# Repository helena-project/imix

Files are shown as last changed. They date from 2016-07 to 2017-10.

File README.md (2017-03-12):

imix
====

This open source, feature packed board is an all-in-one development kit for ultra 
low power Internet-of-Things research and prototyping. With a Cortex M4 microcontroller,
BLE/ANT and 802.15.4 radio modules, sensing, battery charging, and tons of I/O,
imix has everything you need to prototype and profile your next big IoT
breakthrough. Pair imix with the [Tock](http://github.com/helena-project/tock)
operating system to quickly develop secure embedded applications.

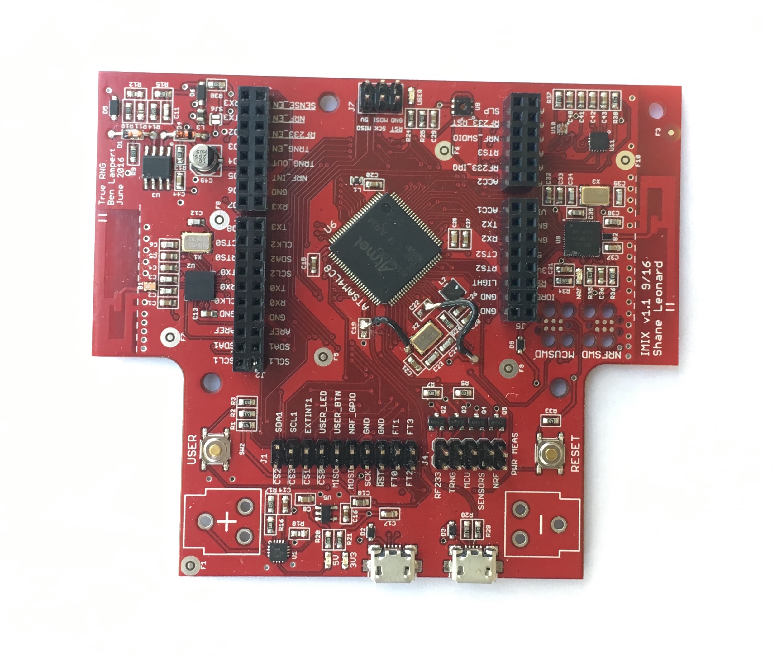
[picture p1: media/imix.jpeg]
imix


Features:
- Codeveloped with [Tock](http://github.com/helena-project/tock), a next-generation secure embedded operating system
- ATMEL SAM4L low power microcontroller with a Cortex M4 core
- NRF51422 radio with a Cortex M0 core for communication over Bluetooth Low Energy or ANT
- AT86RF233 radio for communication over 802.15.4
- Low power 3-axis linear accelerometer + 3-axis magnetometer
- Temperature + humidity sensor
- Digital light sensor
- Serial-to-USB and native USB ports
- Auditable True Random Number Generator
- Individually turn each subsystem completely on or off
- Easily measure the power consumption of each subsystem
- Compatible with most Arduino shields
- Integrated lithium polymer battery charger, and optional battery clips for the standard 18650 size

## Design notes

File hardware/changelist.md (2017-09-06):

v1.3:

* Removed ground plane near RF233 antenna
* Analog switch added as isolator for RF233 SPI and sense/NRF I2C
* Resistor added between FTDI_DTR and !RESET
* Battery charger configured for 500mA operation
* VHIGHSAMPLE from TRNG routed to ADCIFE6
* Reassigned A0-5 from ADCIFE1-6 to ADCIFE0-5
* GPIO8 reassigned to PA20
* LIGHT_INT reassigned to PC25
* Added KERNEL LED
* Overhaul of imix.lbr (documentation layers)
* Used P/N M20-9980545 for J4

v2.1:

* Form factor: now a 2.5"X4" rectangle
* Removed battery circuit
* FTDI chip powered correctly for low power
* Removed unnecessary resistors
* Renumbered some resistors and capacitors
* Changed pull-ups to 10K from 4.7K
* Removed unnecessary battery charger IC
* Removed all power gates except TRNG
* Removed header 1 and reassigned pins to the other headers
* Shunts instead of cutting traces
* Rearranged pinout on headers to simplify layout
* JST battery connector instead of battery clips
* Minor pinout changes on the MCU
* Cheaper diodes for power input
* Nicer more clicky buttons
* Power LEDs on the USB and nowhere else
* Trace width increased to 8 mil
* SPI header removed
* Debug USB moved to opposite side of board
* Mounting holes in a 2"X3.75" rectangle
* Extra SPI header removed
* Populate the sense resistors for TRNG
* Nicer silkscreen with TockOS and Imix urls

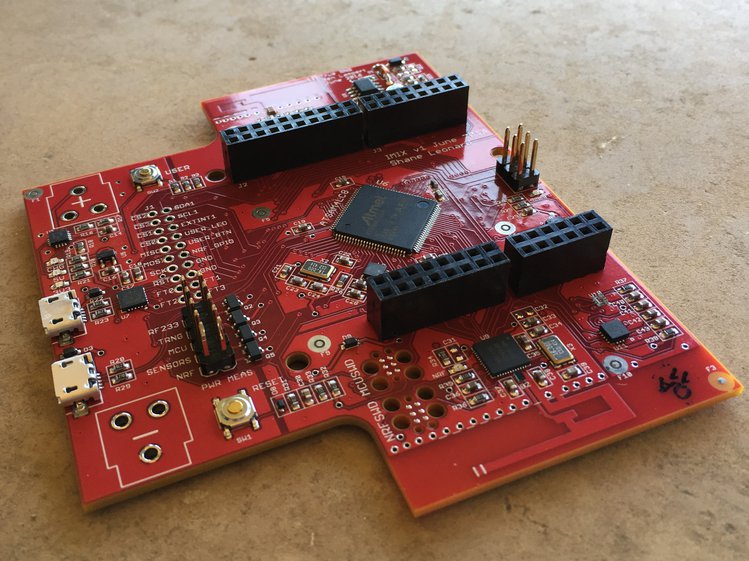
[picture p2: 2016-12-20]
media/imix-on-table.jpg

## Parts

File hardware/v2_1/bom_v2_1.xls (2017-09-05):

BOM: Imix
Assembly Part Number/Revision: 2.1
Customer / Company Name: Stanford University
Item # | Quantity per board | Manufacturer Part # | Do Not Install | Reference designators | Vendor | Vendor Part Number | Part description/ specs | Manfacturer
1 | 1 | 2450BM15A0015E |  | B1 | Digi-Key | 712-1576-1-ND | AT86RF232 AT86RF233 ATMEGA256 | JOHANSON TECHNOLOGY INC (VA)
2 | 1 | BALF-NRF01D3 |  | B2 | Digi-Key | 497-14944-1-ND | BALUN ULTRAMINI 5FLIPCHIP | STMICROELECTRONICS (VA)
3 | 19 | CC0603KRX7R7BB104 |  | C1,C4,C14,C15,C17,C19-C22,C27-C29,C31-C33,C40-C43 | Digi-Key | 311-1088-1-ND | CAP CER 0.1UF 16V X7R 0603 | YAGEO (VA)
4 | 3 | C0603C220J1GACTU |  | C2,C3,C11 | Digi-Key | 399-7874-1-ND | CAP CER 22PF 100V NP0 0603 | KEMET (VA)
5 | 4 | CC0603ZRY5V7BB105 |  | C5,C13,C16,C30 | Digi-Key | 311-1372-1-ND | CAP CER 1UF 16V Y5V 0603 | YAGEO (VA)
6 | 6 | C1608C0G1H090D080AA |  | C6,C12,C23,C24,C34,C39 | Digi-Key | 445-5047-1-ND | CAP CER 9PF 50V C0G 0603 | TDK CORPORATION (VA)
7 | 4 | GRM188R71E474KA12D |  | C7,C44,C46,C47 | Digi-Key | 490-3291-1-ND | CAP CER 0.47UF 25V X7R 0603 | MURATA ELECTRONICS (VA)
8 | 2 | CL10B475KQ8NQNC |  | C8,C25,C48 | Digi-Key | 1276-2087-1-ND | CAP CER 4.7UF 6.3V X7R 0603 | SAMSUNG ELECTRO-MECHANICS AMERICA, INC (VA)
9 | 1 | EEE-1EA100WR |  | C10 | Digi-Key | PCE3895CT-ND | CAP ALUM 10UF 20% 25V SMD | PANASONIC ELECTRONIC COMPONENTS (VA)
10 | 1 | CL10A106MQ8NNNC |  | C18 | Digi-Key | 1276-1119-1-ND | CAP CER 10UF 6.3V X5R 0603 | SAMSUNG ELECTRO-MECHANICS AMERICA, INC (VA)
11 | 1 | C1608X5R0J685K080AB |  | C26 | Digi-Key | 445-7490-1-ND | CAP CER 6.8UF 6.3V X5R 0603 | TDK CORPORATION (VA)
12 | 2 | CL10C102JB8NFNC |  | C35,C38 | Digi-Key | 1276-2170-1-ND | CAP CER 1000PF 50V NP0 0603 | SAMSUNG ELECTRO-MECHANICS AMERICA, INC (VA)
13 | 1 | GCM188R71H473KA55D |  | C36 | Digi-Key | 490-4934-1-ND | CAP CER 0.047UF 50V X7R 0603 | MURATA ELECTRONICS (VA)
14 | 1 | CL10B222KB8SFNC |  | C37 | Digi-Key | 1276-1992-1-ND | CAP CER 2200PF 50V X7R 0603 | SAMSUNG ELECTRO-MECHANICS AMERICA, INC (VA)
15 | 2 | 1N759A TR |  | D1,D4 | Mouser | 610-1N759A | Zener Diodes 12V .5W | CENTRAL SEMICONDUCTOR
16 | 8 | MBR0530 |  | D2-D9 | Digi-Key | MBR0530CT-ND | DIODE SCHOTTKY 30V 500MA SOD123 | FAIRCHILD SEMICONDUCTOR (VA)
17 | 1 | S2B-PH-SM4-TB |  | J1 | Digi-Key | 455-1749-1-ND | CONN HEADER PH SIDE 2POS 2MM SMD | JST SALES AMERICA INC.
18 | 1 | PPPC102LFBN-RC |  | J2 | Digi-Key | S6106-ND | CONN HEADER FEM 20POS.1" DL GOLD | SULLINS CONNECTOR SOLUTIONS
19 | 2 | PPPC082LFBN-RC |  | J3,J5 | Digi-Key | S7111-ND | CONN HEADER FMAL 16PS.1" DL GOLD | SULLINS CONNECTOR SOLUTIONS
20 | 1 | M20-9980545 |  | J4 | Digi-Key | 952-2380-ND | 2X5POS DIL VERTICAL PIN HEADER | HARWIN INC
21 | 1 | PPPC062LFBN-RC |  | J6 | Digi-Key | S7109-ND | CONN HEADER FMAL 12PS.1" DL GOLD | SULLINS CONNECTOR SOLUTIONS
22 | 1 | BLM18HE152SN1D |  | L1 | Digi-Key | 490-5216-1-ND | FERRITE BEAD 1.5 KOHM 0603 1LN | MURATA ELECTRONICS (VA)
23 | 1 | LQH3NPN220MJ0L |  | L2 | Digi-Key | 490-5350-1-ND | FIXED IND 22UH 510MA 600 MOHM | MURATA ELECTRONICS (VA)
24 | 1 | LBR2012T100K |  | L3 | Digi-Key | 587-2045-1-ND | FIXED IND 10UH 150MA 360 MOHM | TAIYO YUDEN (VA)
25 | 3 | LTST-C191KFKT |  | LED1,LED4 ,LED5 | Digi-Key | 160-1445-1-ND | LED ORANGE CLEAR 0603 SMD | LITE-ON INC (VA)
26 | 2 | LTST-C193TBKT-5A |  | LED2,LED3 | Digi-Key | 160-1827-1-ND | LED BLUE CLEAR 0603 SMD | LITE-ON INC (VA)
27 | 10 | RC0603JR-0710KL |  | R1-R3,R6-R8,R16,R18,R25,R26 | Digi-Key | 311-10KGRCT-ND | RES SMD 10K OHM 5% 1/10W 0603 | YAGEO (VA)
28 | 5 | RC0603JR-07220RL |  | R4,R5,R17,R19,R24 | Digi-Key | 311-220GRCT-ND | RES SMD 220 OHM 5% 1/10W 0603 | YAGEO (VA)
29 | 3 | ERA-3AEB103V |  | R9,R10,R13 | Digi-Key | P10KDBCT-ND | RES SMD 10K OHM 0.1% 1/10W 0603 | PANASONIC ELECTRONIC COMPONENTS (VA)
30 | 1 | RC0603JR-07150KL |  | R11 | Digi-Key | 311-150KGRCT-ND | RES SMD 150K OHM 5% 1/10W 0603 | YAGEO (VA)
31 | 1 | RC0603JR-0730KL |  | R12 | Digi-Key | 311-30KGRCT-ND | RES SMD 30K OHM 5% 1/10W 0603 | YAGEO (VA)
32 | 1 | RC0603JR-072M2L |  | R14 | Digi-Key | 311-2.2MGRCT-ND | RES SMD 2.2M OHM 5% 1/10W 0603 | YAGEO (VA)
33 | 1 | RC0603JR-07160KL |  | R15 | Digi-Key | 311-160KGRCT-ND | RES SMD 160K OHM 5% 1/10W 0603 | YAGEO (VA)
34 | 4 | RC0603JR-0727RL |  | R20-R23 | Digi-Key | 311-27GRCT-ND | RES SMD 27 OHM 5% 1/10W 0603 | YAGEO (VA)
35 | 5 | SPC02SYAN | DNI | SHUNTS | Digi-Key | S9001-ND | 2 POS 0.1" CONN JUMPER SHORTING GOLD FLASH | SULLINS CONNECTOR SOLUTIONS
36 | 2 | PTS645SM43SMTR92 LFS |  | SW1,SW2 | Digi-Key | CKN9112CT-ND | Blue Tactile Switch SPST-NO Top Actuated Surface Mount 12V 0.5A | C&K COMPONENTS (VA)
37 | 2 | 74LVC4066BQ |  | U1,U13 | Digi-Key | 568-3019-1-ND | 4 channel bilateral switch | NEXPERIA USA INC.
38 | 1 | AT86RF233-ZUR |  | U2 | Digi-Key | AT86RF233-ZURCT-ND | IC RF TXRX+MCU 802.15.4 32-VFQFN | ATMEL (VA)
39 | 1 | TLV3202AIDR |  | U3 | Digi-Key | 296-34773-1-ND | IC COMPARATOR RRI DUAL 8SOIC | TEXAS INSTRUMENTS (VA)
40 | 1 | LM358DT |  | U4 | Digi-Key | 497-1591-1-ND | IC OPAMP GP 1.1MHZ 8SO | STMICROELECTRONICS (VA)
41 | 1 | TPS78233DDCR |  | U5 | Digi-Key | 296-24059-1-ND | IC REG LDO 3.3V 0.15A 5SOT | TEXAS INSTRUMENTS (VA)
42 | 1 | ATSAM4LC8CA-AU |  | U6 | Digi-Key | ATSAM4LC8CA-AU-ND | IC MCU 32BIT 512KB FLASH 100TQFP | ATMEL
43 | 1 | FT231XQ-R |  | U7 | Digi-Key | 768-1128-1-ND | IC USB SERIAL FULL UART 20QFN | FTDI (VA)
44 | 1 | SI7021-A20-GM |  | U8 | Digi-Key | 336-3140-5-ND | IC TEMP SENSOR RH 3% 6DFN | SILICON LABORATORIES INC
45 | 1 | nRF51422-QFAC-R7 |  | U9 | Mouser | 949-NRF51422-QFAC-R7 | RF System on a Chip - SoC QFN48pkt 256kB Flash 32kB RAM XLR3 | NORDIC SEMICONDUCTOR ASA (VA)
46 | 1 | ISL29035IROZ-T7 |  | U10 | Digi-Key | ISL29035IROZ-T7CT-ND | IC PROXIMITY SENSOR AMB LT 6ODFN | INTERSIL (VA)
47 | 1 | FXOS8700CQR1 |  | U11 | Digi-Key | FXOS8700CQR1CT-ND | SENSOR XTRINSIC 6-AXIS QFN | FREESCALE SEMICONDUCTOR - NXP (VA)
48 | 1 | TPS61041DBVR |  | U12 | Digi-Key | 296-12686-1-ND | IC LED DRIVER RGLTR DIM SOT23-5 | TEXAS INSTRUMENTS (VA)
49 | 1 | SIP32401ADNP-T1GE4 |  | U14 | Digi-Key | SIP32401ADNP-T1GE4CT-ND | 1 channel load switch | VISHAY ELECTRONICS
50 | 2 | 10118192-0001LF |  | USB1,USB2 | Digi-Key | 609-4613-1-ND | CONN USB MICRO B RECPT SMT R/A | AMPHENOL FCI (VA)
51 | 3 | 405C11A16M00000 |  | X1,X2,X3 | Digi-Key | CTX834CT-ND | CRYSTAL 16.0000MHZ 10PF SMD | CTS-FREQUENCY CONTROLS

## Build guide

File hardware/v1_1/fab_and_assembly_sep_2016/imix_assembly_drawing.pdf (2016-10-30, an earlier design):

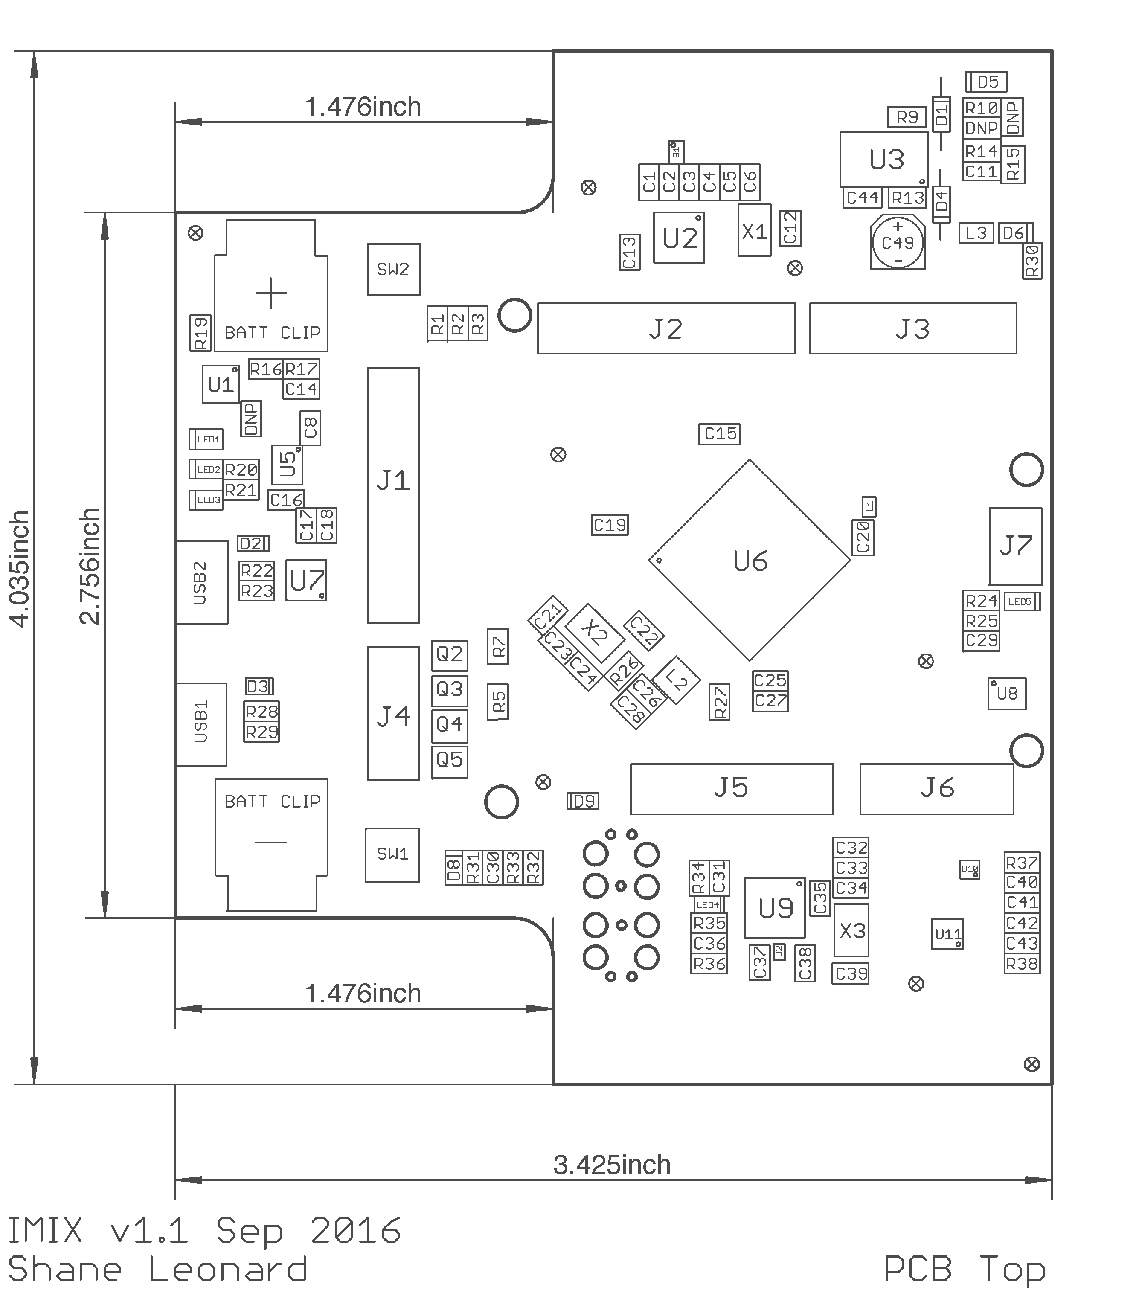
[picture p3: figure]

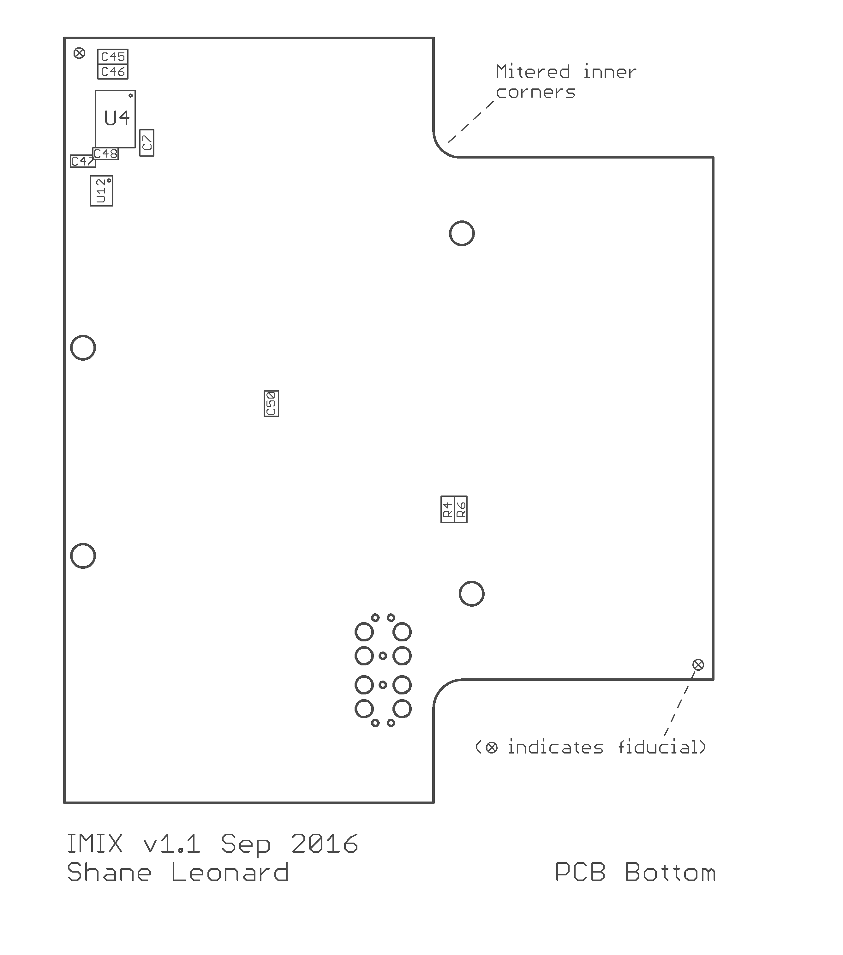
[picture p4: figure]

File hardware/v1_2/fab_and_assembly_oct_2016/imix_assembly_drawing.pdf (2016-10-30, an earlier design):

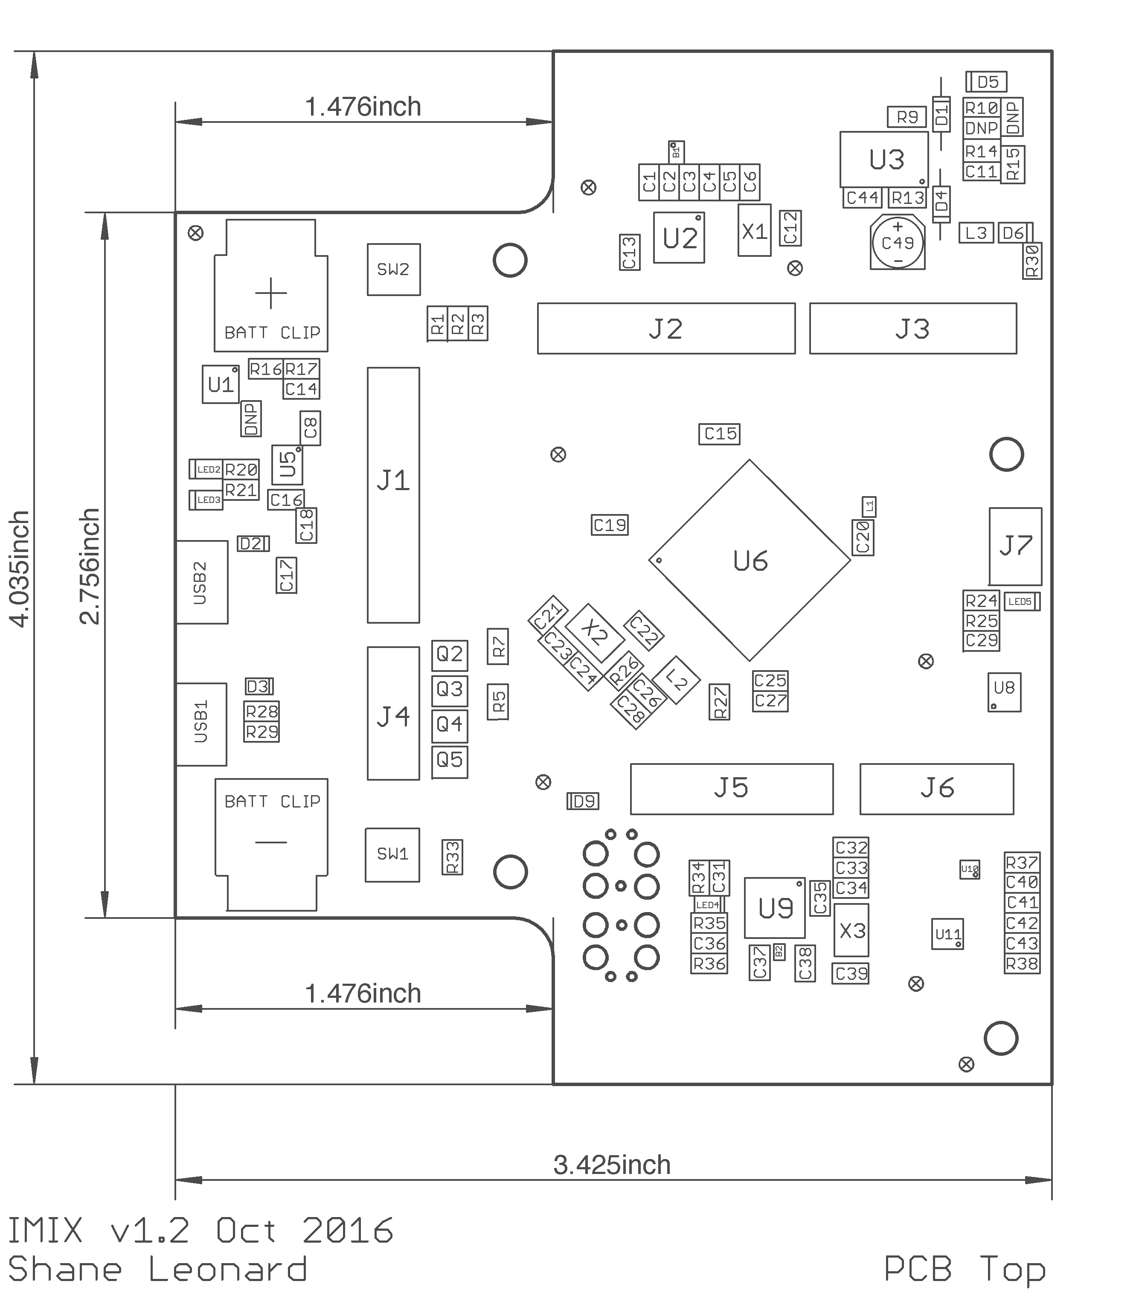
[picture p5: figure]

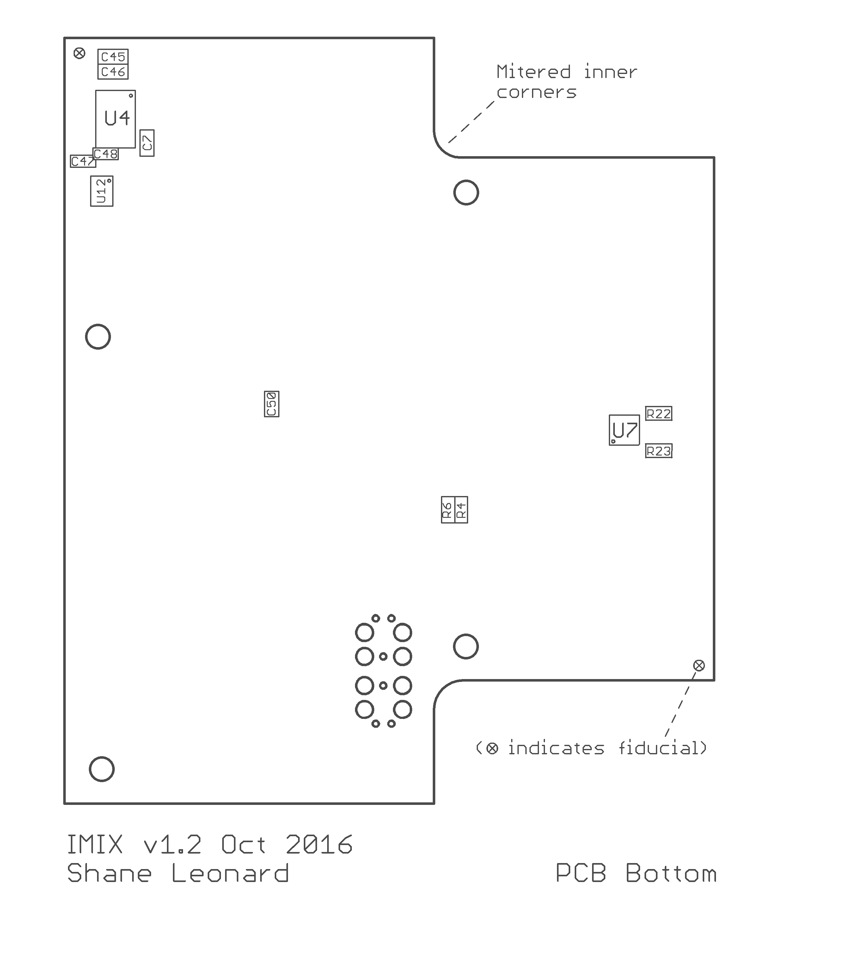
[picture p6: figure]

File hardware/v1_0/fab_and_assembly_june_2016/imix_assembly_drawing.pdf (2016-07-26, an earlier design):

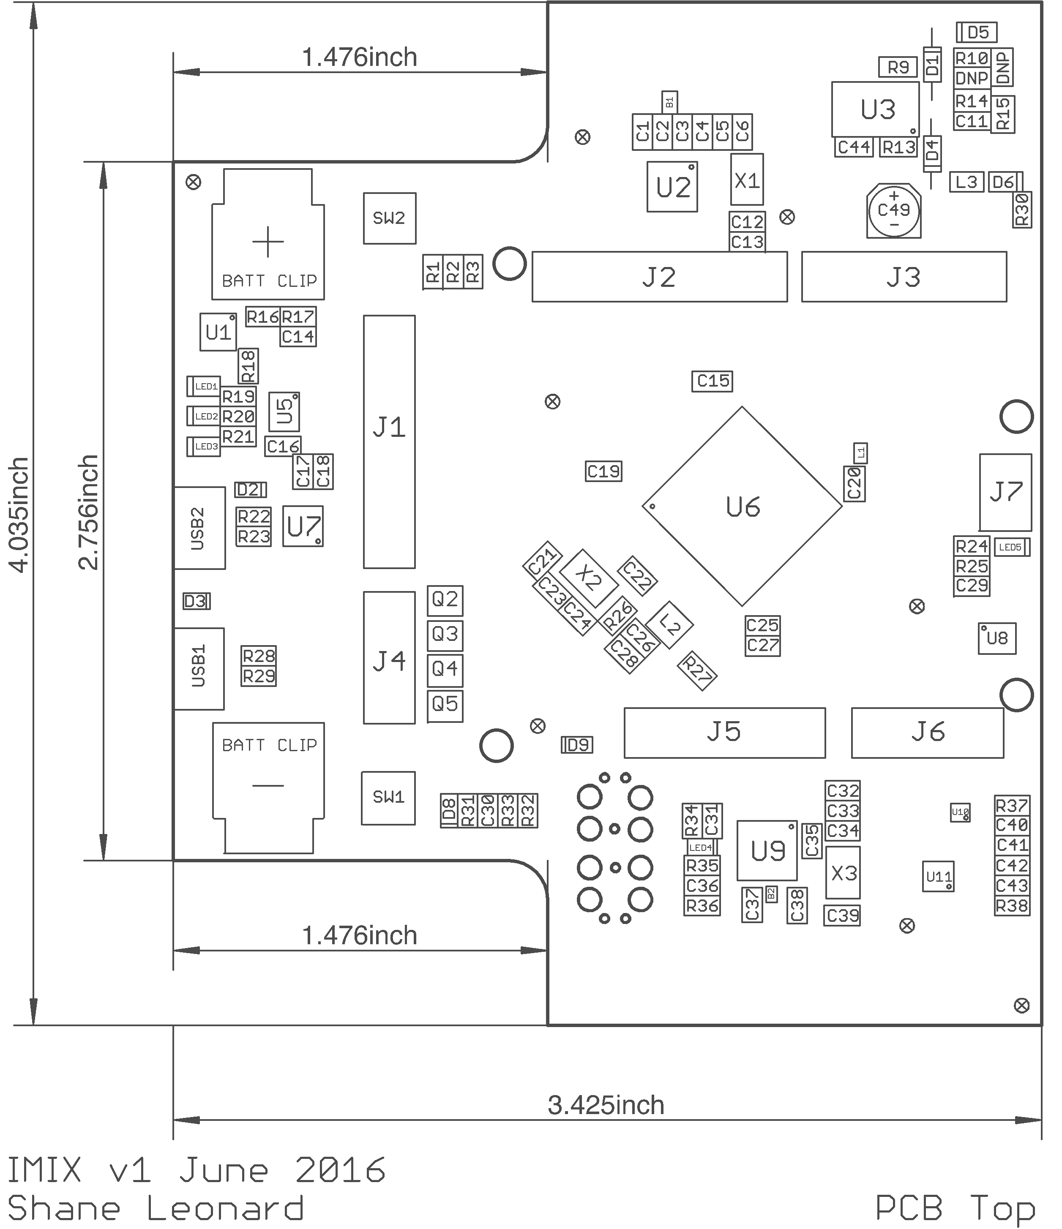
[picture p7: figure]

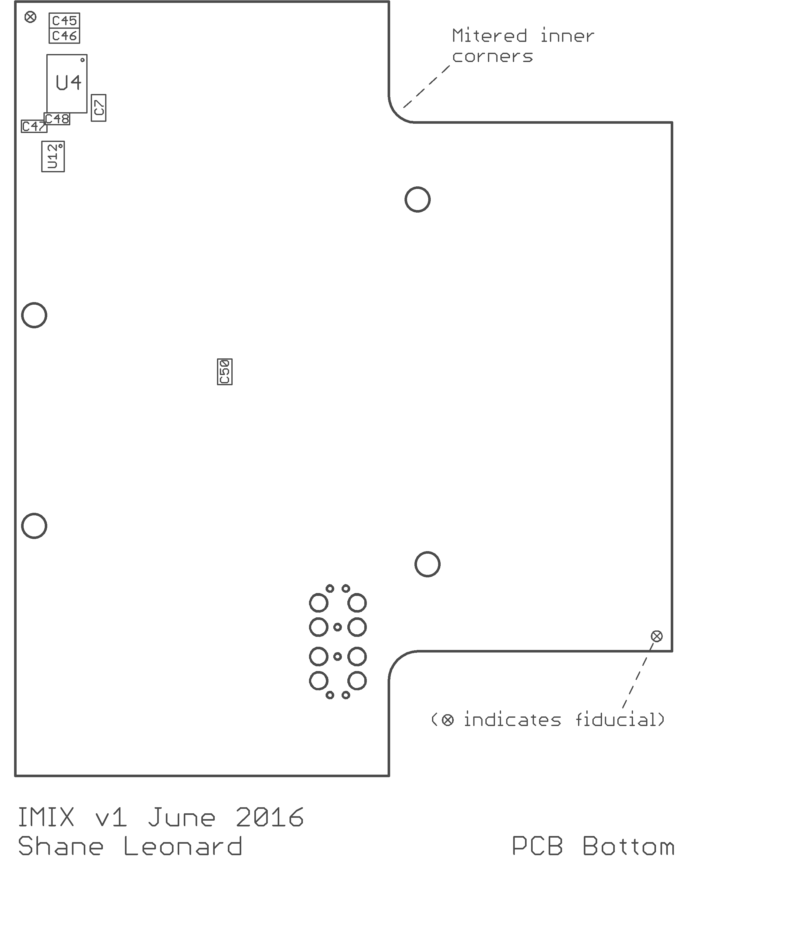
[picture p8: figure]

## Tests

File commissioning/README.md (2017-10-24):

Commissioning
=============

This folder contains resources for setting up new imix boards.

Commissioning Overview
----------------------

The commissioning process covers a few things:

1. Set the FTDI device name and serial number.
2. Flashes the boatloader on to the SAM4L.
3. Sets the `board`, `id` and `appaddr` attributes in the flash of the SAM4L.
4. Flashes the `imix` TockOS kernel on the SAM4L.
5. Flashes the "blink" app on the SAM4L.
6. Flashes the serialization code on the nRF51 and programs the ID.

Initial software installation
-----------------------------

To initialize a Hail board:

 * Connect USB to the board
 * Connect a JTAG programmer to the SAM4L
 * Run `./commission_new_imix.sh c098e514xxxx` where the `xxxx` should be
   replaced with a unique device ID
 * Connect a JTAG programmer to the nRF51822
 * Hit `any key` to continue the script

Be sure to label the board with a sticker so that the user knows what the
device's BLE address is.

`ftx_prog`
----------

The `ftx_prog` executable comes from here:
https://github.com/richardeoin/ftx-prog.
It was built for linux amd64, so if the executable doesn't work for you,
you will have to recompile it for your platform.

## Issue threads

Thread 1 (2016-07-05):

FT231 Reset Functionality

alevy, 2016-07-05:
On the Firestorm, the FT231's DTR pin is tied to logic that allows flipping the power to the board. On the Imix currently _DTS_ is tied to the SAM4L reset. Is that right? Isn't DTS an input pin for the FTDI chip?

shaneleonard, 2016-07-05:
You are correct, thank you for catching this! I've updated the connections so that DTR is now connected to reset.

Closed 2016-07-05.

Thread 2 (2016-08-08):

Power LEDs don't come on

alevy, 2016-08-08:
## Cause

This issue is due to a lack of bypass capacitance on the output of the bq24230 (the battery charger and power path IC).
Without a high capacitance on the output, the IC is unstable and does not produce a regulated output voltage.
## Workarounds

The general principle is to add a suitable bypass capacitor to the output of the bq24230 (U1).
There are several ways to achieve this:
1. Plug in the device. With the board face up and oriented like a capital 'T', touch
   the leads of a large (4.7uF to 47uF) capacitor from GND to the upper pad of either R19 or R20.
   The LEDS should immediately turn on, and the 3.3V power rail should be working.
   Note that because the capacitor is not permanently attached, the power supply may
   occasionally become unstable again, and the process must be repeated.
2. (recommended) Remove R18 and R19. With the board face up and oriented like a capital 'T',
   solder a large (4.7uF to 47uF) capacitor from the rightmost pad of R18 to the upper pad of R19.
   An 0603 capacitor is ideal if possible, since it happens to be the perfect dimensions to bridge the gap.
3. (untested) If no suitable capacitor is on hand, it should be possible to directly apply an input
   voltage that bypasses the power path IC. Solder a wire to the upper pad of R19 (R19 can be removed if desired).
   The input voltage at this point should be between 3.4 V and 5.5 V. The chances of this method succeeding are
   higher if the bq24230 (U1) is removed, and a 0.1uF to 1uF bypass capacitor is applied on the input rail.

shaneleonard, 2016-08-11:
@alevy Were you able to test any of these workarounds yourself?

alevy, 2016-08-11:
@shaneleonard I have not. I don't have a workbench nearby me, but I'll head into a hacker space sometime soon. I was able to get the LED powered through the JLink connection though -- e.g. when I connect the programmer to and configure it to power the MCU, the LED lights up

shaneleonard, 2016-08-11:
@alevy FWIW, decent soldering irons are $10 at RadioShack, if that's more convenient than going to a hacker space. Otherwise, I could send you one of the boards that I've fixed up. If you were able to power the processor through the JLink, then the only thing preventing you from being able to program the MCU is D8, which shouldn't be too hard to remove with a soldering iron and a reasonably steady hand. When I get the chance, tonight I'll upload my openocd script and a simple blinky app.

shaneleonard, 2016-08-12:
@alevy Uploaded detailed 'getting started' instructions. It turns out that D8 is actually inconsequential. Please take a look at issue #3 and the README for the correct procedure. I've verified this procedure with a totally fresh board, so it should work for you. No need for anything except a JLink and a razor blade.

alevy, 2016-08-12:
Awesome. I'll try it out ASAP

alevy, 2016-08-13:
@shaneleonard I'm able to program the board with your blink app and it works!!

For the record, to get started I need:

  1. Plug USB one of the ports (it doesn't have to be plugged into a power source on the other end_

  2. Provide power from JLink

From that point I can either remove the USB cable and it works fine, or provide power from the USB and stop powering from the JLink. As though the USB + Jlink connectivity is only need to jump-start the process.

alevy, 2016-08-13:
The FTDI chip isn't showing up, but I assume that's related to the short

shaneleonard, 2016-08-13:
@alevy Yay! Did you need to cut the trace? I'm still not exactly sure what the issue is with the FTDI chip. I have one board which I had removed the FTDI from, and the short disappeared, so I have a feeling that there may actually be a different issue with it than I originally thought. How do you configure the JLink to provide power?

alevy, 2016-08-13:
I did have to cut the trace.
I'm not sure how to do it from openocd, but from JLinkExe just use the command `power on`.

Closed 2016-11-18.

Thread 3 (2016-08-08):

MCU Reset line is permanently low

alevy, 2016-08-08:
## Cause

Reset line on the FTDI side is shorted to ground in an internal layer. :(
## Workaround

Cut the trace as shown below so that the FTDI side is disconnected from the MCU side. This will allow the MCU to be programmed using a JLink.

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

shaneleonard, 2016-08-12:
@alevy It turns out this issue was not due to the diode, but actually due to RESET being shorted to ground near the FTDI chip. The internal ground plane near the FTDI does not have the proper isolation, so it appears to have shorted to the RESET vias. Fortunately, however, this means that the board can actually be completely programmed and powered without adding or removing any components. All that is needed is to cut the trace as shown above.

Closed 2016-11-18.

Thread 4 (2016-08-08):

Tag Connect programmer cannot drive the reset line

alevy, 2016-08-08:
## Cause

It is suspected that the solder on the pads of the connector negatively impact the connection enough to
prevent the programmer from sinking enough current to drive the reset line low.

## Workaround

Currently unknown.

alevy, 2016-08-08:
Is it possible to validate this somehow? E.g. by measuring how much current can be drawn through the pad?

FWIW, this seems to _not_ be an issue with the NRF's programming -- at least, I can successfully connect to that chip using my debugger.

alevy, 2016-08-08:
Side question, is this issue dependent somehow on #3? In particular, I haven't yet removed D8 -- will that potentially effect the behavior I see when trying to use the programmer pads?

shaneleonard, 2016-08-11:
@alevy Were you able to connect to the NRF on this revision of Imix?

shaneleonard, 2016-08-11:
@alevy I tried using the same programmer to flash one of my original boards, and encountered the same error. Therefore I suspect that it's actually an issue with my programmer or the toolchain, since the board I'm testing worked earlier this year. I will try using openocd instead of the Atmel toolchain and see what happens. If you are able to resolve issue #2, can you try programming your board and see if it works? You still need to remove D8 because it affects the voltage on the reset line

shaneleonard, 2016-08-11:
@alevy Turns out, the error was Atmel Studio incorrectly configuring the JLink. Using openocd I was able to program the board.

alevy, 2016-08-11:
@shaneleonard I _was_ able to connect to the NRF on this revision of Imix but was not able to connect to the SAM4L - kept getting errors from JLinkExe about not being able to reset the chip. If you were able to though, my guess is that error has to do with the other issues on the board, which I haven't resolved on mine with your workarounds.

Could you post your openocd config files somewhere (this repo) if/when you have a chance? Would be good to switch to it from JLink (since it's open source and easier to install).

Closed 2016-08-11.

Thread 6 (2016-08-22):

Add Bill of Materials to repo

brghena, 2016-08-22:

shaneleonard, 2016-08-24:
Uploaded the BOM I had sent to the manufacturer. There were several minor changes to the BOM during the manufacturing process, so I will update these changes soon.

Closed 2016-08-24.

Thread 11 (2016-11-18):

Re-enable RF233 enable pin

alevy, 2016-11-18:
In the current revision, the RF233 enable pin is tied to ground because of an original misdiagnosis of #7. Since that's now fixed we should re-establish the SAM4L's control over the RF233's enable pin.

  - [x] Test that controlling the enable pin from the SAM4L no longer browns out the SAM4L

  - [ ] ~~If it works, remove the trace/resistor grounding the enable pin.~~

alevy, 2016-12-22:
In my experiments with an older board --- one without RF233_EN tied to ground, but with the power-related patch wires --- this still does not work. I believe @shaneleonard thinks this is related to the problem in #12 and the same fix might apply.

shaneleonard, 2017-03-12:
Closing as this issue is now tracked by #14

Closed 2017-03-12.

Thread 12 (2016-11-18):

RNG enable browning out sam4l

alevy, 2016-11-18:
From my test, enabling the RNG (by clearing PC19 on the SAM4L) browns out the SMA4L on a patched board of the most recent revision. @shaneleonard any suggestions on how to diagnose further? It might be worth you trying replicate as well, since it's definitely plausible I'm doing something wrong (I just enabled PC19 as an output then cleared it. If I set it instead, no problems--but also no RNG of course).

alevy, 2016-11-21:
I actually think this may have happened because the my power supply (a passive USB hub) wasn't supplying enough power. It should be able to do up to 100uA, which very well might be less than the two MCUs + the RF233 + the RNG + the sensors on boot. I'm going to try and test this today.

alevy, 2016-11-21:
OK, I'm able to run the RNG and continue with the OS as normal as long as I'm powering the board from two USB sources (currently the FTDI as well as power through the JLink). Ideally I would try this with an independently powered USB hub, but I don't have one on me. I should also try this with a large power supply...

However, this doesn't seem like great behavior if we can't power the board from a typical USB port.

@shaneleonard does this seem like my analysis is reasonable? If so, would it make sense to stick a current limiting resistor or something inline with the RNG power supply?

/cc @kwantam

ppannuto, 2016-11-21:
I thought you had to be able to supply 500 mA to be USB compliant (even a
"passive hub" ?).

Not that lowering the power draw is a bad idea, but it may also be good to
have the FTDI chip negotiate for more power:
http://www.ftdichip.com/Support/Documents/TechnicalNotes/TN_113_Simplified%20Description%20of%20USB%20Device%20Enumeration.pdf
 (from
http://electronics.stackexchange.com/questions/5498/how-to-get-more-than-100ma-from-a-usb-port
 )

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

shaneleonard, 2016-11-21:
So the device actually regulating the power is the BQ24230, which is currently configured to be in USB 100 mA mode. By setting the EN1 pin high instead of low, it can be used for 500mA (the BQ24230 doesn't actually negotiate for more power--like Pat said, that's the FTDI's job--all it does is limit the power input). According to Ben, the RNG draws a 30 mA average current, but it looks like it actually spikes above that level at some points. I would guess that the average current draw is <100mA but the peak current draw is >100mA.

So it looks like I should change EN1 on the BQ24230 to be high so that it limits the input current to 500mA instead of 100mA, and the SAM4L needs to get the FTDI chip to negotiate for more power. This also means that the RNG won't work with the native USB port (eg the non-FTDI one)  until the Tock native USB driver is capable of device enumeration/negotiation for more power.

For now, there are a couple of workarounds. First, if the RNG only requires _slightly_ more than 100mA, the BQ24230 might let it slide (it has some built in wiggle room for charging capacitive loads). It's possible that just setting the FTDI chip to negotiate for 500mA could be enough to fix the problem.

Otherwise, if you're able to directly power the 3V3 line with something capable of >100mA (at 3.3V, NOT 5V), then you are bypassing the regulator entirely, and so the input current limits won't apply. Note that it's necessary to power VCC_3V3, not just VCC_MCU_3V3 (what the JLink powers), because otherwise the RNG has no power.

shaneleonard, 2016-11-21:
Also @ppannuto is right that every USB-compliant host must be capable of 500mA.

shaneleonard, 2016-11-21:
Another possible workaround is to power the board from the battery input, because the BQ24230 doesn't limit the input battery current

ppannuto, 2016-11-21:
I think in practice you can just set the BQ to 500 mA mode and everything
will work out.

Very few USB ports actually limit downstream stuff to 100 mA nowadays.

On Mon, Nov 21, 2016 at 5:33 PM shaneleonard <notifications@github.com>
wrote:

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

alevy, 2016-11-21:
Just setting the FTDI to negotiate 500mA doesn't seem to do the trick (which seems like it's because of the BQ24230 limiting @shaneleonard pointed out).

It's true that USB-compliant hosts should be able to provide 500mA, but hubs are only required to provide 100mA. What is a hub? Undefined... the plugs on your desktop may be hubs, or they may be directly connected to the host.

Ideally (this is purely from a usability perspective), you should be able to run the board on any of the power sources, including from a non-FTDI USB. If it's possible to easily adapt the hardware to a 100mA power constraint (e.g. a current limiting resistor on the RNG or a capacitor to smooth out peak consumption) that's great. If not, as long as we have a software workaround that's probably good enough to move forward.

alevy, 2016-11-21:
Is fixing the BQ something I can test myself?

alevy, 2016-11-21:
BTW, @shaneleonard setting the FTDI to negotiate more power is done by programming the user-flash on the FTDI chip from a host machine (using a windows program called FT_PROG). I don't think it's possible from the SAM4L.

kwantam, 2016-11-21:
As @alevy says, the right solution is to modify the dc/dc converter's design so that its inrush current is limited to less than 100 mA. I'll have to take a look at our schematic and the datasheet for the part we're using before I can make a specific suggestion, but in general there's no reason that keeping the converter's peak current below 100 mA is tough.

Ideally, in the long term, I'd like to replace the controller we've got now with something cheaper. The TI product line we're using is optimized for "drop it in and don't worry," but we can easily do better in terms of cost and performance with a bit more thought.

ppannuto, 2016-11-21:
@alevy to test the BQ, need to set EN2=0, EN1=1 ( http://www.ti.com/lit/ds/symlink/bq24230.pdf ). EN1 is pin 6, which unfortunately will be a hard trace to cut:
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

@shaneleonard one nice habit for the future is the eliminate traces between pads. For this reason, and also so because they tend to encourage solder bridges, which, while technically not wrong, make debugging board fab hard b/c you have to recognize that that bridge is okay.

@shaneleonard also, can you include the `.brd` and `.sch` files in the fab directories in the future? It's nice to have a snapshot of those so you can open a digital copy of exactly that rev of a board.

alevy, 2016-11-21:
Oh, btw, when I feed enough power to the board I can successfully read random looking bits of the RNG. I'm not rigorously measuring time or anything, so the bits I'm getting are probably not exactly random, but definitely close enough to be sure the hardware does what it's supposed to do once we turn it on.

shaneleonard, 2016-11-21:
@ppannuto Thanks for the tip, I had corrected the 'traces between pads' mistake on the SAM4L but had missed it on the BQ24230. Would it be valuable to have a DNP pullup/pulldown on EN1 and EN2, or is it better to just tie EN1 high?

shaneleonard, 2016-11-21:
@ppannuto I'll make sure to do `.brd` and `.sch` snapshots moving forward

shaneleonard, 2016-11-21:
@alevy Does feeding enough power like you have with the RNG solve the RF233 brown-out as well?
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
shaneleonard, 2017-02-13:
I think you're right, this would be a good way to go. Also, having active-high logic on the enable pins helps with the solution Riad and I worked out for the isolation issue as well. Since my next revision is a small run, I'll try it with these parts and make the switch if it works. At the very least, I know now for sure that the issue was indeed a brownout, and the solution was limiting the slew-rate.

kwantam, 2017-02-13:
The concern with using a part like the SIP32401 is that it's overkill and ends up increasing the BOM cost (the transistor plus resistors should be a couple pennies, while the above cited part is more like 15 cents at thousand quantity). This is not a particularly hard problem to solve with discretes. But if board space or simplicity is more important than cost, by all means go for it.

kwantam, 2017-02-13:
Shane, do you have a schematic of the current setup? It's not clear to me why there would be any trouble getting the gate all the way to Vdd.

ppannuto, 2017-02-13:
$0.02 vs $0.15 for components on a $100 Board is in the noise. We've sunk a
ton of time into diagnosing power issues on this board already. A known
good solution is *way* more valuable IMO at this point.

On Mon, Feb 13, 2017 at 4:25 PM Riad S. Wahby <notifications@github.com>
wrote:

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

kwantam, 2017-02-13:
Like I said, other things might take priority and spending the extra money could be the right decision in this case. Still, you must be aware that this maxim does not universalize (unless you're excited for a $100 board to become a $500 board).

In any case, there's no logical connection from "we've spent a lot of time diagnosing" to "therefore use a new part." There *would* be a connection if the time had been spent *debugging* a fix, but that's not the case---or if it is, I'm not sure why, since I pointed out that this was the issue and suggested a correct fix months ago.

ppannuto, 2017-02-13:
Sure, going from $1 -> $15 is not the same. My argument is that going from
$0.01 -> $0.15 for something in quantity ~5 should not even be brought up
as a discussion for this board.

The connection is that Shane has tried a fix, and that fix did not work.
Rather than continuing to try more fixes, let's take the part that is known
to work correctly for this exact application and move on.

On Mon, Feb 13, 2017 at 5:15 PM Riad S. Wahby <notifications@github.com>
wrote:

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

shaneleonard, 2017-02-14:
I take the blame for the speed at which this fix has been implemented, as most of my time personally has been spent waffling on this very decision on whether to focus on a discrete fix or use an IC, and not very efficiently switching focus between the serial stuff/other power issues. All said and done, my intention in running these recent tests was to see for certain that our hypothesis was correct without spinning another board. I also wanted to fully characterize the discrete solution in order to evaluate it compared to another approach.

Therefore, I think the best course of action right now is to try the SIP32401 for the next small run, as it reduces the routing complexity in multiple ways and is likely to be a final solution. I can easily revert back to debugging the discrete approach if that's a total failure, so no harm done. Going down the discrete path gave me valuable insight into the issue, so I think it's fulfilled a purpose. Honestly much of the reason I've been slow to execute this has been my lack of experience in making decisions like this--I'm truly thankful for everyone's input, but it's also been a learning curve for me figuring out how to weigh all the conflicting opinions. In this case, I think BOM cost should be tackled as a separate concern, one which requires a much more holistic look at the board.

shaneleonard, 2017-02-14:
I will say that for me, routing complexity takes fairly high precedence here, because on a breakout board like this where basically everything is broken out, there isn't much flexibility.

alevy, 2017-02-14:
@kwantam and @ppannuto it sounds like we all agree that there is a case for saving on the BOM and that it _may_ apply here, or it may not. It certainly seems like for this next revision, where we're spinning only a relatively small number of boards, we should do whatever is most expedient for Shane to get right.

Especially in the question between a discrete IC and a handful of passives that would do the same thing, we can always go back and change our minds if the unit ecomonics cause to change our minds, since the board functionality ought to be basically the same.

I don't know what the right answer is, but it seems like @shaneleonard should just do the one he is most confident in for now.

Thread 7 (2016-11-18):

Capacitors not connected to Vcc

alevy, 2016-11-18:
The SAM4L pins 8 and 97 are not connected to VCC_MCU_3V3. They are instead connected to the decoupling capacitors C19 and C22 without being connected directly to the power net.

This results in a variety of strange behaviors. Essentially, certain peripheral banks in the MCU try to draw power from VDDIO, but instead they are drawing from the charge coincidentally stored in C19 and C22. When C19 and C22 are drained, things stop working.

This error happened because of a nuance with EAGLE. EAGLE should have caught this as a Design Rule error, but due to the specific way the footprint was made, it incorrectly assumed that all of the VDDIO pins were internally connected. Thus, once any of the VDDIO pins (8, 97, 87, or 88) were connected to power, it assumed all four were connected to power, and didn't generate the necessary airwires to connect each pin to power individually.

shaneleonard, 2016-11-18:
The commit 99e1496 fixes this issue, however it does not fix EAGLE's misinterpretation of the footprint. Need an additional commit to address that.

Closed 2016-11-21.

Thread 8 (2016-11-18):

RNG's VHIGHSAMPLE not connected to SAM4L

alevy, 2016-11-18:
In order for an application to decide when it's safe to sample the RNG, it needs to monitor the voltage coming out of DC/DC

shaneleonard, 2017-03-12:
Implemented in 2836455a6390641d6745d03461ea6e3cf5a8845d

Closed 2017-03-12.

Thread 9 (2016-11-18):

RF233 weak radio reception

alevy, 2016-11-18:
There is evidence that the radio signal for the RF233 is pretty weak. This might be due to interference from the RNG's ground plane.

shaneleonard, 2016-11-18:
Commit 99e1496 should be sufficient to fix this, but we are awaiting additional testing to confirm that this is the correct solution.

shaneleonard, 2017-02-13:
Tests are inconclusive as to how bad this issue is, but the weaker signal strength is still sufficient for development work.  Closing for now, may reopen if problem persists on next revision but it should be fixed.

Closed 2017-02-13.

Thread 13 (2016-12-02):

FTDI pulls reset low by default

alevy, 2016-12-02:
(I'm not sure there is anything great to do about this)

When I attach a terminal to the FTDI, DTR--which is connected directly to the SAM4L's RESET signal--is pulled low, and the board effectively halts. `stormloader` relies on this to be able to reset the board, so this behavior is identical on the Firestorm, but it's a huge bummer because it means that typical utilities for connect to a serial port (e.g. miniterm, minicom, screen, etc) don't work by default.

There are currently two workarounds I've found:

  1. `miniterm2.py` takes a `--dtr` argument which tells it to assert or de-assert the DTR signal. `miniterm2.py --dtr 0 /dev/ttyUSB0 115200` works for me. I'm not sure how to do this with other utilities.

  2. We can program the FTDI chip to invert the DTR signal, which would allow connecting through a terminal serial applications to work out of the box, _but_ the reset signal will be held low by default, so the board won't run.

How does Arduino manage this? Thoughts?

ppannuto, 2016-12-02:
Arudino manages this in hardware. It uses a DTR transition to trigger a
timer, so a reset pulse is emitted on a DTR transition, but the steady
state of DTR is ignored.

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

shaneleonard, 2017-02-13:
After testing with miniterm, Amit and I concluded that the current behavior is identical to `hail`, and I'm not planning to fix this for the next revision. Leaving it open and labeled as `wontfix` for further potential future research.

alevy, 2017-02-13:
@shaneleonard I agree with this assessment, I think it's fine. I'm closing.

shaneleonard, 2017-02-14:
@ppannuto If I AC-couple the DTR line to the RESET line (as Arduino does), would it be possible to get the behavior we want? It actually seems like a trivial fix (one capacitor), but I don't know if it would cause an undue overhaul in the tockloader or if it would break compatibility with Hail.

shaneleonard, 2017-04-28:
@ppannuto @alevy After some experiments, I found by that removing the reset pullup resistor and replacing the DTR-RESET resistor with a 1uF cap, the DTR can pull down the reset line when desired but the steady-state doesn't make a difference. I was able to successfully get a terminal with all different configurations of `miniterm` and `screen`. `tockloader listen` works correctly, so I'm assuming that the other tockloader functions will work if I use the bootloader. Unless there are any objections, I'm going to make this change.

shaneleonard, 2017-04-28:
I think we should replicate this design on Hail, by the way, since it fixes all of the undesired behavior.

ppannuto, 2017-04-28:
Interesting (and cool, nice work). My understanding is that Arduino adds the unbalanced resistors to lengthen the reset pulse. What does the reset pulse with just the cap look like (duration, especially below reset threshold?). The SAM4L datasheet (sec 42.10.1 RESET_N Timing) specifies a minimum pulse width of 10ns (which upon looking up is wonderfully short, so I suspect the coupling approach works well)

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
(I have just no idea what to make of that footnote though; would make me inclined to be comfortably longer than 10ns pulse)

alevy, 2017-04-29:
(this is pretty far out of my comfort zone, so I'm just listening with interest, not commenting)

ppannuto, 2017-05-01:
@shaneleonard could you grab a scope trace probing both sides (DTR and RESET_N) of the cap?

@brghena assuming that looks good, moving hail over to a cap probably a good improvement

shaneleonard, 2017-05-01:
Yeah, ran that experiment last night but forgot to snap a pic. When DTR transitions low, Reset immediately goes to 0V and exponentially rises with a rise time of about 80 ms (it's logic low for about 20 ms). When DTR transitions high (after Reset has resettled high), Reset spikes to 4.2V and decays back to 3.3V. I'll post the screenshot once I take it again.

shaneleonard, 2017-05-01:
The 1uF seems to be overkill, so if it's interesting, I can try a handful of values. I have 470nF and 100nF on hand (although 100nF didn't seem to work when I first tried it)

shaneleonard, 2017-05-01:
@ppannuto @brghena

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

This first picture shows DTR (yellow) transitioning high to low. The reset line (blue) is logic low for 8 ms (shown by the cursors)

shaneleonard, 2017-05-01:
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

Here is a zoomed-out version of the same capture.

shaneleonard, 2017-05-01:
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

Here, DTR is transitioning low to high. The reset line hits 4.24V at its maximum. Note that DTR doesn't have as sharp of a transition here.

shaneleonard, 2017-05-01:
Sorry for the cell-phone photography by the way. Couldn't find my flash drive to plug into the oscilloscope :/

shaneleonard, 2017-05-01:
@ppannuto @brghena Let me know if you would like me to repeat this for 470nF and/or 100nF.

ppannuto, 2017-05-01:
I think that cap choice is fine. Strictly speaking, it'd probably be good to double check in the datasheet that the reset pin is 4.2V tolerant and that this doesn't wear on the chip (o/w you'd need a clamping diode), but I suspect that's a low enough and short enough transient that it's not a big deal.

@brghena pointed out that when @daniel-scs gets USB support up an running, we can just incorporate that into the bootloader, and drop the FTDI chip altogether, so likely not worth propagating this change to hail. But since you're already spinning a new rev of imix, it looks good to me.

shaneleonard, 2017-05-01:
Datasheet doesn't mention reset being tolerant to a particular level, it just gives a flat 3.6V as the maximum operating voltage for the power domains and I/O. I can add a clamping diode.

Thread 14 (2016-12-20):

imix sensors power bugs tracking issue

alevy, 2016-12-20:
/cc @brghena

There are some un-diagnosed, rather serious interactions between RTS3 and the sensor power rail.

To replicate the problem, first install the Tock kernel from `master` or the `bugs/imix-power` branch of Tock:

```bash
$> cd ${TOCK_BASE}/boards/imix
$> make flash
```

The, install the imix sensors app:

```bash
$> cd ${TOCK_BASE}/boards/imix/apps/sensors
$> make flash
```

Finally, print the output from the app by running miniterm with `DTR` inactive (HIGH, attached to SAM4L reset) and `RTS` active (LOW, default):

```bash
$> miniterm2.py --dtr 0 --rts 1 /dev/ttyUSB0
```

You should get output resembling the following every second or so:

```
--- forcing DTR inactive
--- forcing RTS active
--- Miniterm on /dev/ttyUSB0  115200,8,N,1 ---
--- Quit: Ctrl+] | Menu: Ctrl+T | Help: Ctrl+T followed by Ctrl+H ---
Intensity: 281; Temperature: 23.64; Humidity: 19.60
```

However, if RTS is forced inactive (HIGH), there is no output:

```bash
$> miniterm2.py --dtr 0 --rts 0 /dev/ttyUSB0
```

Note that the console turns off hardware flow control entirely.

Finally, attaching a patch-wire between NRF_EN and GND (to force the NRF51 on) results in output all of a sudden.

### More symptoms

Under mainline kernel, with PB[06] assigned to RTS3, the voltage on NRF_EN and SENSOR_EN are never quite 0V or 3.3V. Instead they are closer to 0.06V and 2.2V, respectively. Removing the assignment of PB[06] to RTS3 (by either leaving it disabled or enabling it as an input, e.g.) results in either 0.04V or 3.2V (which seems reasonable?). The overall problem is not fixed, though, and in fact, it makes `--rts 1` stop working and the only way to get any output is to explicitly enable the NRF as well.

brghena, 2016-12-21:
**Finding**: the I2C lines are screwed up while the nRF is power-gated because they are not isolated

### Initial testing

Following the steps above on your branch (commit: efd845) with:
 * `PB[06].configure(Some(A));`
 * Power over USB from a high-current USB port
 * miniterm.py on Ubuntu with `--dtr 0`
 * nRF programmed with [low power app](https://github.com/helena-project/tock-nrf-serialization/tree/master/nrf51822/apps/low_power)
 * Default state of `!NRF_PWR_EN` net

Running miniterm.py with `--rts 1` and `--rts 0` both result in the sensors app printing data correctly. I have checked that RTS actually changes values. I have tried non-high-current USB ports. Running off of a power supply I see that the board draws 13 mA (without USB attached). The `!NRF_PWR_EN` net is 3.3 V and the `VCC_NRF_3V3` net is 2.8 V. The results are the same on both Imix boards at Michigan.

I cannot directly replicate your results with this setup. I find the RTS line to have no impact on the sensors app.

### Testing nRF enable

In these tests, Imix is powered through USB (from a high-current USB port) and `!NRF_POWER_EN` is tied to different voltages.

Running the low power app on the nRF51822:
 * Tied to GND: `VCC_NRF_3V3` = 3.3 V
 * Tied to 3v3: `VCC_NRF_3V3` = 2.8 V
 * Tied to 5v: `VCC_NRF_3V3` = 0 V

Running the tock-nrf51822-serialization-sdk11-s130-uart-conn app on the nRF51822:
 * Tied to GND: `VCC_NRF_3V3` = 3.3 V
 * Tied to 3v3: `VCC_NRF_3V3` = 2.6 V
 * Tied to 5v: `VCC_NRF_3V3` = 2.6 V

### Actually disabling the nRF

Noting that 2.6-2.8 volts is probably enough for the nRF to be running. I tried directly tying the `VCC_NRF_3V3` net to ground. In this case, without the USB connected, power draw increases from 16 mA (running the tock-nrf51822-really-long-name-uart-conn app) to 24 mA. Moreover, while tied low, the sensors app does not function. Letting go starts it again.

Adding a "Starting" message to the start of the app shows that the app is **not** restarting. Rather, the SAM4L is hanging and then continuing the application. Inspection shows that the I2C bus connecting the SAM4L, nRF51822, and Sensors falls to 0.3 volts when the `VCC_NRF_3V3` is zero. This causes the bus to hang.

The problem is that the I2C bus is pulled up to `VCC_SENSE_3V3` but is connected to the SAM4L on `VCC_MCU_3V3` and the nRF51822 on `VCC_NRF_3V3`. If you actually intend for the voltage domains to be separate and gate-able, the connections to the I2C bus must be isolated.

### Things that are wrong
1) The transistors for power-gating components are not working. They are not capable of cutting off power from the nRF51822
2) The TWI2 bus is connected to three different voltage domains and isolated from none of them.

### Fixes
We had to deal with both of these problems on the Signpost platform. Taking a look at the [backplane hardware rev B](https://github.com/lab11/signpost/tree/master/hardware/backplane/rev_b) (which works except for USB) should be pretty informative in general.

1) We used the SIP32401A load switch to handle power gating modules
2) We used the FXMA2102 voltage translator/buffer/repeater/isolator designed for I2C applications

The SIP32401A has a really tiny package that's a little hard to get right by hand. If you expect to hand-solder boards you might want to find another part.

Also, both of these parts were selected to fit the low current draw requirements of the Signpost platform. There might be easier to use / less expensive versions that have a higher current draw.

ppannuto, 2016-12-21:
Quick follow-up on those parts, the I2C isolator is actually the more challenging package. I had maybe a 75% success rate on hand-soldering those on first try, 90% on the power switch. That said, they're easy (ish) to validate install with a quick electrical test and usually one reflow was good enough to get them working so not the worst by any means.

shaneleonard, 2017-01-16:
Following up with @brghena's post, I believe the NRF is getting back-powered through the IO lines from the SAM4L. @kwantam's explanation for this behavior:

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

shaneleonard, 2017-01-16:
I think this is essentially what you're also getting at with the I2C lines not being isolated, correct?. This issue affects some of the other subsystems that we're trying to power gate, so I'm going to open a new issue ticket for it.

shaneleonard, 2017-01-16:
Well actually since this thread is `sensors power bugs`, I guess it should probably remain here? I'm not sure

shaneleonard, 2017-02-14:
The current proposed fix for this issue is to use analog switches acting as pass transistors. I need to isolate the RF233 SPI (4 pins) and two I2C domains (4 pins), so two of the 74LVC4066 should work (thanks @kwantam). If I use the SIP32401 to solve #12, then I can use the same enable signals to activate the switches. Using an analog switch might actually also provide a fix to #13 if we can selectively connect/disconnect the FTDI DTR line.

shaneleonard, 2017-02-14:
This solution assumes that we are OK with manually pulling all relevant GPIO lines to ground when a module is not in use (eg the RF233 RESET/IRQ/SLP pins, etc).

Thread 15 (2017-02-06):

FTDI DTR connected directly to RESET

shaneleonard, 2017-02-06:
When connected over the FTDI USB and attempting to program over JLink, JLink complains that it cannot pull RESET low. This is due to the fact that the DTR pin of the FTDI chip is connected directly to RESET instead of being connected via a pullup resistor. Adding a 1K resistor between DTR and RESET fixed this issue on the hail board and fixes it on imix as well. See #13.

<hr/>

Steps to reproduce the error:

1. Power board using the FTDI USB port
2. Connect over JLinkExe
3. Run the reset command (`r`) in JLinkExe after connecting

JLinkExe will output the following warning:

```
**************************
WARNING: RESET (pin 15) high, but should be low. Please check target hardware.
**************************
```

When the resistor is added and the above procedure is repeated, the warning goes away and instead we get a successful result:

```
Reset delay: 0 ms
Reset type NORMAL: Resets core & peripherals via SYSRESETREQ & VECTRESET bit.
Found SWD-DP with ID 0x2BA01477
```

shaneleonard, 2017-02-06:
Fixed for v1.3.

Closed 2017-02-06.

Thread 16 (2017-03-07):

ADC pin labels

brghena, 2017-03-07:
The issue @phil-levis commented on in the ADC driver seems to be fixed in Imix now.  https://github.com/helena-project/tock/blob/master/chips/sam4l/src/adc.rs#L11 (@shaneleonard let me know if that's right and I'll remove the comment)

However, the pins are still mapped with AD0 -> ADCIFE1, AD1 -> ADCIFE2, etc. Is there any reason that they shouldn't be AD0 -> ADCIFE0, AD1 -> ADCIFE1, etc. instead so that the world makes sense?

shaneleonard, 2017-03-08:
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

In v1.3 they are mapped sensibly, although they should be that way for at least v1.2 as well.

shaneleonard, 2017-03-08:
I just checked and every recent revision has the sane mapping, in fact I'm pretty sure it's been mapped like this on every board. I explicitly remember identifying the weird mapping as a major issue with Firestorm, so there's no reason that I can recall where I wouldn't have fixed it from the beginning.

brghena, 2017-03-08:
Thanks @shaneleonard, I'll remove the issue from the ADC driver.

However, the pins still aren't exactly labeled sensibly. The net `ADCIFE0` connects the PA05 on the SAM4L, which per the datasheet is actually ADCIFE AD1.

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

shaneleonard, 2017-03-09:
Hmm. This is starting to sound familiar. I think I must have gotten into a corner with the pin assignments where I had to use PA04 for the light sensor interrupt, and thus ADCIFE1-6 were a better option than ADCIFE0-5. However, it was silly of me to number the pins this way in the schematic, I should have kept them true to their values in the datasheet.

Firestorm's numbering was worse in the sense that they actually numbered ADCIFE0-ADCIFE5 to A5-A0 (in reverse), which is where Phil's comment came from.

After looking back through the datasheet, there are luckily a couple of ways to fix this:

(1) Just rename the schematic to be more accurate (ADCIFE1->A0, etc)
or
(2) Reassign some pins so that LIGHT_INT goes to PC25 (still EXTINT2), GPIO8 gets bumped to any accessible pin, I use ADCIFE0-5 for A0-5, and I use the newly free ADCIFE6 as the analog sense pin for the TRNG. This would also take care of #8.

shaneleonard, 2017-03-09:
Looking at the layout, option 2 actually shouldn't be too difficult. I can do it for v1.3 but then unfortunately people will have to be aware of this change until everyone on 1.2 moves to 1.3

alevy, 2017-03-09:
@shaneleonard I wouldn't worry about that.

shaneleonard, 2017-03-09:
@alevy By 'that' you mean people being aware of this right?

alevy, 2017-03-09:
Yes, sorry :) To reiterate: breaking changes are fine at this stage.

shaneleonard, 2017-03-09:
Great. I'll change the pins on v1.3 and update the schematics to be more accurate.

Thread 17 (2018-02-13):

Ethernet support?

KhArtNJava, 2018-02-13:
Do you plan to add 10/100M Ethernet support, like in this board https://www.aliexpress.com/item/ATSAM4E16E-ATSAM4-Evaluation-Kit-120MHz-Cortex-M4-Ethernet-USB-UART-CAN-485-TF-NAND-RTC-2/32827008906.html ?

alevy, 2018-02-13:
That board uses a SAM4-_E_, which has an on-die ethernet MAC controller, whereas imix uses the lower-power SAM4-_L_, which doesn't. So... no, but a different board with ethernet+802.15.4 and/or BLE would certainly be interesting!

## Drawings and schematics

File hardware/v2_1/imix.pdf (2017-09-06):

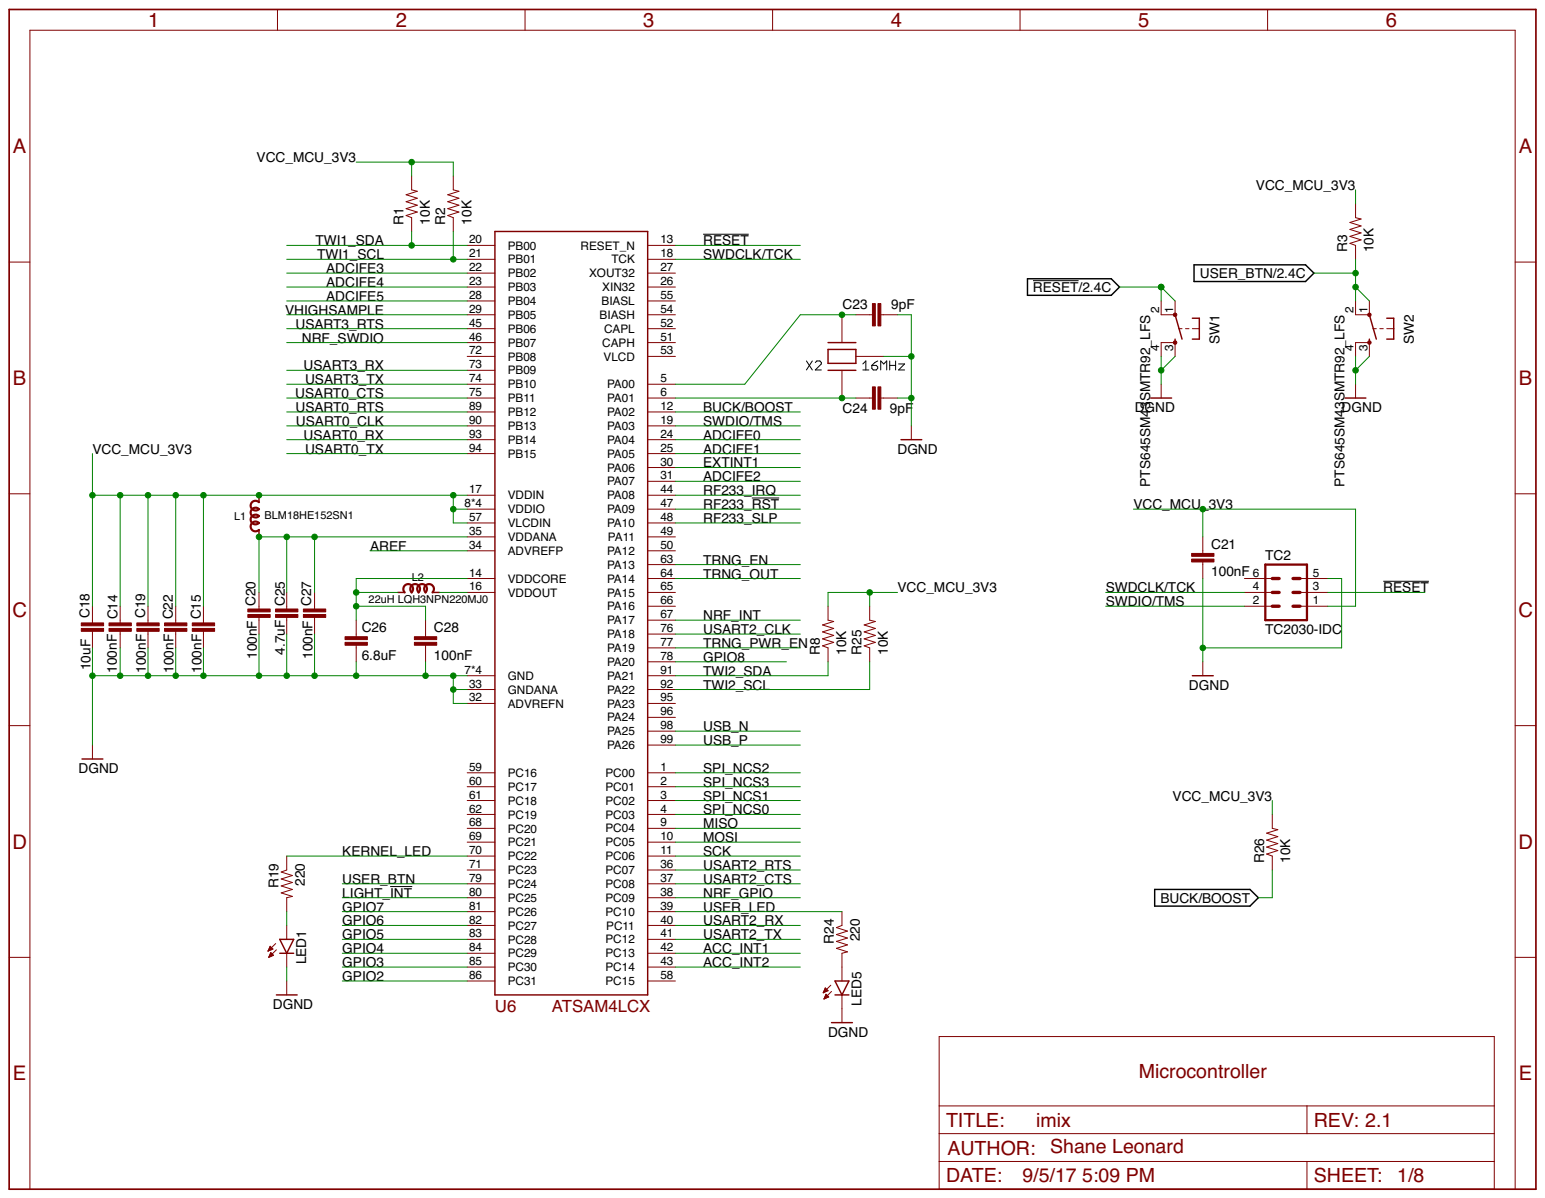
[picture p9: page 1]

AREF | ADVREFP 34 VDDCORE 14

VDDOUT 16 GND 7*4

KERNEL_LED | GNDANA 33 | TWI2_SCL

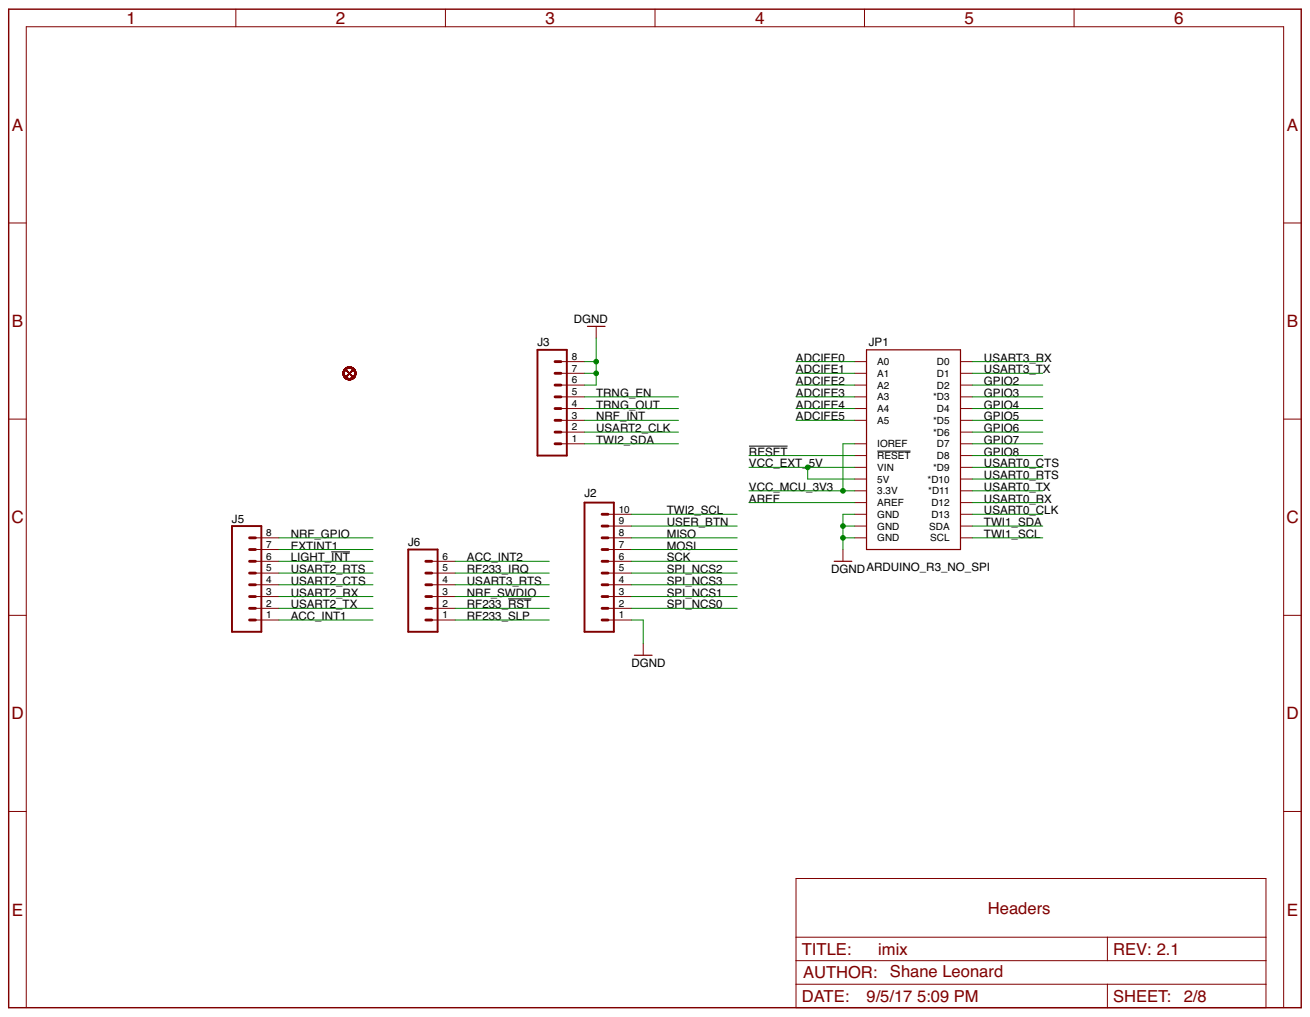
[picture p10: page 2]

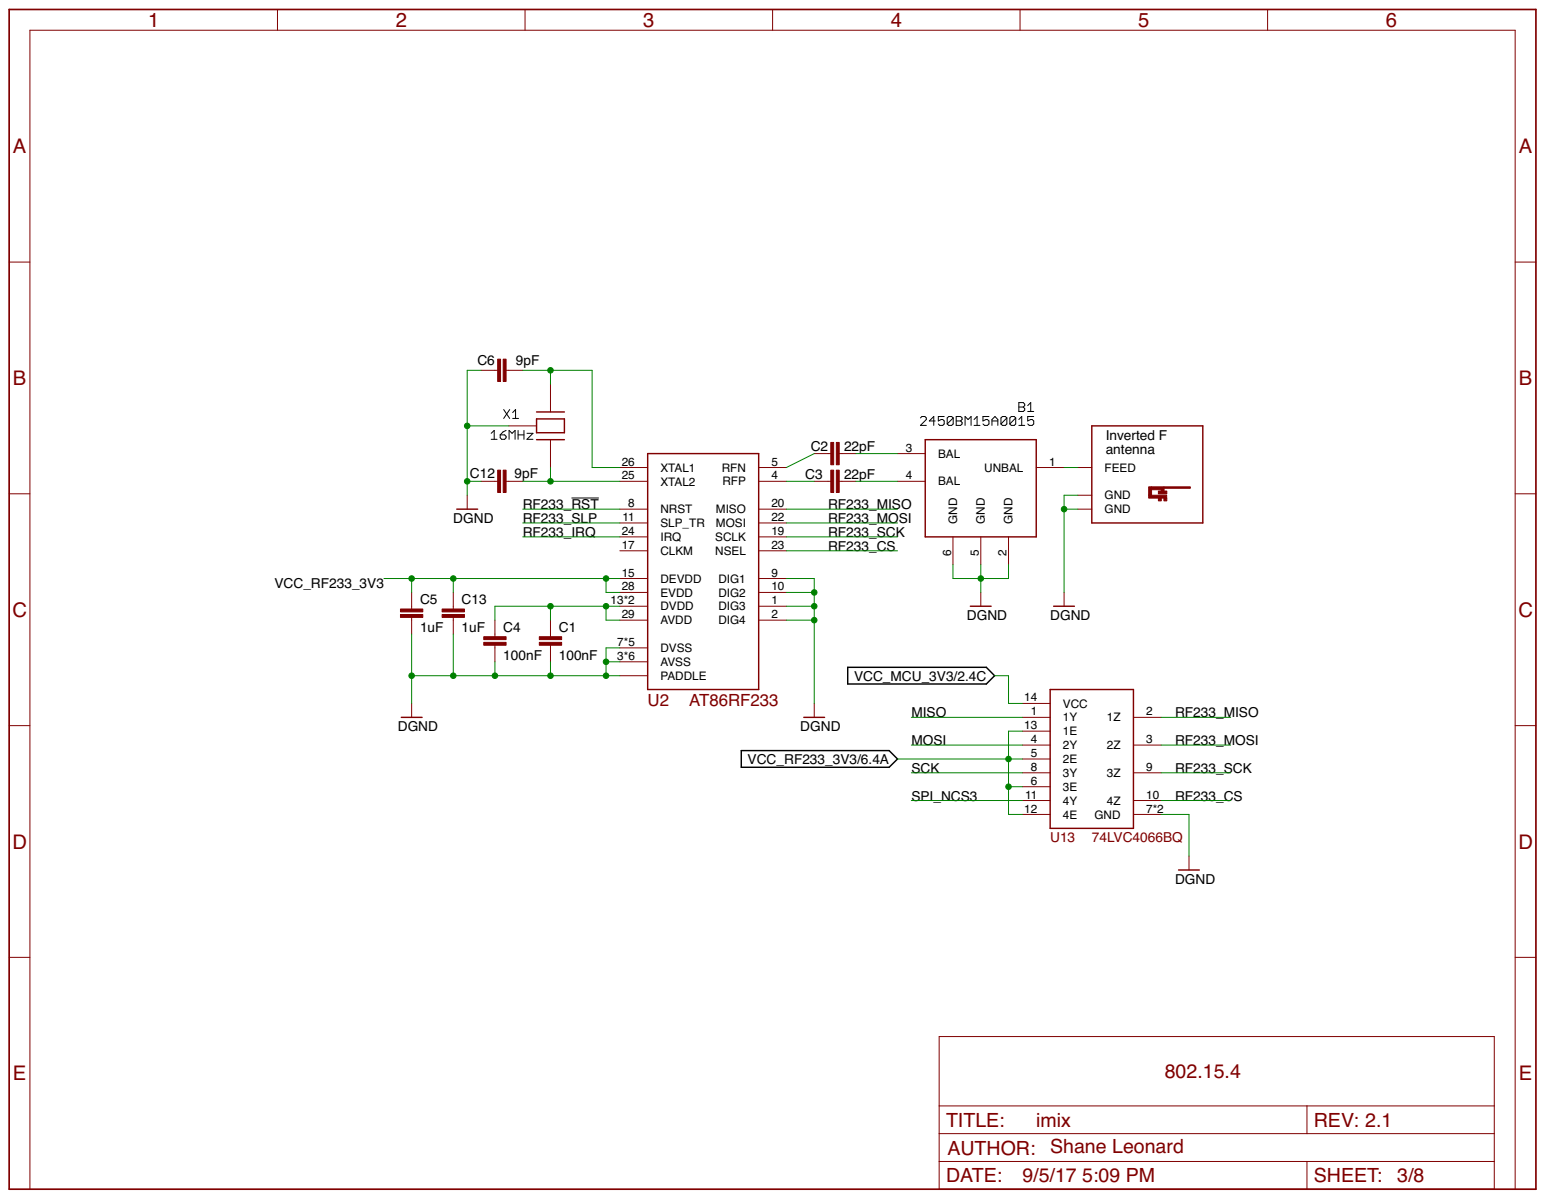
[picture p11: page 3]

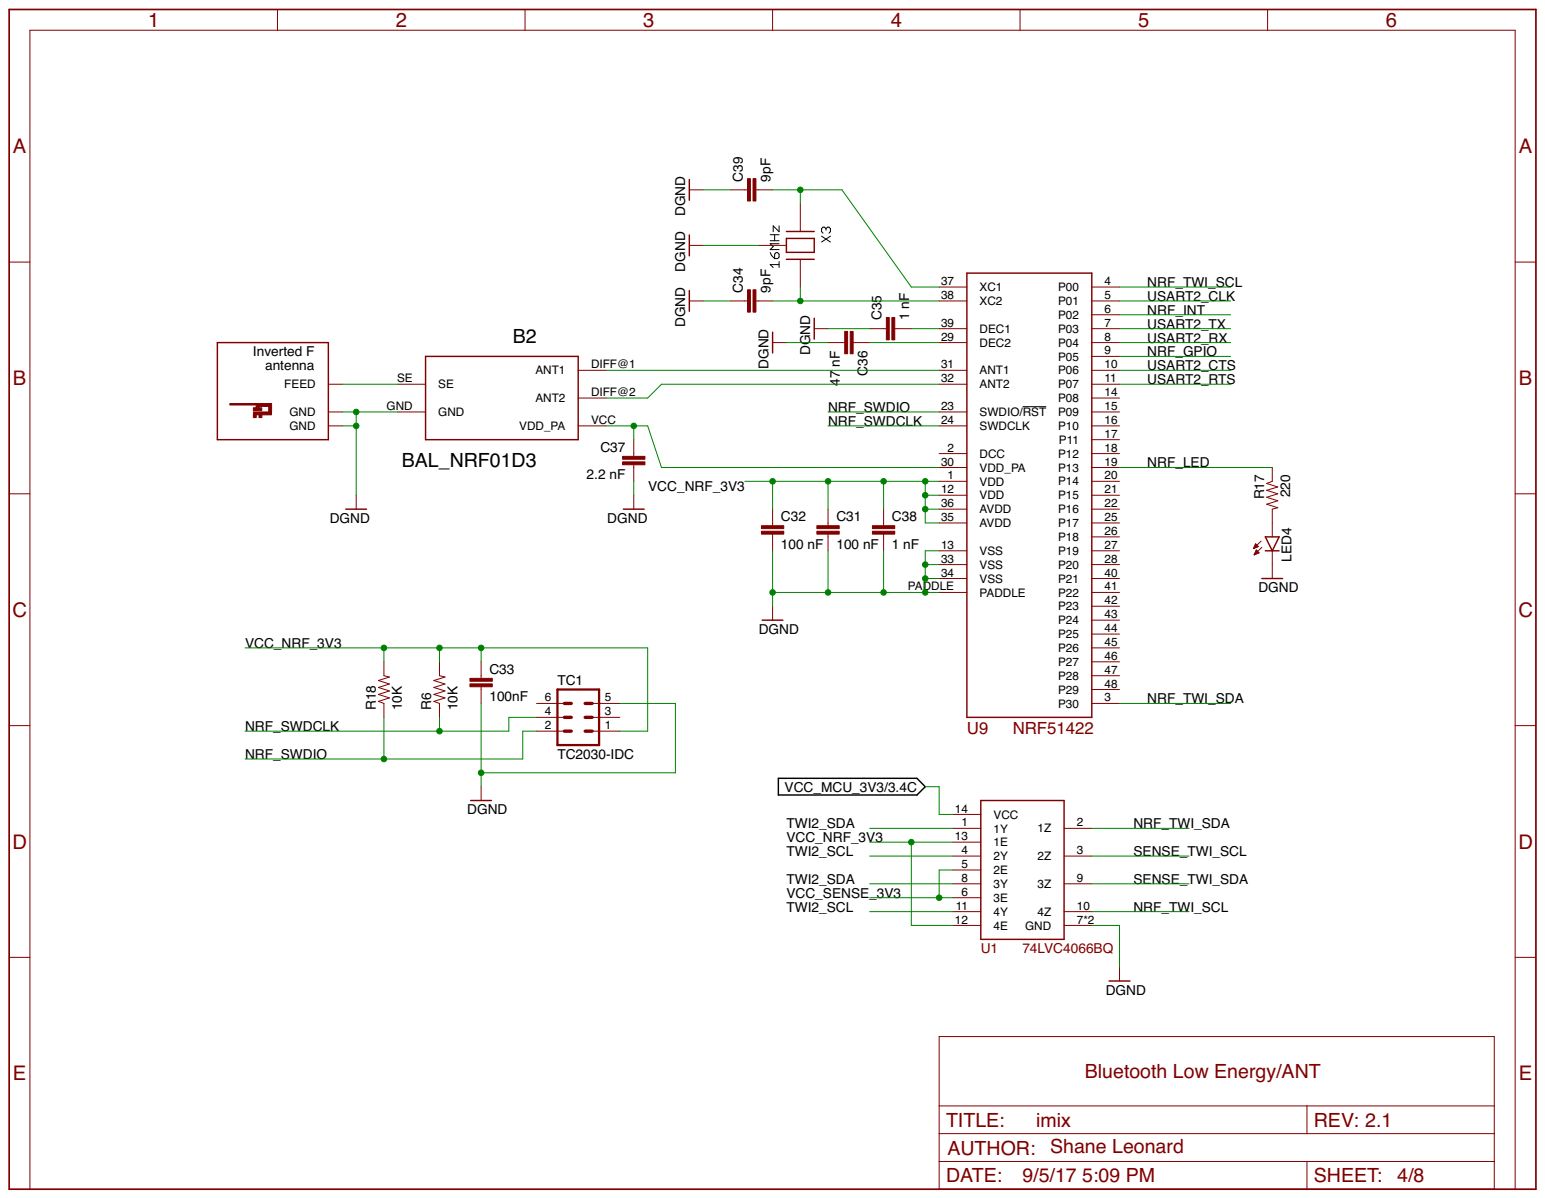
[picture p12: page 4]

Bluetooth Low Energy/ANT

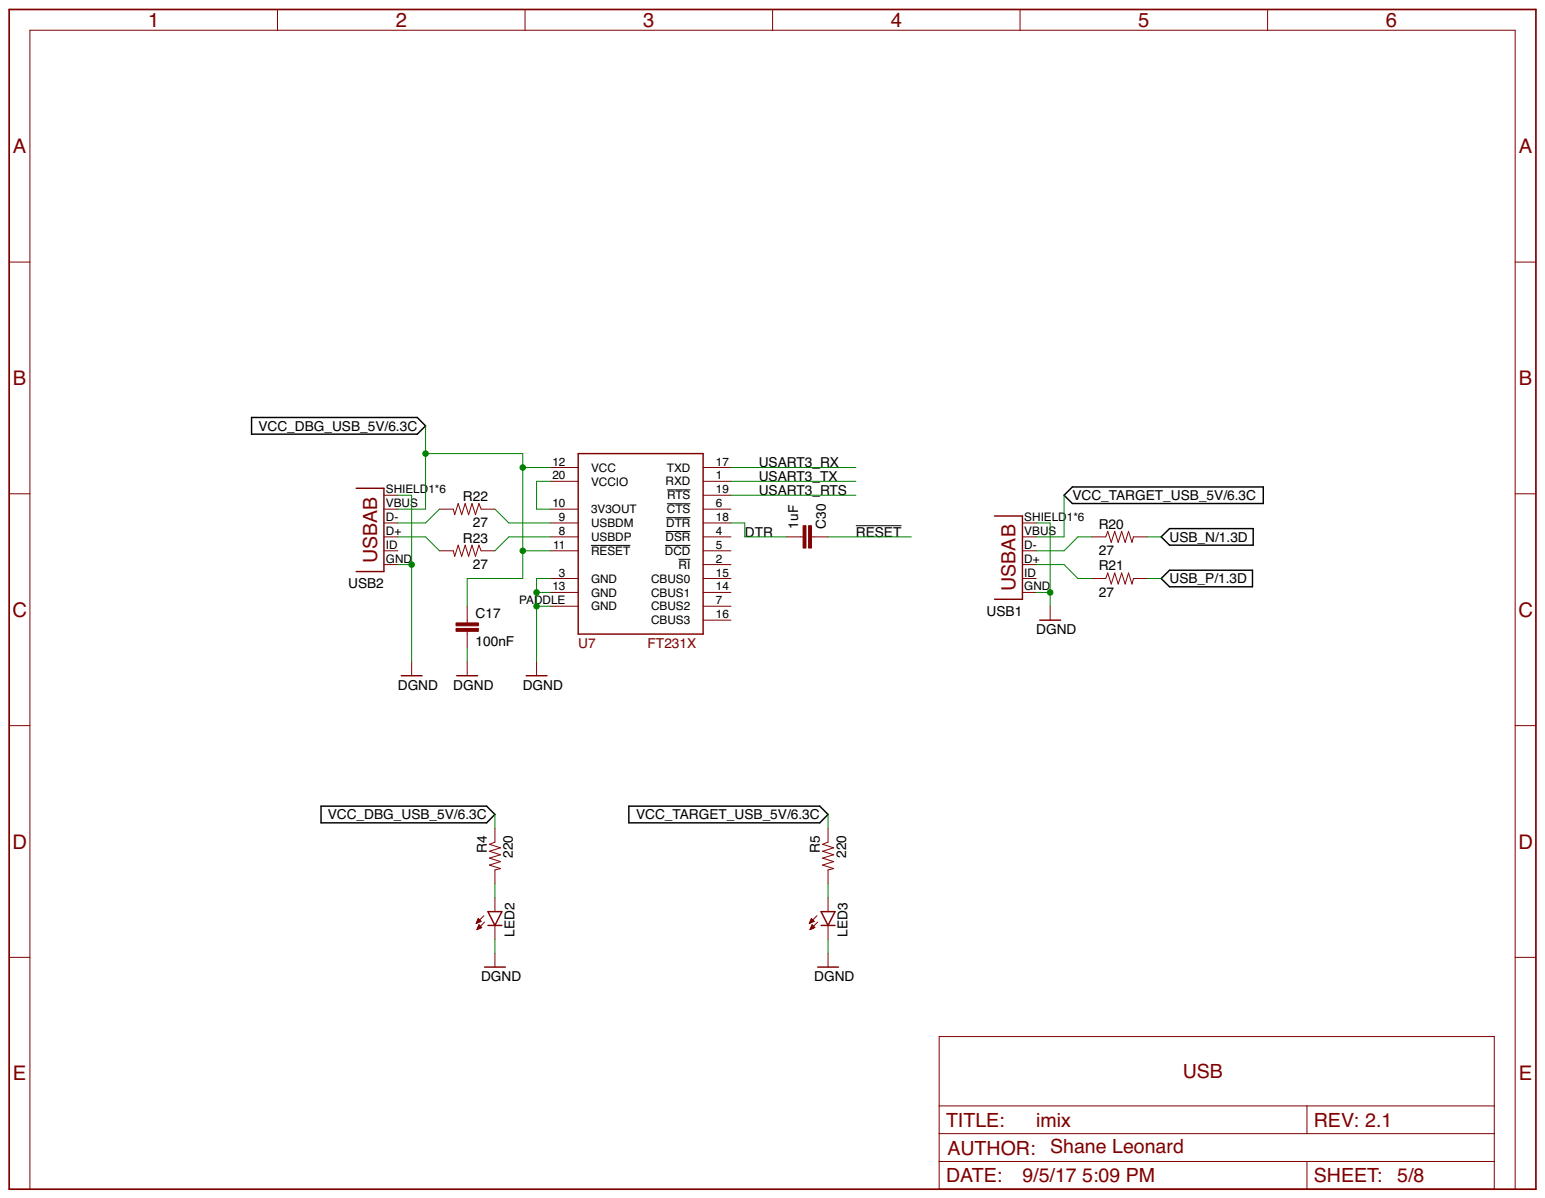
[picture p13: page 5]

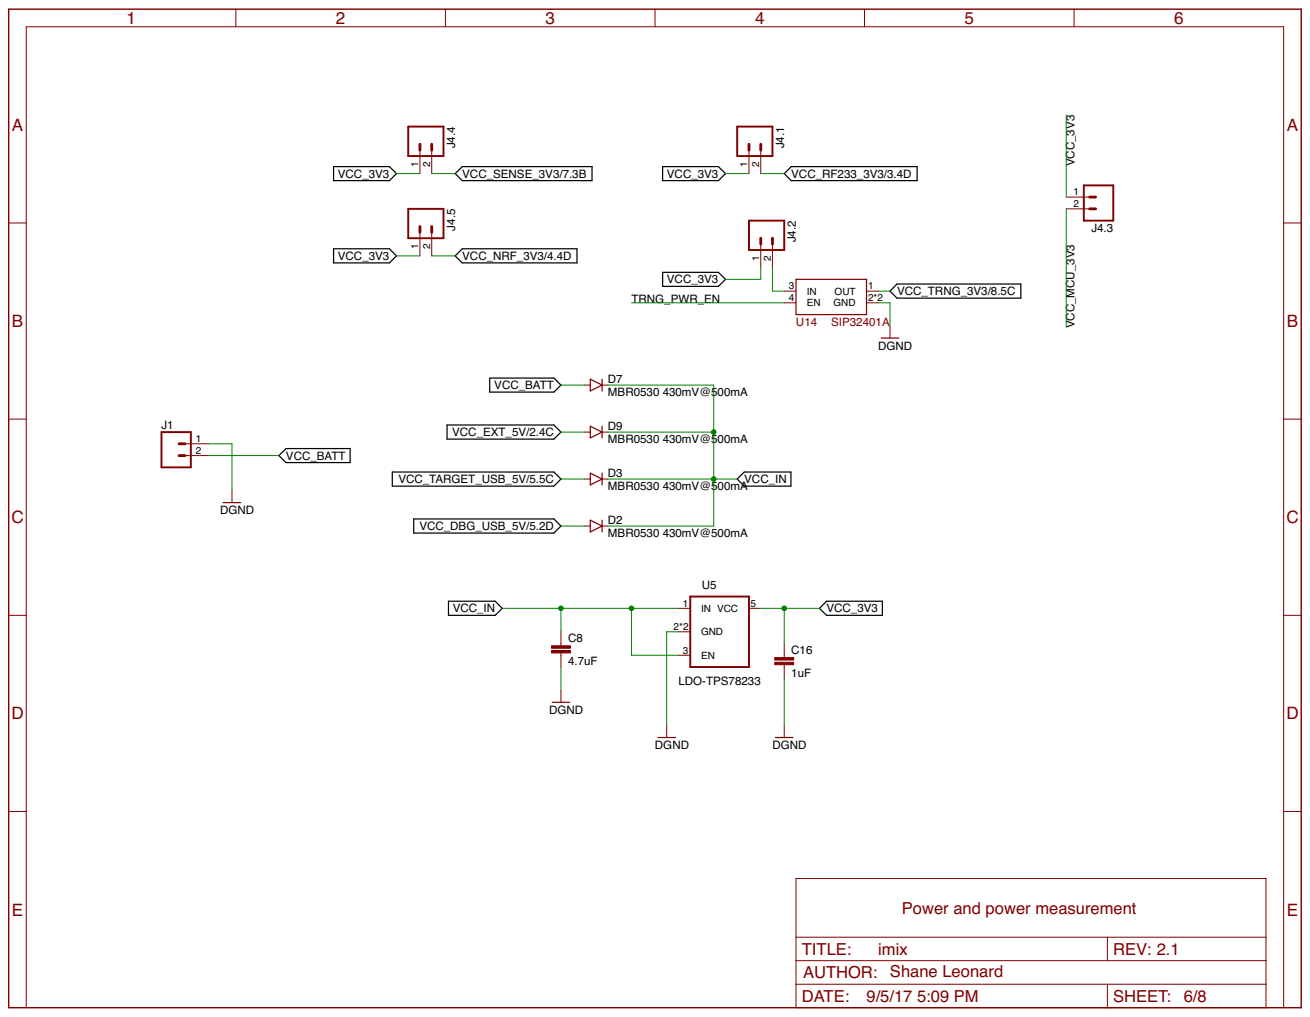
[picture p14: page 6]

Power and power measurement

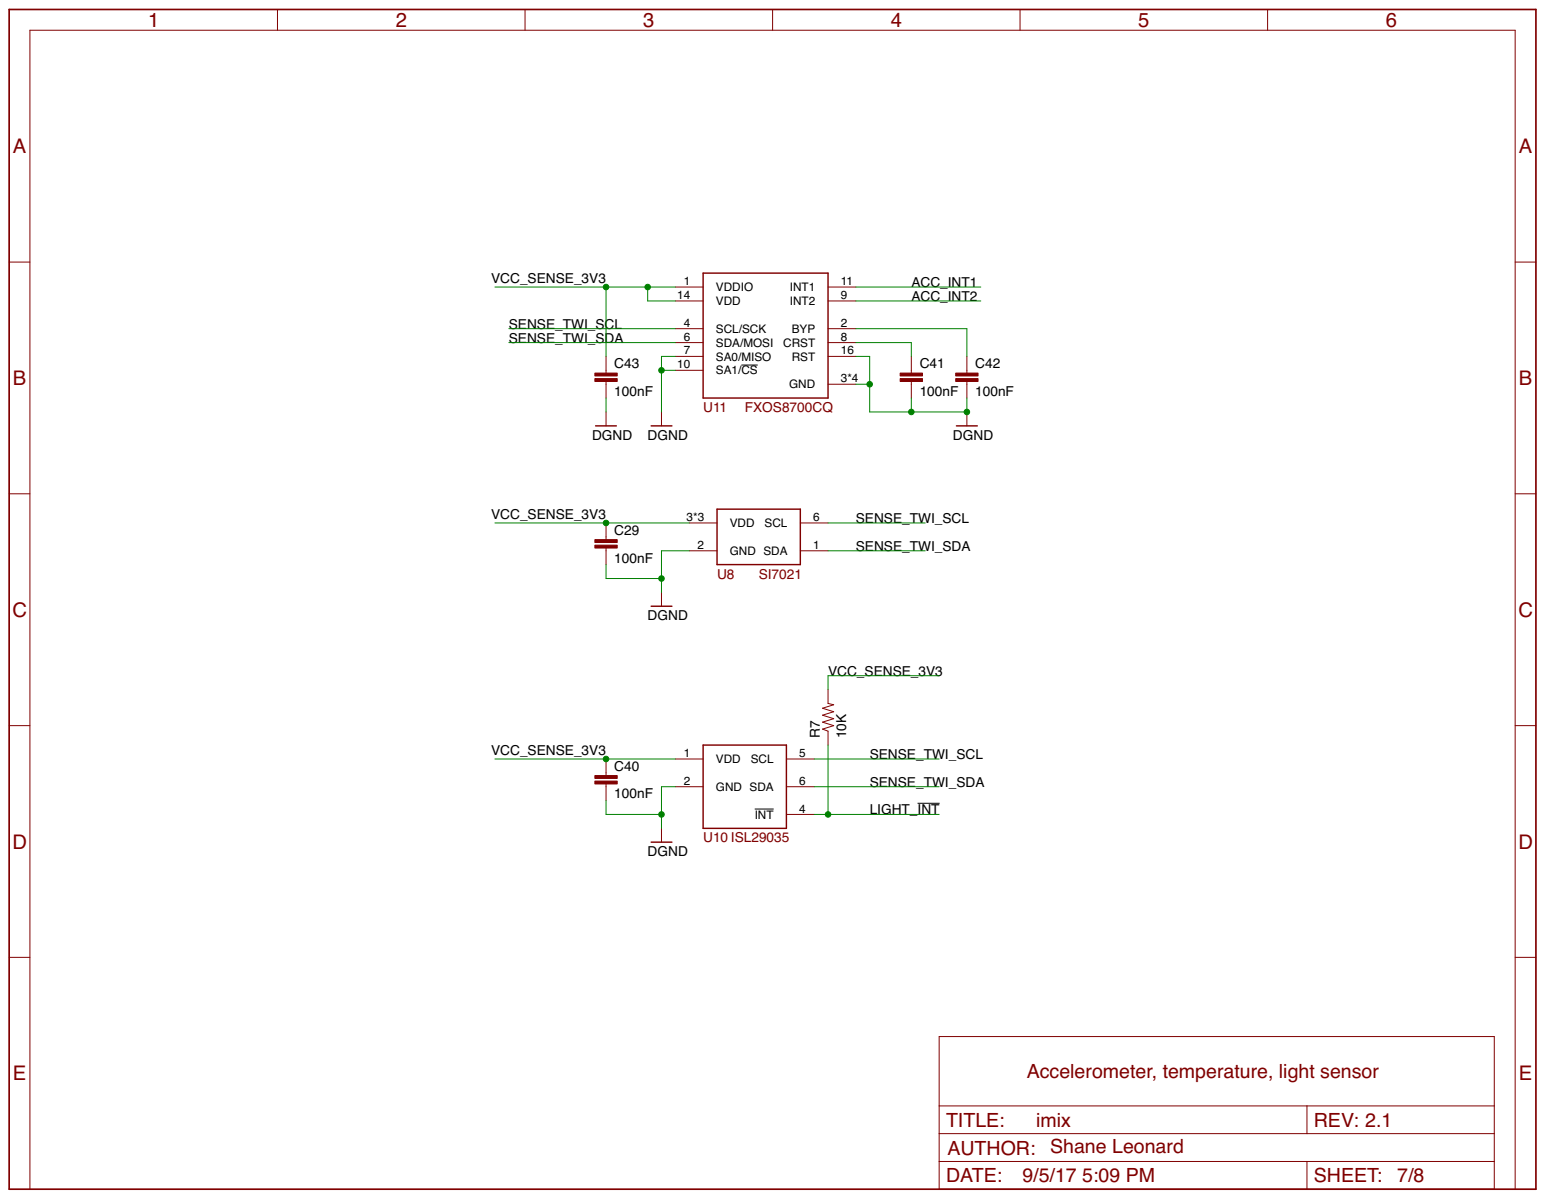
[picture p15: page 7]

Accelerometer, temperature, light sensor

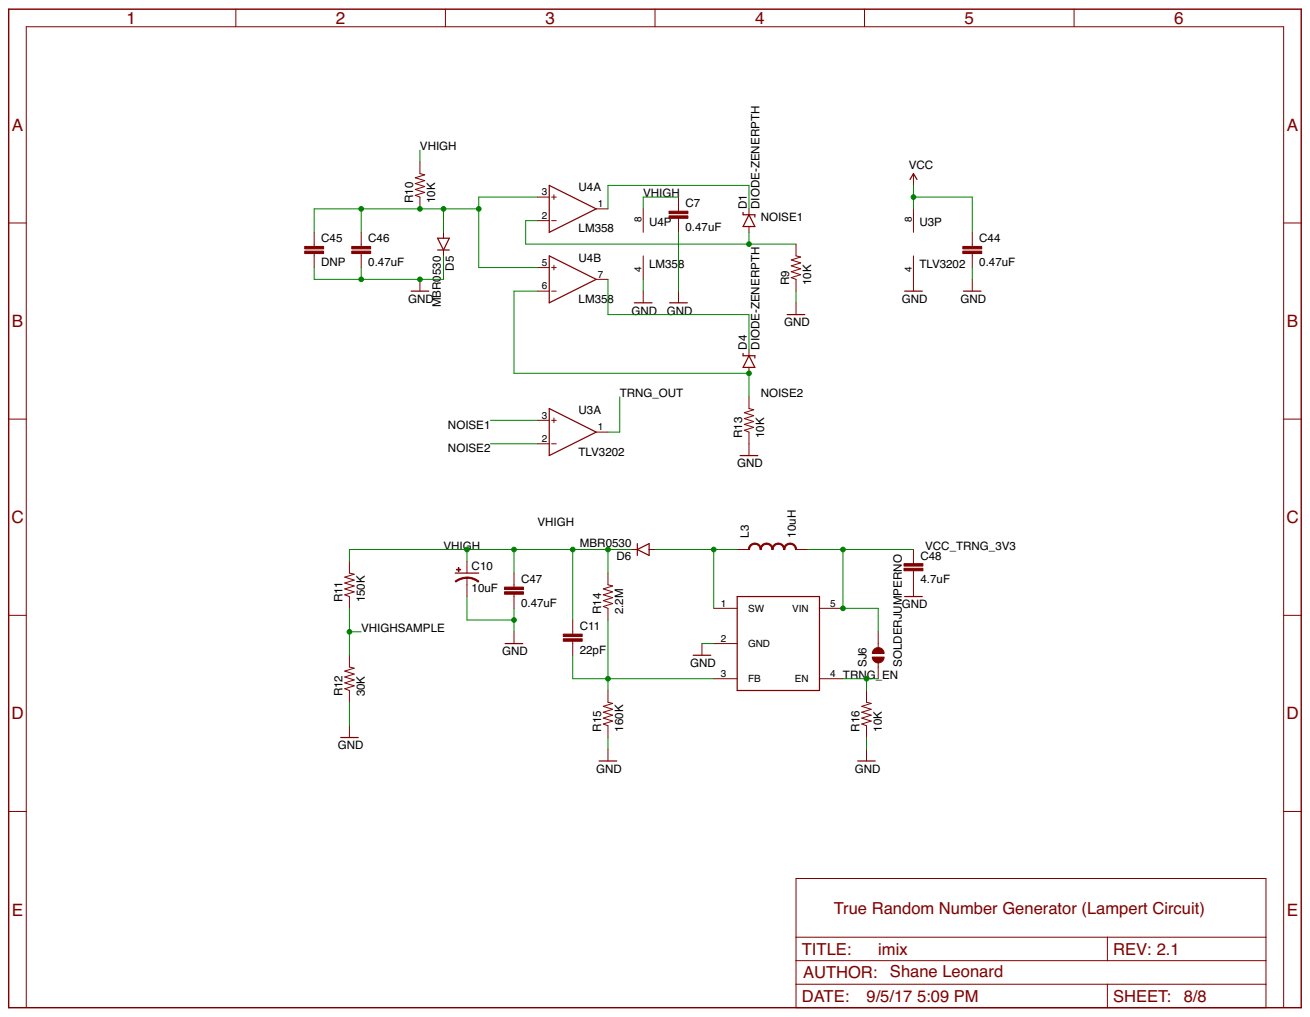
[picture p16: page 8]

DIODE-ZENERPTH

True Random Number Generator (Lampert Circuit)

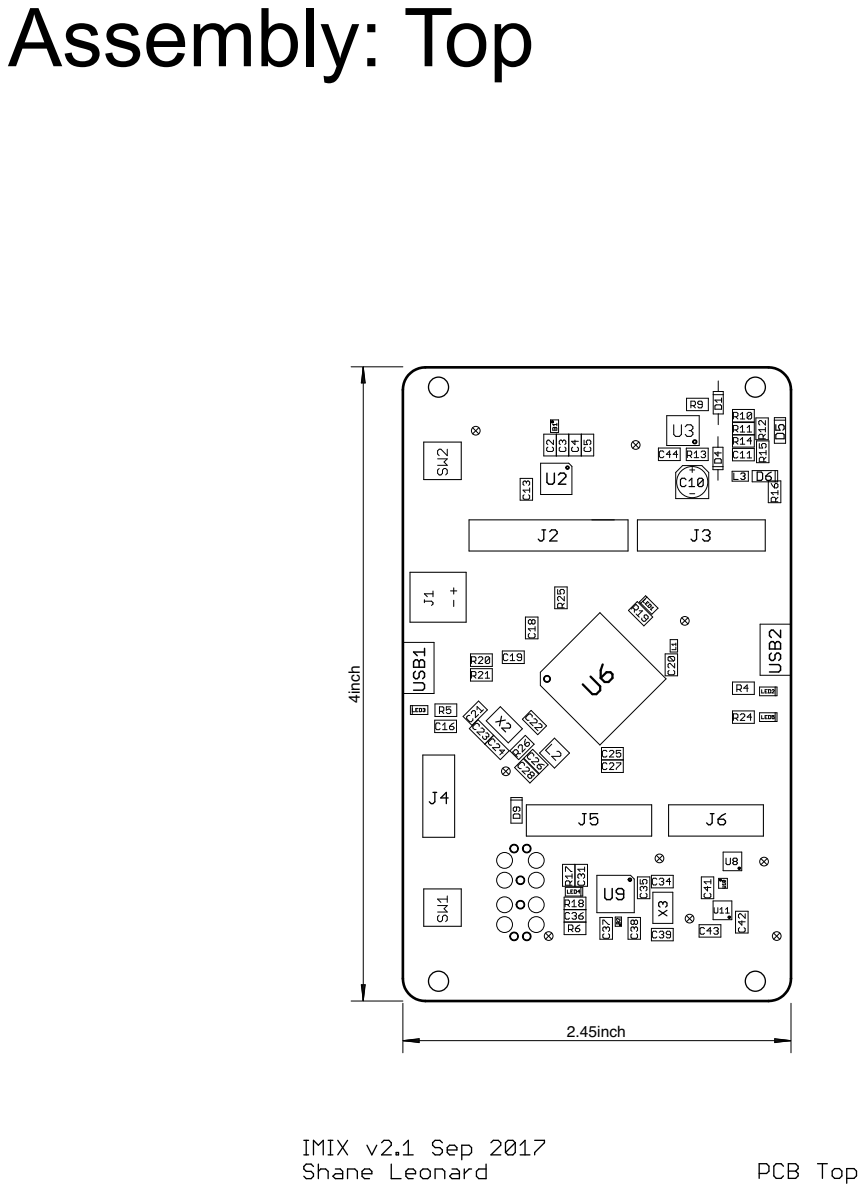
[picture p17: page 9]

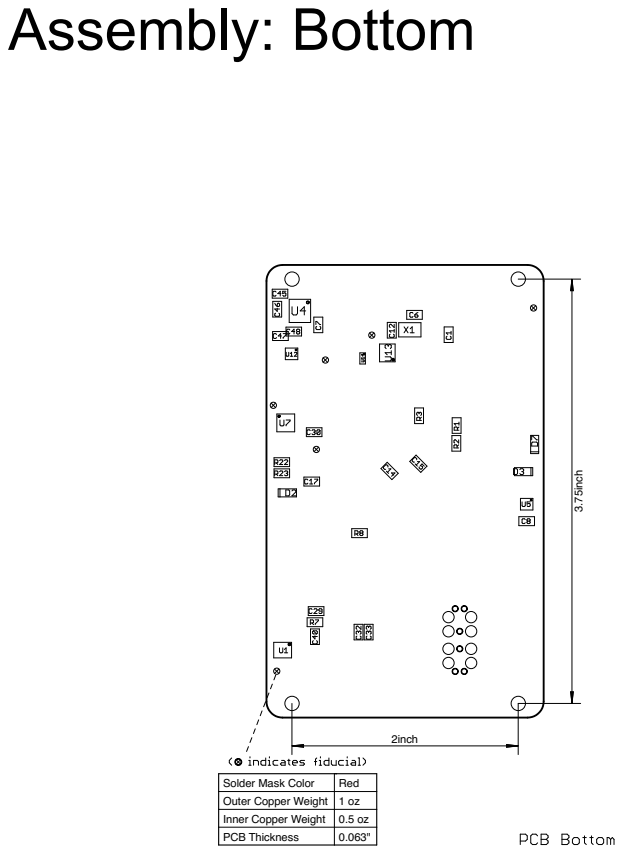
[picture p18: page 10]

Solder Mask Color | Red
Outer Copper Weight | 1 oz
Inner Copper Weight | 0.5 oz
PCB Thickness | 0.063"

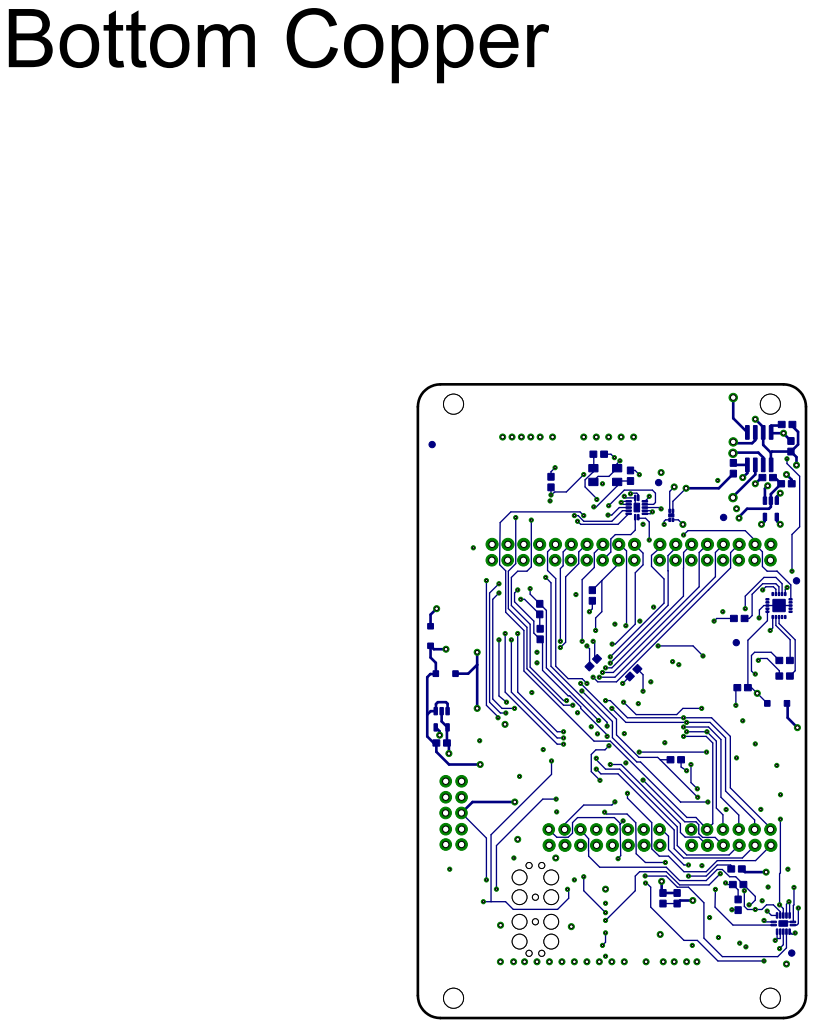
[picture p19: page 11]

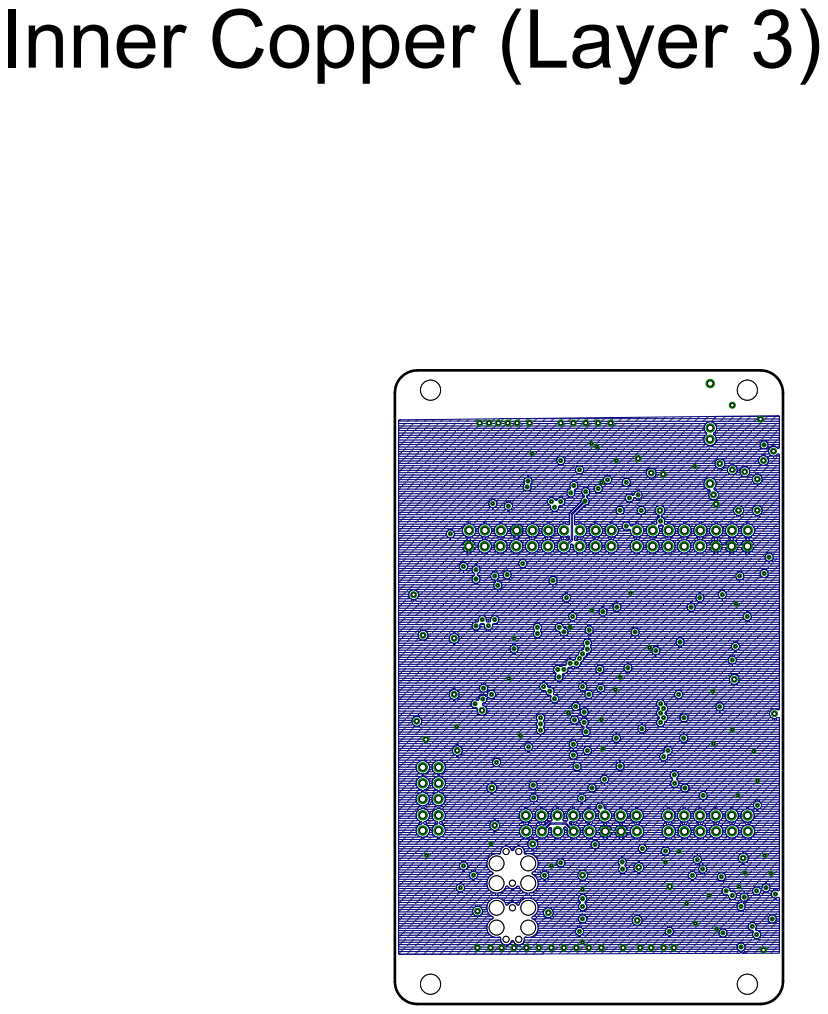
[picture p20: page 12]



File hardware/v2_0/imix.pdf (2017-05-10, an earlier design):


SENSE_PWR_EN NRF_PWR_EN RF233_PWR_EN TRNG_PWR_EN KERNEL_LED | 33 | 92 PA23 TWI2_SCL

32 | 95 PA24 96 PA25 98 PA26 USB_N 99 USB_P 1 PC01 SPI_NCS2 2 PC02 SPI_NCS3 3 PC03 SPI_NCS1 4 PC04 9 PC05 10 PC06 MOSI 11 PC07 SCK 36 PC08 37 PC09 38 PC10 39 PC11




Bluetooth Low Energy/ANT



Power and power measurement


Accelerometer, temperature, light sensor


TLV3202 DIODE-ZENERPTH DIODE-ZENERPTH

True Random Number Generator (Lampert Circuit)

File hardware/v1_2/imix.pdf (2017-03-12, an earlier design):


33 | 91 PA22 92 PA23 TWI2_SCL

32 | 95 PA24 96 PA25 98 PA26 USB_N 99 USB_P 1 PC01 SPI_NCS2 SPI_NCS3 2 PC02 3 PC03 SPI_NCS1 4 PC04 9 PC05 SCK MISO MOSI 10 PC06 11 PC07 36 PC08 37 PC09 38 PC10 39 PC11




Bluetooth Low Energy/ANT



Power and power measurement



TLV3202 DIODE-ZENERPTH DIODE-ZENERPTH

True Random Number Generator (Lampert Circuit)

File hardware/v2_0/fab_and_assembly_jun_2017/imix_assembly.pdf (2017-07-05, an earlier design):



Solder Mask Color | Red
Outer Copper Weight | 1 oz
Inner Copper Weight | 0.5 oz
PCB Thickness | 0.063"



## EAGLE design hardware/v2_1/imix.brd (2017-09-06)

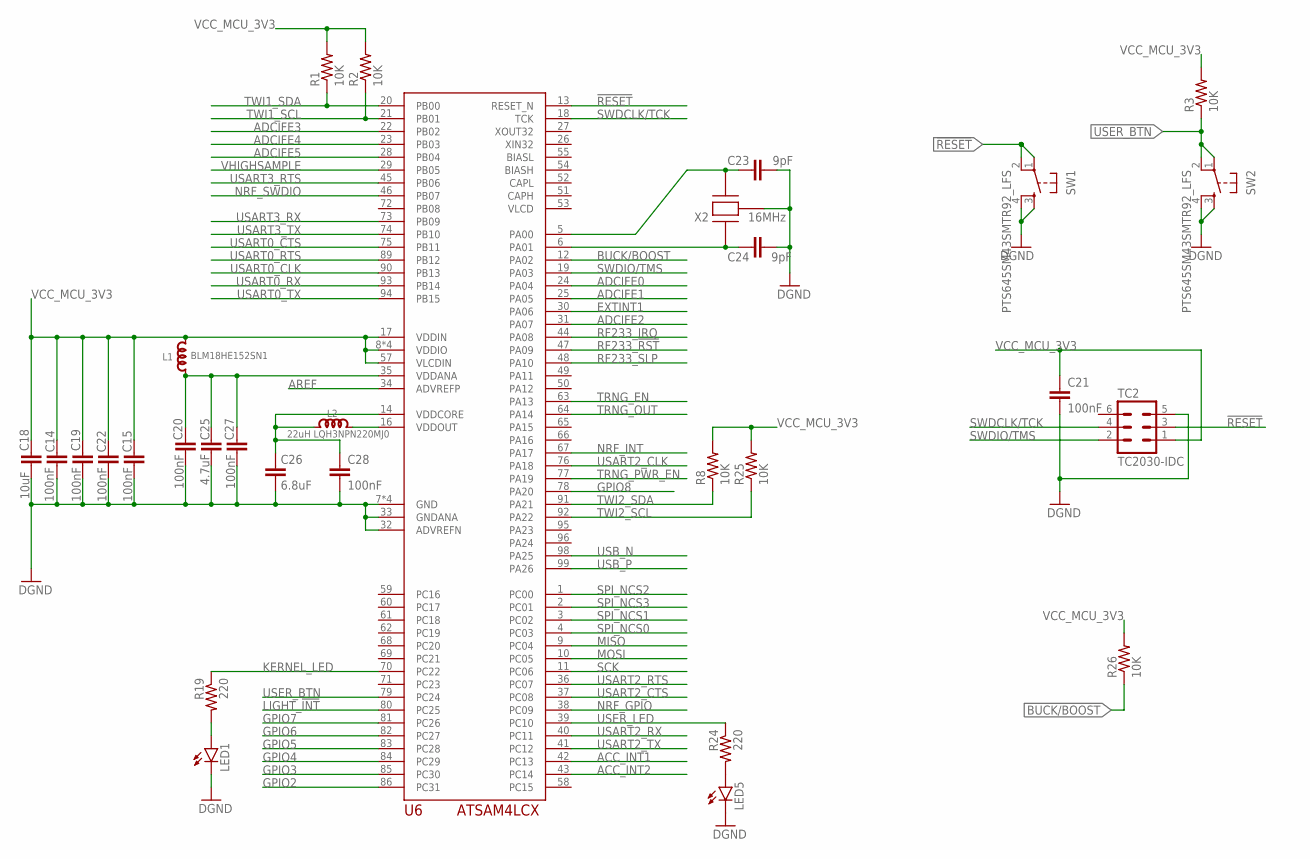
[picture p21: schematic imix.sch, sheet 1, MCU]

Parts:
C14, C15, C19, C20, C21, C22, C27, C28: 100nF; C0603
C18: 10uF; C0603
C23, C24: 9pF; C0603
C25: 4.7uF; C0603
C26: 6.8uF; C0603
L1: BLM18HE152SN1; L0603
L2: 22uH LQH3NPN220MJ0; L1212
LED1, LED5: LED-BLUE0603; LED-0603
R1, R2, R3, R8, R25, R26: 10K; 0603-RES
R19, R24: 220; 0603-RES
SW1, SW2: PTS645SM43SMTR92_LFS; TAC_SWITCH_6X6
TC2: TC2030-IDC
U6: ATSAM4LCX_100; TQFP100
X2: 16MHz; CTS_405_SERIES

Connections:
!RESET: SW1.1, SW1.2, TC2.3, U6.13 (RESET_N); also elsewhere on the board
ACC_INT1: U6.42 (PC13); also elsewhere on the board
ACC_INT2: U6.43 (PC14); also elsewhere on the board
ADCIFE0: U6.24 (PA04); also elsewhere on the board
ADCIFE1: U6.25 (PA05); also elsewhere on the board
ADCIFE2: U6.31 (PA07); also elsewhere on the board
ADCIFE3: U6.22 (PB02); also elsewhere on the board
ADCIFE4: U6.23 (PB03); also elsewhere on the board
ADCIFE5: U6.28 (PB04); also elsewhere on the board
AREF: U6.34 (ADVREFP); also elsewhere on the board
BIASH: U6.54 (BIASH)
BIASL: U6.55 (BIASL)
BUCK/BOOST: R26.1, U6.12 (PA02)
EXTINT1: U6.30 (PA06); also elsewhere on the board
GND: C14.1, C15.1, C18.1, C19.1, C20.2, C21.2, C22.1, C23.2, C24.2, C25.2, C26.2, C27.2, C28.2, LED1.C, LED5.C, SW1.3, SW1.4, SW2.3, SW2.4, TC2.5, U6.7 (GND), U6.15 (GND), U6.32 (ADVREFN), U6.33 (GNDANA), U6.56 (GND), U6.100 (GND), X2.CASE@2 (CASE), X2.CASE@4 (CASE); also elsewhere on the board
GPIO2: U6.86 (PC31); also elsewhere on the board
GPIO3: U6.85 (PC30); also elsewhere on the board
GPIO4: U6.84 (PC29); also elsewhere on the board
GPIO5: U6.83 (PC28); also elsewhere on the board
GPIO6: U6.82 (PC27); also elsewhere on the board
GPIO7: U6.81 (PC26); also elsewhere on the board
GPIO8: U6.78 (PA20); also elsewhere on the board
KERNEL_LED: R19.1, U6.70 (PC22)
LIGHT_!INT: U6.80 (PC25); also elsewhere on the board
MCU_VOUT3.3: L2.2, U6.16 (VDDOUT)
MISO: U6.9 (PC04); also elsewhere on the board
MOSI: U6.10 (PC05); also elsewhere on the board
unnamed: C20.1, C25.1, C27.1, L1.1, U6.35 (VDDANA)
unnamed: C24.1, U6.6 (PA01), X2.1
unnamed: C26.1, C28.1, L2.1, U6.14 (VDDCORE)
unnamed: C23.1, U6.5 (PA00), X2.3 (2)
unnamed: LED1.A, R19.2
unnamed: LED5.A, R24.2
NRF_GPIO: U6.38 (PC09); also elsewhere on the board
NRF_INT: U6.67 (PA17); also elsewhere on the board
NRF_SWDIO: U6.46 (PB07); also elsewhere on the board
RF233_!RST: U6.47 (PA09); also elsewhere on the board
RF233_IRQ: U6.44 (PA08); also elsewhere on the board
RF233_SLP: U6.48 (PA10); also elsewhere on the board
SCK: U6.11 (PC06); also elsewhere on the board
SPI_NCS0: U6.4 (PC03); also elsewhere on the board
SPI_NCS1: U6.3 (PC02); also elsewhere on the board
SPI_NCS2: U6.1 (PC00); also elsewhere on the board
SPI_NCS3: U6.2 (PC01); also elsewhere on the board
SWDCLK/TCK: TC2.4, U6.18 (TCK)
SWDIO/TMS: TC2.2, U6.19 (PA03)
TRNG_EN: U6.63 (PA13); also elsewhere on the board
TRNG_OUT: U6.64 (PA14); also elsewhere on the board
TRNG_PWR_EN: U6.77 (PA19); also elsewhere on the board
TWI1_SCL: R2.1, U6.21 (PB01); also elsewhere on the board
TWI1_SDA: R1.1, U6.20 (PB00); also elsewhere on the board
TWI2_SCL: R25.1, U6.92 (PA22); also elsewhere on the board
TWI2_SDA: R8.1, U6.91 (PA21); also elsewhere on the board
USART0_CLK: U6.90 (PB13); also elsewhere on the board
USART0_CTS: U6.75 (PB11); also elsewhere on the board
USART0_RTS: U6.89 (PB12); also elsewhere on the board
USART0_RX: U6.93 (PB14); also elsewhere on the board
USART0_TX: U6.94 (PB15); also elsewhere on the board
USART2_CLK: U6.76 (PA18); also elsewhere on the board
USART2_CTS: U6.37 (PC08); also elsewhere on the board
USART2_RTS: U6.36 (PC07); also elsewhere on the board
USART2_RX: U6.40 (PC11); also elsewhere on the board
USART2_TX: U6.41 (PC12); also elsewhere on the board
USART3_RTS: U6.45 (PB06); also elsewhere on the board
USART3_RX: U6.73 (PB09); also elsewhere on the board
USART3_TX: U6.74 (PB10); also elsewhere on the board
USB_N: U6.98 (PA25); also elsewhere on the board
USB_P: U6.99 (PA26); also elsewhere on the board
USER_BTN: R3.1, SW2.1, SW2.2, U6.79 (PC24); also elsewhere on the board
USER_LED: R24.1, U6.39 (PC10)
VCC_MCU_3V3: C14.2, C15.2, C18.2, C19.2, C21.1, C22.2, L1.2, R1.2, R2.2, R3.2, R8.2, R25.2, R26.2, TC2.1, U6.8 (VDDIO), U6.17 (VDDIN), U6.57 (VLCDIN), U6.87 (VDDIO), U6.88 (VDDIO), U6.97 (VDDIO); also elsewhere on the board
VHIGHSAMPLE: U6.29 (PB05); also elsewhere on the board

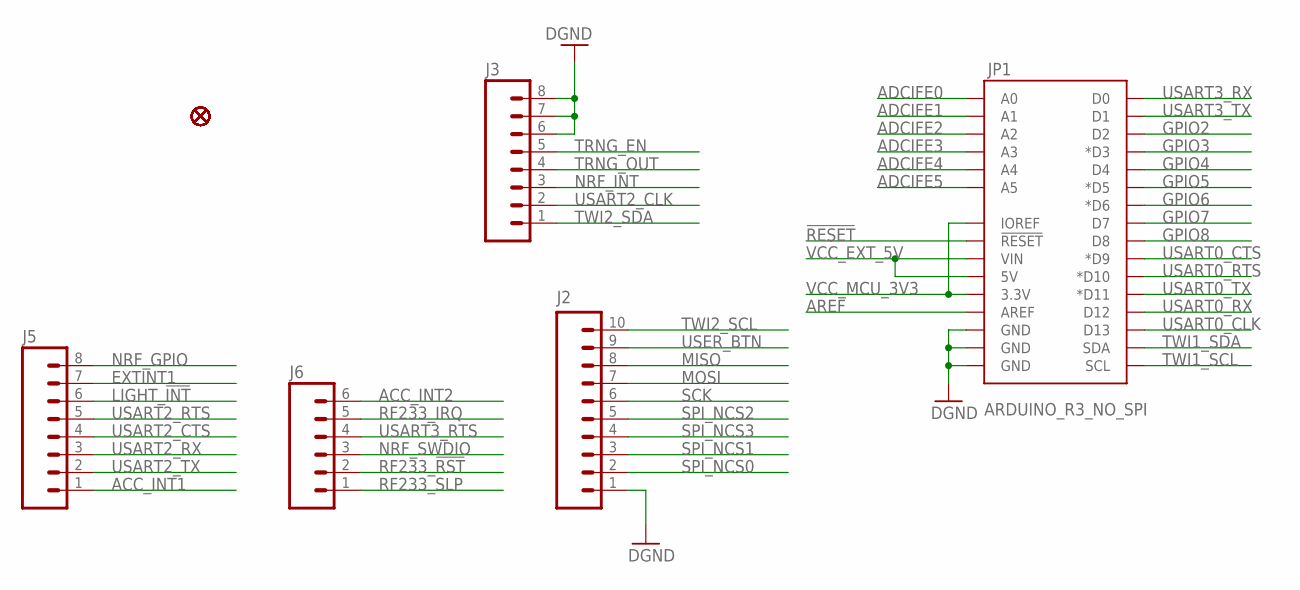
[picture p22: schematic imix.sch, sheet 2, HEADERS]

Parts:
J2: M10NO_SILK_PTH_FEMALE; 1X10_NO_SILK
J3, J5: M08NO_SILK_FEMALE_PTH; 1X08_NO_SILK
J6: M06NO_SILK_FEMALE_PTH; 1X06_NO_SILK
JP1: ARDUINO_R3_NO_SPI; ARDUINO_R3_NO_HOLES_NO_SPI
U$2, U$3, U$5, U$6, U$7, U$8, U$10, U$11, U$12, U$13, U$14, U$15, U$16, U$17, U$18: FIDUCIAL

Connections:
!RESET: JP1.RESET@1 (!RESET!); also elsewhere on the board
ACC_INT1: J5.1; also elsewhere on the board
ACC_INT2: J6.6; also elsewhere on the board
ADCIFE0: JP1.A0; also elsewhere on the board
ADCIFE1: JP1.A1; also elsewhere on the board
ADCIFE2: JP1.A2; also elsewhere on the board
ADCIFE3: JP1.A3; also elsewhere on the board
ADCIFE4: JP1.A4; also elsewhere on the board
ADCIFE5: JP1.A5; also elsewhere on the board
AREF: JP1.AREF; also elsewhere on the board
EXTINT1: J5.7; also elsewhere on the board
GND: J2.1, J3.6, J3.7, J3.8, JP1.GND@1 (GND), JP1.GND@2 (GND), JP1.GND@3 (GND); also elsewhere on the board
GPIO2: JP1.D2; also elsewhere on the board
GPIO3: JP1.D3 (*D3); also elsewhere on the board
GPIO4: JP1.D4; also elsewhere on the board
GPIO5: JP1.D5 (*D5); also elsewhere on the board
GPIO6: JP1.D6 (*D6); also elsewhere on the board
GPIO7: JP1.D7; also elsewhere on the board
GPIO8: JP1.D8; also elsewhere on the board
LIGHT_!INT: J5.6; also elsewhere on the board
MISO: J2.8; also elsewhere on the board
MOSI: J2.7; also elsewhere on the board
NRF_GPIO: J5.8; also elsewhere on the board
NRF_INT: J3.3; also elsewhere on the board
NRF_SWDIO: J6.3; also elsewhere on the board
RF233_!RST: J6.2; also elsewhere on the board
RF233_IRQ: J6.5; also elsewhere on the board
RF233_SLP: J6.1; also elsewhere on the board
SCK: J2.6; also elsewhere on the board
SPI_NCS0: J2.2; also elsewhere on the board
SPI_NCS1: J2.3; also elsewhere on the board
SPI_NCS2: J2.5; also elsewhere on the board
SPI_NCS3: J2.4; also elsewhere on the board
TRNG_EN: J3.5; also elsewhere on the board
TRNG_OUT: J3.4; also elsewhere on the board
TWI1_SCL: JP1.SCL; also elsewhere on the board
TWI1_SDA: JP1.SDA; also elsewhere on the board
TWI2_SCL: J2.10; also elsewhere on the board
TWI2_SDA: J3.1; also elsewhere on the board
USART0_CLK: JP1.D13; also elsewhere on the board
USART0_CTS: JP1.D9 (*D9); also elsewhere on the board
USART0_RTS: JP1.D10 (*D10); also elsewhere on the board
USART0_RX: JP1.D12; also elsewhere on the board
USART0_TX: JP1.D11 (*D11); also elsewhere on the board
USART2_CLK: J3.2; also elsewhere on the board
USART2_CTS: J5.4; also elsewhere on the board
USART2_RTS: J5.5; also elsewhere on the board
USART2_RX: J5.3; also elsewhere on the board
USART2_TX: J5.2; also elsewhere on the board
USART3_RTS: J6.4; also elsewhere on the board
USART3_RX: JP1.D0; also elsewhere on the board
USART3_TX: JP1.D1; also elsewhere on the board
USER_BTN: J2.9; also elsewhere on the board
VCC_EXT_5V: JP1.5V, JP1.VIN; also elsewhere on the board
VCC_MCU_3V3: JP1.3.3V, JP1.IOREF; also elsewhere on the board

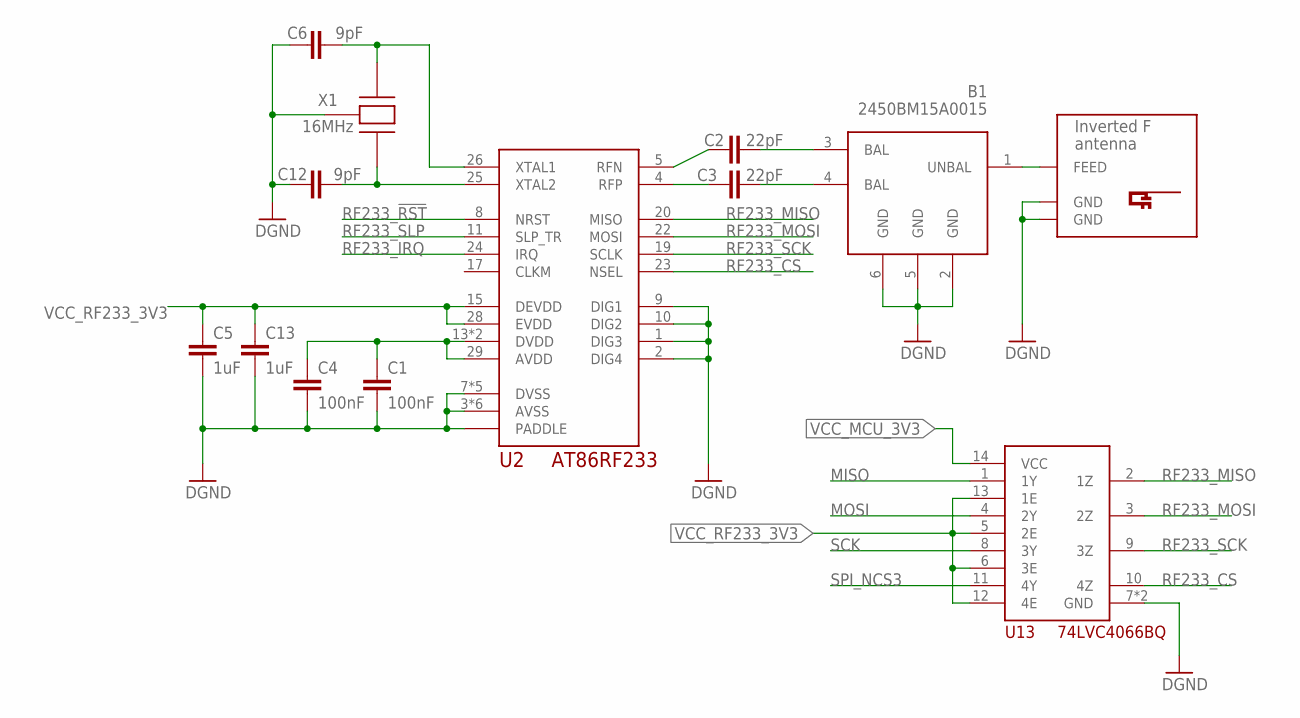
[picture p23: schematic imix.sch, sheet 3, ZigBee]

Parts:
B1: 2450BM15A0015; BALUN0805
C1, C4: 100nF; C0603
C2, C3: 22pF; C0603
C5, C13: 1uF; C0603
C6, C12: 9pF; C0603
U2: AT86RF233; 32QN2
U13: 74LVC4066BQ; DHVQFN14
U$1: INVERTED_F_ANTENNA-2; DN007-2
X1: 16MHz; CTS_405_SERIES

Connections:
GND: B1.2 (GND), B1.5 (GND), B1.6 (GND), C1.2, C4.2, C5.2, C6.1, C12.1, C13.2, U2.1 (DIG3), U2.2 (DIG4), U2.3 (AVSS), U2.6 (AVSS), U2.7 (DVSS), U2.9 (DIG1), U2.10 (DIG2), U2.12 (DVSS), U2.16 (DVSS), U2.18 (DVSS), U2.21 (DVSS), U2.27 (AVSS), U2.30 (AVSS), U2.31 (AVSS), U2.32 (AVSS), U2.PADDLE, U13.7 (GND), U13.PADDLE (GND), U$1.GND, U$1.GND@1 (GND), X1.CASE@2 (CASE), X1.CASE@4 (CASE); also elsewhere on the board
MISO: U13.1 (1Y); also elsewhere on the board
MOSI: U13.4 (2Y); also elsewhere on the board
unnamed: C2.2, U2.5 (RFN)
unnamed: C1.1, C4.1, U2.13 (DVDD), U2.14 (DVDD), U2.29 (AVDD)
unnamed: C6.2, U2.26 (XTAL1), X1.1
unnamed: C3.2, U2.4 (RFP)
unnamed: B1.3 (BAL), C2.1
unnamed: C12.2, U2.25 (XTAL2), X1.3 (2)
unnamed: B1.4 (BAL), C3.1
unnamed: B1.1 (UNBAL), U$1.FEED
RF233_!RST: U2.8 (NRST); also elsewhere on the board
RF233_CS: U2.23 (NSEL), U13.10 (4Z)
RF233_IRQ: U2.24 (IRQ); also elsewhere on the board
RF233_MISO: U2.20 (MISO), U13.2 (1Z)
RF233_MOSI: U2.22 (MOSI), U13.3 (2Z)
RF233_SCK: U2.19 (SCLK), U13.9 (3Z)
RF233_SLP: U2.11 (SLP_TR); also elsewhere on the board
SCK: U13.8 (3Y); also elsewhere on the board
SPI_NCS3: U13.11 (4Y); also elsewhere on the board
VCC_MCU_3V3: U13.14 (VCC); also elsewhere on the board
VCC_RF233_3V3: C5.1, C13.1, U2.15 (DEVDD), U2.28 (EVDD), U13.5 (2E), U13.6 (3E), U13.12 (4E), U13.13 (1E); also elsewhere on the board

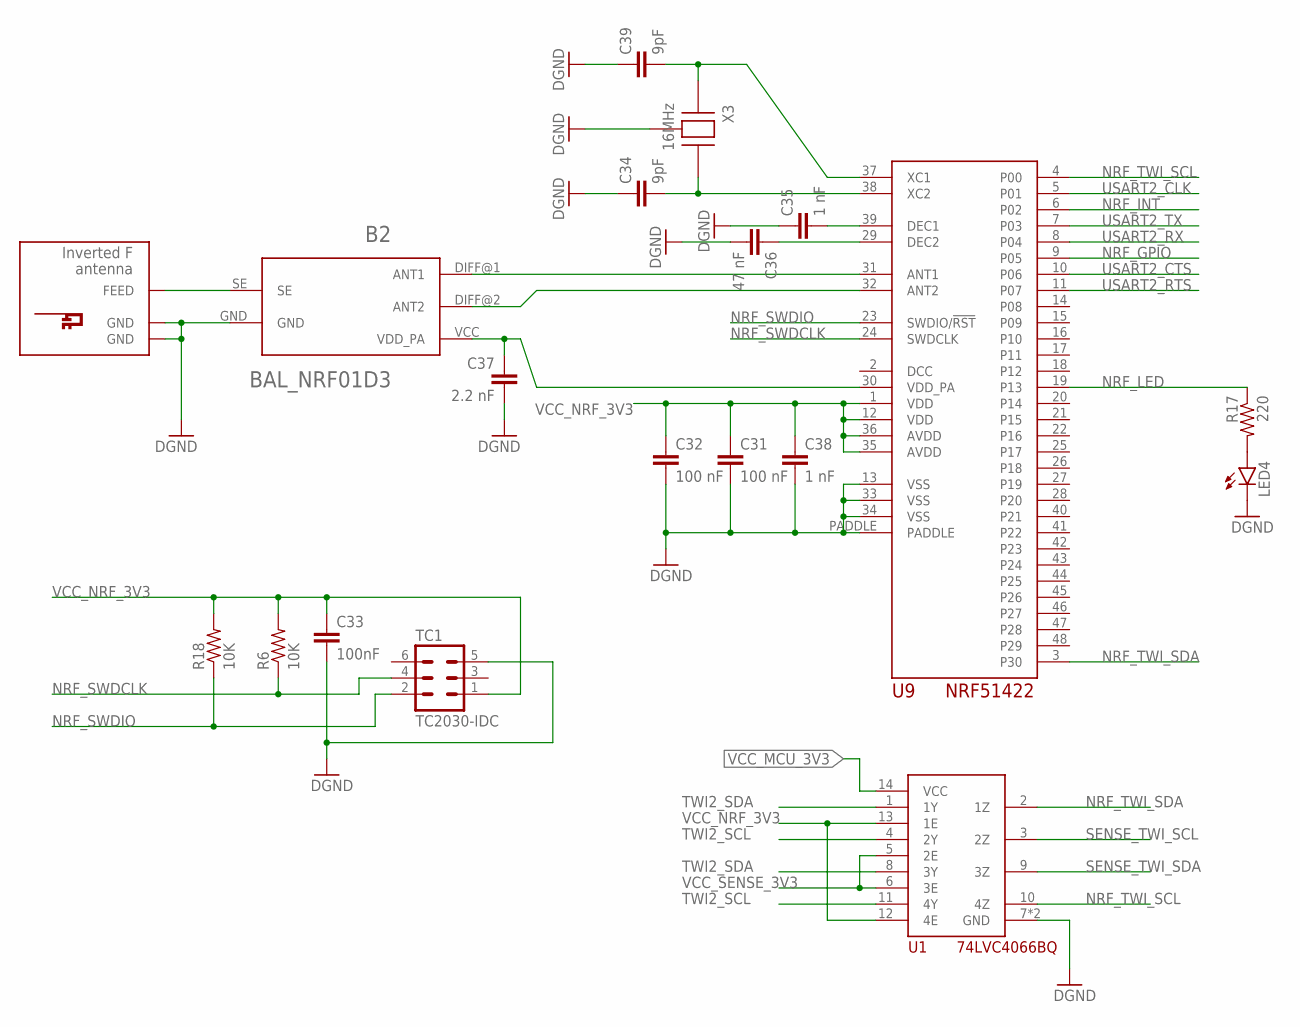
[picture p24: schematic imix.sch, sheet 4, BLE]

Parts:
B2: BAL_NRF01D3
C31, C32: 100 nF; C0603
C33: 100nF; C0603
C34, C39: 9pF; C0603
C35, C38: 1 nF; C0603
C36: 47 nF; C0603
C37: 2.2 nF; C0603
LED4: LED-BLUE0603; LED-0603
R6, R18: 10K; 0603-RES
R17: 220; 0603-RES
TC1: TC2030-IDC
U1: 74LVC4066BQ; DHVQFN14
U9: NRF51422; QFN48_6X6
U$4: INVERTED_F_ANTENNA-2; DN007-2
X3: 16MHz; CTS_405_SERIES

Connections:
GND: B2.GND, C31.2, C32.2, C33.2, C34.1, C35.1, C36.2, C37.2, C38.2, C39.1, LED4.C, TC1.5, U1.7 (GND), U1.PADDLE (GND), U9.13 (VSS), U9.33 (VSS), U9.34 (VSS), U9.PADDLE, U$4.GND, U$4.GND@1 (GND), X3.CASE@2 (CASE), X3.CASE@4 (CASE); also elsewhere on the board
unnamed: B2.SE, U$4.FEED
unnamed: B2.VCC (VDD_PA), C37.1, U9.30 (VDD_PA)
unnamed: C34.2, U9.38 (XC2), X3.3 (2)
unnamed: C39.2, U9.37 (XC1), X3.1
unnamed: C35.2, U9.39 (DEC1)
unnamed: C36.1, U9.29 (DEC2)
unnamed: B2.DIFF@1 (ANT1), U9.31 (ANT1)
unnamed: B2.DIFF@2 (ANT2), U9.32 (ANT2)
unnamed: LED4.A, R17.2
NRF_GPIO: U9.9 (P05); also elsewhere on the board
NRF_INT: U9.6 (P02); also elsewhere on the board
NRF_LED: R17.1, U9.19 (P13)
NRF_SWDCLK: R6.1, TC1.4, U9.24 (SWDCLK)
NRF_SWDIO: R18.1, TC1.2, U9.23 (SWDIO/!RST); also elsewhere on the board
NRF_TWI_SCL: U1.10 (4Z), U9.4 (P00)
NRF_TWI_SDA: U1.2 (1Z), U9.3 (P30)
SENSE_TWI_SCL: U1.3 (2Z); also elsewhere on the board
SENSE_TWI_SDA: U1.9 (3Z); also elsewhere on the board
TWI2_SCL: U1.4 (2Y), U1.11 (4Y); also elsewhere on the board
TWI2_SDA: U1.1 (1Y), U1.8 (3Y); also elsewhere on the board
USART2_CLK: U9.5 (P01); also elsewhere on the board
USART2_CTS: U9.10 (P06); also elsewhere on the board
USART2_RTS: U9.11 (P07); also elsewhere on the board
USART2_RX: U9.8 (P04); also elsewhere on the board
USART2_TX: U9.7 (P03); also elsewhere on the board
VCC_MCU_3V3: U1.14 (VCC); also elsewhere on the board
VCC_NRF_3V3: C31.1, C32.1, C33.1, C38.1, R6.2, R18.2, TC1.1, U1.12 (4E), U1.13 (1E), U9.1 (VDD), U9.12 (VDD), U9.35 (AVDD), U9.36 (AVDD); also elsewhere on the board
VCC_SENSE_3V3: U1.5 (2E), U1.6 (3E); also elsewhere on the board

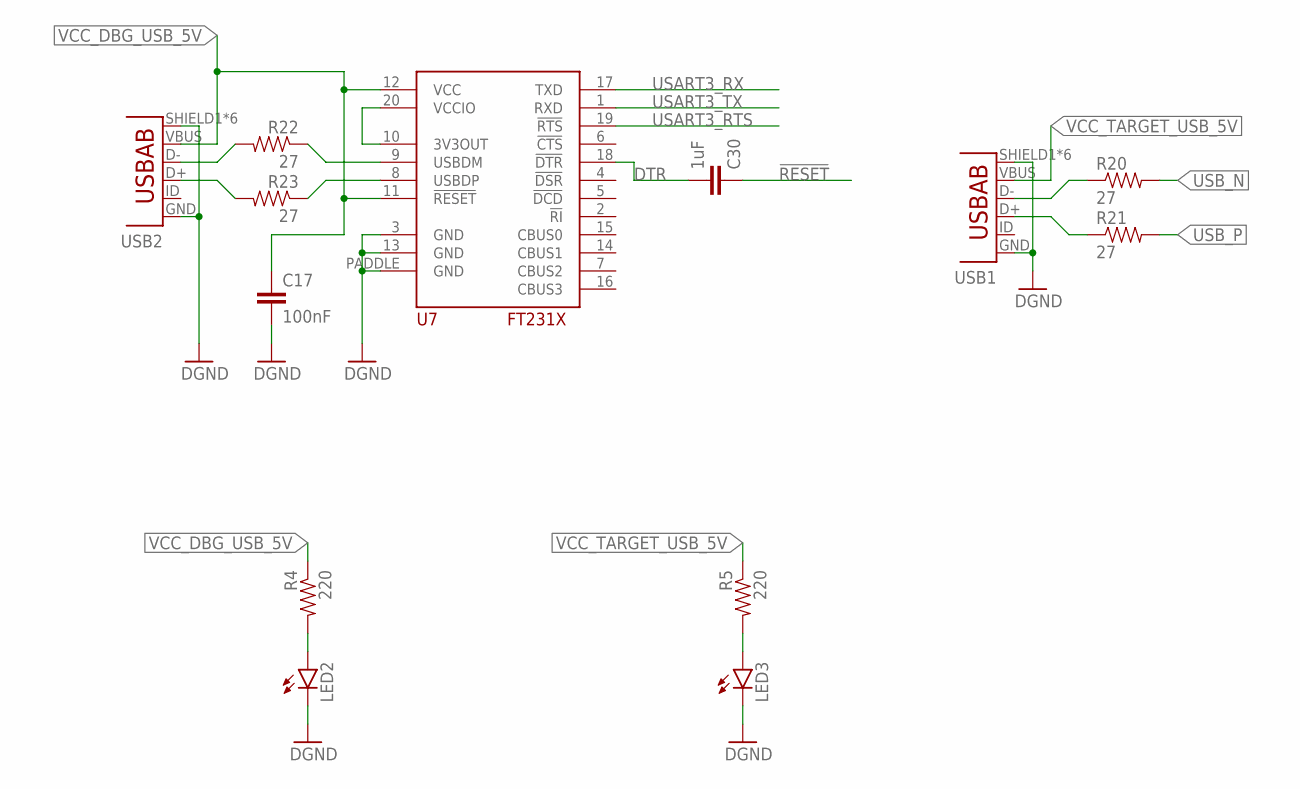
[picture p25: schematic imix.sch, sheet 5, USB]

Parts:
C17: 100nF; C0603
C30: 1uF; C0603
LED2, LED3: LED-BLUE0603; LED-0603
R4, R5: 220; 0603-RES
R20, R21, R22, R23: 27; 0603-RES
U7: FT231X; QFN20
USB1, USB2: USB-AB; USB-AB-MICRO-SMD

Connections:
!RESET: C30.1; also elsewhere on the board
DTR: C30.2, U7.18 (!DTR)
GND: C17.2, LED2.C, LED3.C, U7.3 (GND), U7.13 (GND), U7.PADDLE (GND), USB1.GND, USB1.SHIELD1 (SHIELD), USB1.SHIELD2 (SHIELD), USB1.SHIELD3 (SHIELD), USB1.SHIELD4 (SHIELD), USB1.SHIELD5 (SHIELD), USB1.SHIELD6 (SHIELD), USB2.GND, USB2.SHIELD1 (SHIELD), USB2.SHIELD2 (SHIELD), USB2.SHIELD3 (SHIELD), USB2.SHIELD4 (SHIELD), USB2.SHIELD5 (SHIELD), USB2.SHIELD6 (SHIELD); also elsewhere on the board
unnamed: R20.1, USB1.D-
unnamed: U7.10 (3V3OUT), U7.20 (VCCIO)
unnamed: LED2.A, R4.2
unnamed: LED3.A, R5.2
unnamed: R22.2, USB2.D-
unnamed: R22.1, U7.9 (USBDM)
unnamed: R23.2, USB2.D+
unnamed: R23.1, U7.8 (USBDP)
unnamed: R21.1, USB1.D+
USART3_RTS: U7.19 (!RTS); also elsewhere on the board
USART3_RX: U7.17 (TXD); also elsewhere on the board
USART3_TX: U7.1 (RXD); also elsewhere on the board
USB_N: R20.2; also elsewhere on the board
USB_P: R21.2; also elsewhere on the board
VCC_DBG_USB_5V: C17.1, R4.1, U7.11 (!RESET), U7.12 (VCC), USB2.VBUS; also elsewhere on the board
VCC_TARGET_USB_5V: R5.1, USB1.VBUS; also elsewhere on the board

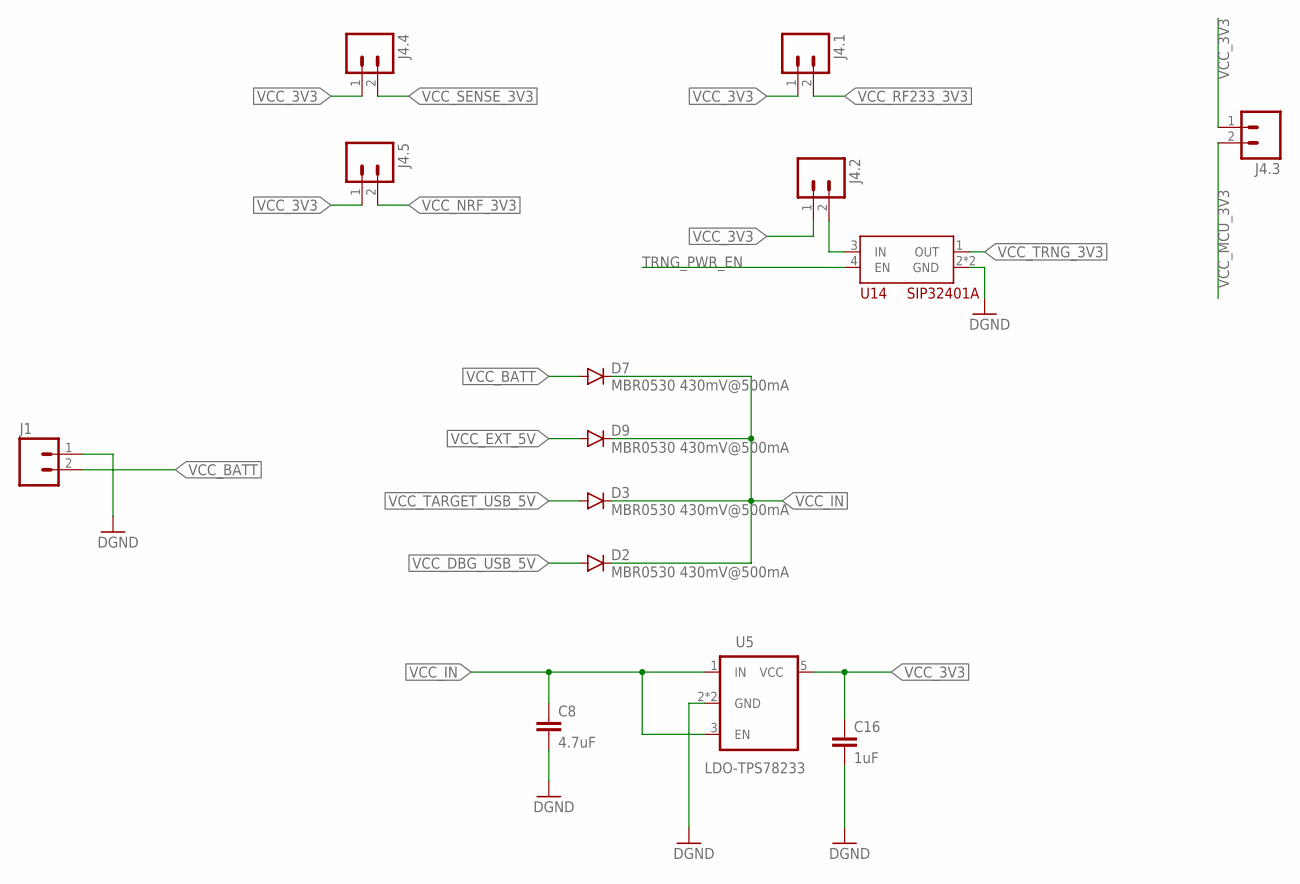
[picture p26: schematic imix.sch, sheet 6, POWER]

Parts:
C8: 4.7uF; C0603
C16: 1uF; C0603
D2, D3, D7, D9: MBR0530 430mV@500mA; SOD-123
J1: M02-JST-2MM-SMT; JST-2-SMD
J4.1, J4.2, J4.3, J4.4, J4.5: M021X02_NO_SILK; 1X02_NO_SILK
U5: LDO-TPS78233; SOT23-5
U14: SIP32401A; TDFN4

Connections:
GND: C8.2, C16.2, J1.1 (2), U5.2 (GND), U5.4 (GND), U14.2 (GND), U14.PADDLE (GND); also elsewhere on the board
unnamed: J4.2.2, U14.3 (IN)
TRNG_PWR_EN: U14.4 (EN); also elsewhere on the board
VCC_3V3: C16.1, J4.1.1, J4.2.1, J4.3.1, J4.4.1, J4.5.1, U5.5 (VCC)
VCC_BATT: D7.A, J1.2 (1)
VCC_DBG_USB_5V: D2.A; also elsewhere on the board
VCC_EXT_5V: D9.A; also elsewhere on the board
VCC_IN: C8.1, D2.C, D3.C, D7.C, D9.C, U5.1 (IN), U5.3 (EN)
VCC_MCU_3V3: J4.3.2; also elsewhere on the board
VCC_NRF_3V3: J4.5.2; also elsewhere on the board
VCC_RF233_3V3: J4.1.2; also elsewhere on the board
VCC_SENSE_3V3: J4.4.2; also elsewhere on the board
VCC_TARGET_USB_5V: D3.A; also elsewhere on the board
VCC_TRNG_3V3: U14.1 (OUT); also elsewhere on the board

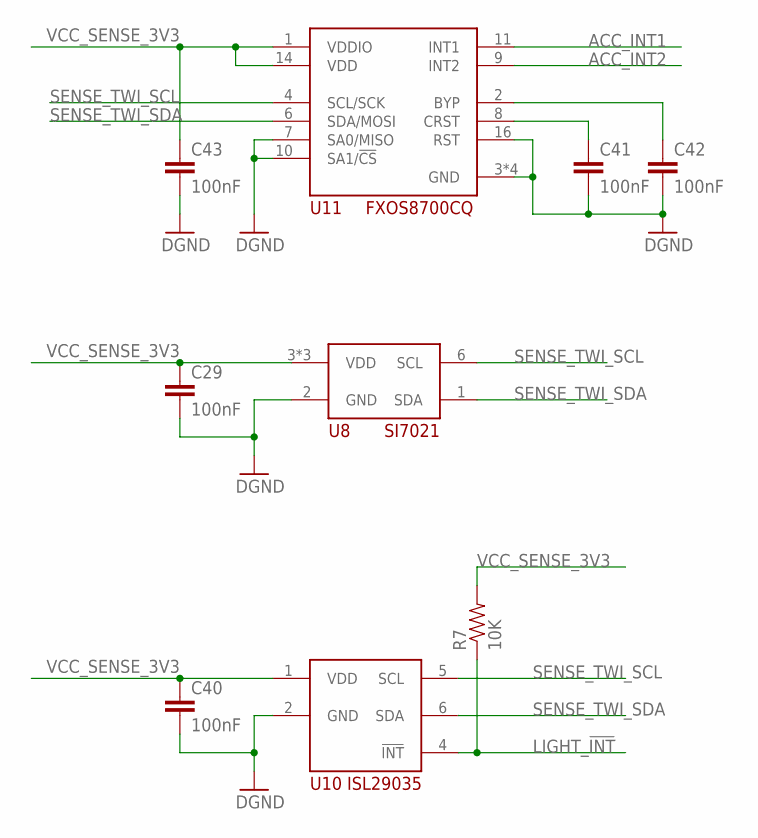
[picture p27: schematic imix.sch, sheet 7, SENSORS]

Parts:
C29, C40, C41, C42, C43: 100nF; C0603
R7: 10K; 0603-RES
U8: SI7021
U10: ISL29035
U11: FX0S8700CQ; QFN16_3,5

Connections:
ACC_INT1: U11.11 (INT1); also elsewhere on the board
ACC_INT2: U11.9 (INT2); also elsewhere on the board
GND: C29.2, C40.2, C41.2, C42.2, C43.2, U8.2 (GND), U10.2 (GND), U11.3 (GND), U11.5 (GND), U11.7 (SA0/MISO), U11.10 (SA1/!CS), U11.12 (GND), U11.13 (GND), U11.16 (RST); also elsewhere on the board
LIGHT_!INT: R7.1, U10.4 (!INT); also elsewhere on the board
unnamed: C41.1, U11.8 (CRST)
unnamed: C42.1, U11.2 (BYP)
SENSE_TWI_SCL: U8.6 (SCL), U10.5 (SCL), U11.4 (SCL/SCK); also elsewhere on the board
SENSE_TWI_SDA: U8.1 (SDA), U10.6 (SDA), U11.6 (SDA/MOSI); also elsewhere on the board
VCC_SENSE_3V3: C29.1, C40.1, C43.1, R7.2, U8.3 (VDD), U8.4 (VDD), U8.5 (VDD), U10.1 (VDD), U11.1 (VDDIO), U11.14 (VDD); also elsewhere on the board

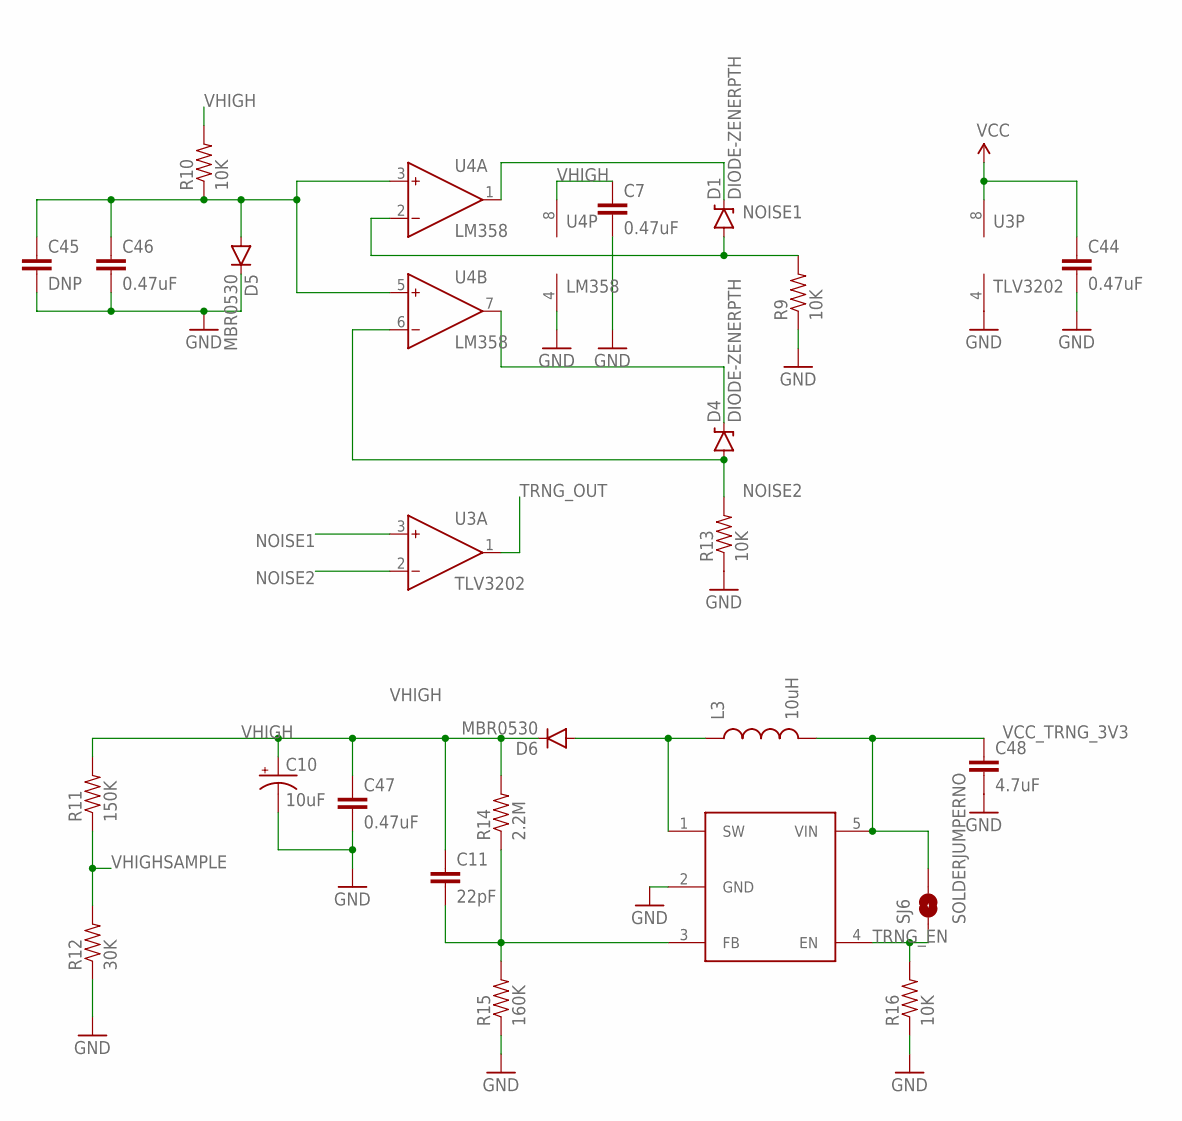
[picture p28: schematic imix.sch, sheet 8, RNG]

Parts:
C7, C44, C46: 0.47uF; C0603
C10: 10uF; PANASONIC_C
C11: 22pF; C0603
C45: DNP; C0603
C47: 0.47uF; C0603-NOSILK
C48: 4.7uF; C0603-NOSILK
D1, D4: DIODE-ZENERPTH; DIODE-ZENER; MPN 610-1N759A
D5, D6: MBR0530; SOD-123
L3: 10uH; 0805
R9, R10, R13, R16: 10K; 0603-RES
R11: 150K; 0603-RES
R12: 30K; 0603-RES
R14: 2.2M; 0603-RES
R15: 160K; 0603-RES
SJ6: SOLDERJUMPERNO; SJ_2S-NO
U3: TLV3202; SO8
U4: LM358; SO8
U12: 296-12686-1-ND; SOT23-5

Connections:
GND: C7.2, C10.-, C44.2, C45.2, C46.2, C47.2, C48.2, D5.C, R9.1, R12.1, R13.1, R15.1, R16.1, U3.4 (V-), U4.4 (V-), U12.2 (GND); also elsewhere on the board
unnamed: D6.A, L3.1, U12.1 (SW)
unnamed: C11.2, R14.1, R15.2, U12.3 (FB)
unnamed: D1.P$1 (C), U4.1 (OUT)
unnamed: D4.P$1 (C), U4.7 (OUT)
unnamed: C45.1, C46.1, D5.A, R10.1, U4.3 (IN+), U4.5 (IN+)
NOISE1: D1.P$2 (A), R9.2, U3.3 (IN+), U4.2 (IN-)
NOISE2: D4.P$2 (A), R13.2, U3.2 (IN-), U4.6 (IN-)
TRNG_EN: R16.2, SJ6.1, U12.4 (EN); also elsewhere on the board
TRNG_OUT: U3.1 (OUT); also elsewhere on the board
VCC_TRNG_3V3: C44.1, C48.1, L3.2, SJ6.2, U3.8 (V+), U12.5 (VIN); also elsewhere on the board
VHIGH: C7.1, C10.+, C11.1, C47.1, D6.C, R10.2, R11.2, R14.2, U4.8 (V+)
VHIGHSAMPLE: R11.1, R12.2; also elsewhere on the board

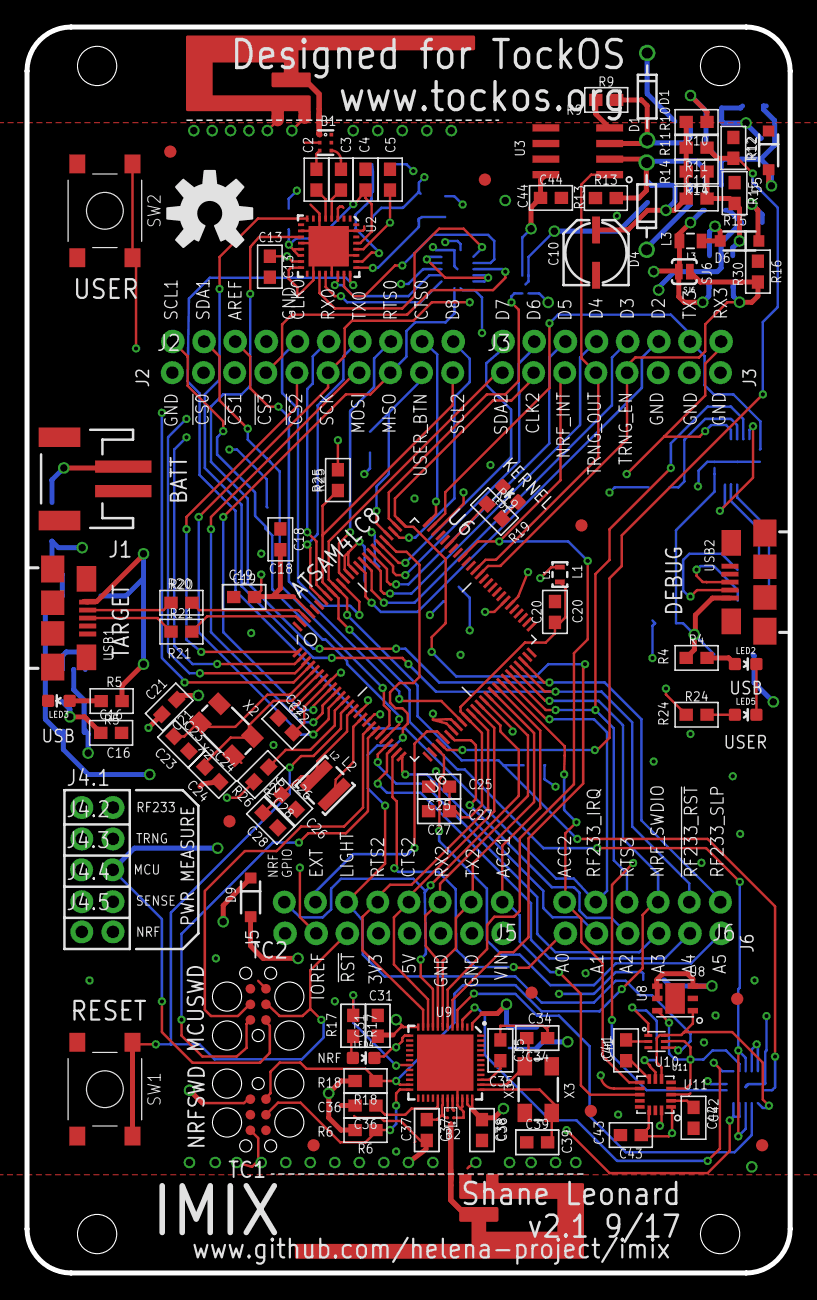
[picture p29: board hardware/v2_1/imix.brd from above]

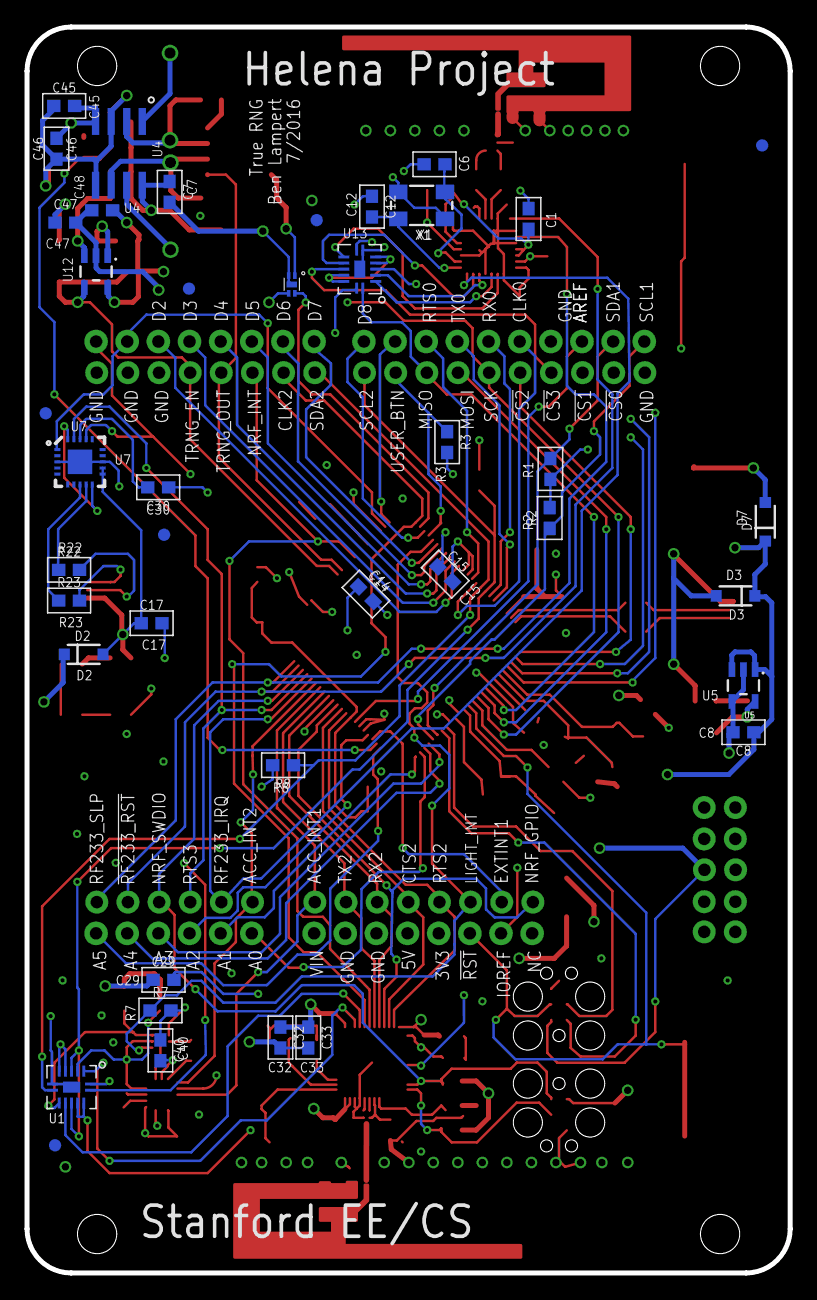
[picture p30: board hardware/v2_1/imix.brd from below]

Board: 4 copper layers, 62.2 x 101.6 mm, 144 parts (41 on the bottom side), 128 nets.

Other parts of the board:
U$9: OSHW-LOGO-L

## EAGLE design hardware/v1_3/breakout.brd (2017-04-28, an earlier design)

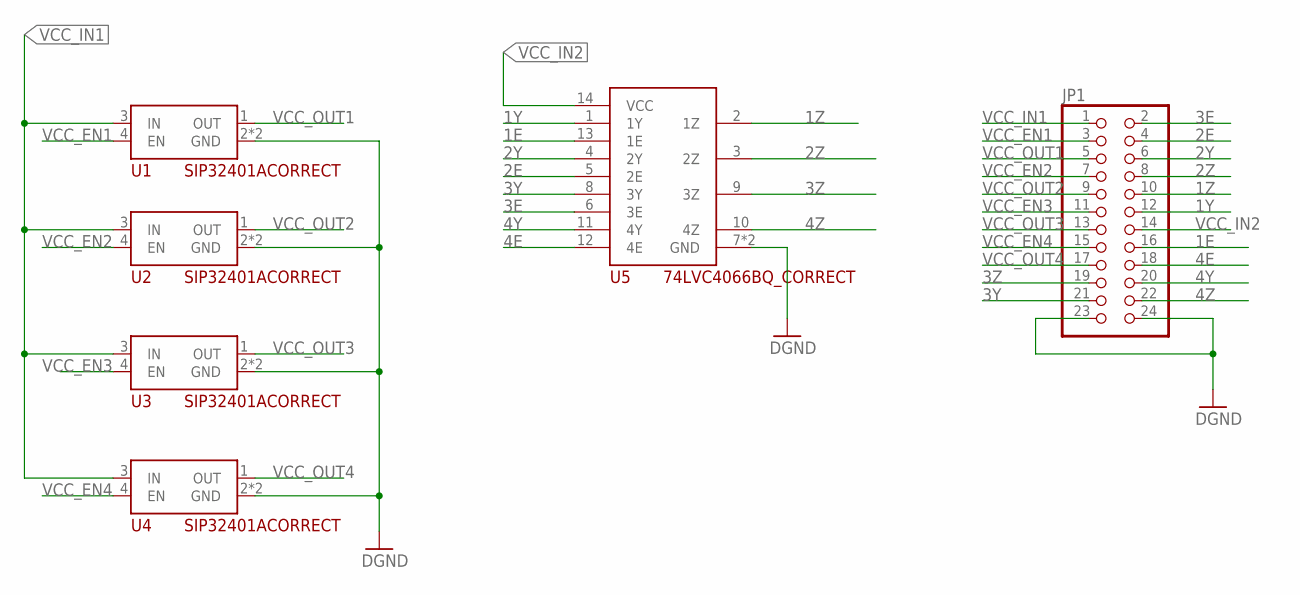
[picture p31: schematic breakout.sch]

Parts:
JP1: PINHD-2X12/90; 2X12/90
U1, U2, U3, U4: SIP32401ACORRECT; TDFN4_CORRECT
U5: 74LVC4066BQ_CORRECT; DHVQFN14_CORRECTED

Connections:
1E: JP1.16, U5.13 (1E)
1Y: JP1.12, U5.1 (1Y)
1Z: JP1.10, U5.2 (1Z)
2E: JP1.4, U5.5 (2E)
2Y: JP1.6, U5.4 (2Y)
2Z: JP1.8, U5.3 (2Z)
3E: JP1.2, U5.6 (3E)
3Y: JP1.21, U5.8 (3Y)
3Z: JP1.19, U5.9 (3Z)
4E: JP1.18, U5.12 (4E)
4Y: JP1.20, U5.11 (4Y)
4Z: JP1.22, U5.10 (4Z)
GND: JP1.23, JP1.24, U1.2 (GND), U1.PADDLE (GND), U2.2 (GND), U2.PADDLE (GND), U3.2 (GND), U3.PADDLE (GND), U4.2 (GND), U4.PADDLE (GND), U5.7 (GND), U5.PADDLE (GND)
VCC_EN1: JP1.3, U1.4 (EN)
VCC_EN2: JP1.7, U2.4 (EN)
VCC_EN3: JP1.11, U3.4 (EN)
VCC_EN4: JP1.15, U4.4 (EN)
VCC_IN1: JP1.1, U1.3 (IN), U2.3 (IN), U3.3 (IN), U4.3 (IN)
VCC_IN2: JP1.14, U5.14 (VCC)
VCC_OUT1: JP1.5, U1.1 (OUT)
VCC_OUT2: JP1.9, U2.1 (OUT)
VCC_OUT3: JP1.13, U3.1 (OUT)
VCC_OUT4: JP1.17, U4.1 (OUT)

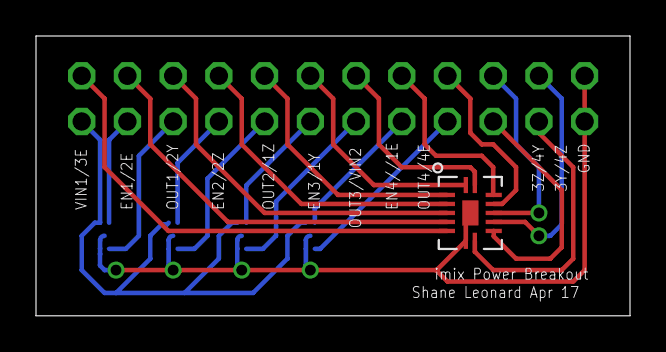
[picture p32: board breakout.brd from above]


Board: 2 copper layers, 33.0 x 15.5 mm, 6 parts (4 on the bottom side), 23 nets.

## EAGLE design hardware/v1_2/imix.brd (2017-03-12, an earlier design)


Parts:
C15, C19, C20, C21, C22, C27, C28, C50: 100nF; C0603
C18: 10uF; C0603
C23, C24: 13pF; C0603
C25: 4.7uF; C0603
C26: 6.8uF; C0603
L1: BLM18HE152SN1; L0603
L2: 22uH LQH3NPN220MJ0; L1212
LED5: USER; LED-0603
R1, R2, R25, R38: 4.7K; 0603-RES
R3, R33: 100K; 0603-RES
R24: 1K; 0603-RES
R26: 10K; 0603-RES
RESET: TAC_SWITCHSMD; TACTILE-SWITCH-SMD
TC2: TC2030-IDC
U6: ATSAM4LCX_100; TQFP100
USER: TAC_SWITCHSMD; TACTILE-SWITCH-SMD
X2: 16MHz; CTS_405_SERIES

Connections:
!NRF_PWR_EN: U6.60 (PC17); also elsewhere on the board
!RESET: R33.1, RESET.3, RESET.4, TC2.3, U6.13 (RESET_N); also elsewhere on the board
!RF233_PWR_EN: U6.61 (PC18); also elsewhere on the board
!SENSE_PWR_EN: U6.59 (PC16); also elsewhere on the board
!TRNG_PWR_EN: U6.62 (PC19); also elsewhere on the board
ACC_INT1: U6.42 (PC13); also elsewhere on the board
ACC_INT2: U6.43 (PC14); also elsewhere on the board
ADCIFE1: U6.25 (PA05); also elsewhere on the board
ADCIFE2: U6.31 (PA07); also elsewhere on the board
ADCIFE3: U6.22 (PB02); also elsewhere on the board
ADCIFE4: U6.23 (PB03); also elsewhere on the board
ADCIFE5: U6.28 (PB04); also elsewhere on the board
ADCIFE6: U6.29 (PB05); also elsewhere on the board
AREF: U6.34 (ADVREFP); also elsewhere on the board
BIASH: U6.54 (BIASH)
BIASL: U6.55 (BIASL)
BUCK/BOOST: R26.1, U6.12 (PA02)
EXTINT1: U6.30 (PA06); also elsewhere on the board
GND: C15.1, C18.1, C19.1, C20.2, C21.2, C22.1, C23.2, C24.2, C25.2, C26.2, C27.2, C28.2, C50.1, LED5.C, RESET.1, RESET.2, TC2.5, U6.7 (GND), U6.15 (GND), U6.32 (ADVREFN), U6.33 (GNDANA), U6.56 (GND), U6.100 (GND), USER.1, USER.2, X2.CASE@2 (CASE), X2.CASE@4 (CASE); also elsewhere on the board
GPIO2: U6.86 (PC31); also elsewhere on the board
GPIO3: U6.85 (PC30); also elsewhere on the board
GPIO4: U6.84 (PC29); also elsewhere on the board
GPIO5: U6.83 (PC28); also elsewhere on the board
GPIO6: U6.82 (PC27); also elsewhere on the board
GPIO7: U6.81 (PC26); also elsewhere on the board
GPIO8: U6.80 (PC25); also elsewhere on the board
LIGHT_!INT: U6.24 (PA04); also elsewhere on the board
MCU_VOUT3.3: L2.2, U6.16 (VDDOUT)
MISO: U6.9 (PC04); also elsewhere on the board
MOSI: U6.10 (PC05); also elsewhere on the board
unnamed: C20.1, C25.1, C27.1, L1.1, U6.35 (VDDANA)
unnamed: C24.1, U6.6 (PA01), X2.1
unnamed: C26.1, C28.1, L2.1, U6.14 (VDDCORE)
unnamed: C23.1, U6.5 (PA00), X2.3 (2)
unnamed: LED5.A, R24.2
NRF_GPIO: U6.38 (PC09); also elsewhere on the board
NRF_INT: U6.67 (PA17); also elsewhere on the board
NRF_SWDIO: U6.46 (PB07); also elsewhere on the board
RF233_!RST: U6.47 (PA09); also elsewhere on the board
RF233_IRQ: U6.44 (PA08); also elsewhere on the board
RF233_SLP: U6.48 (PA10); also elsewhere on the board
SCK: U6.11 (PC06); also elsewhere on the board
SPI_NCS0: U6.4 (PC03); also elsewhere on the board
SPI_NCS1: U6.3 (PC02); also elsewhere on the board
SPI_NCS2: U6.1 (PC00); also elsewhere on the board
SPI_NCS3: U6.2 (PC01); also elsewhere on the board
SWDCLK/TCK: TC2.4, U6.18 (TCK)
SWDIO/TMS: TC2.2, U6.19 (PA03)
TRNG_EN: U6.63 (PA13); also elsewhere on the board
TRNG_OUT: U6.64 (PA14); also elsewhere on the board
TWI1_SCL: R2.1, U6.21 (PB01); also elsewhere on the board
TWI1_SDA: R1.1, U6.20 (PB00); also elsewhere on the board
TWI2_SCL: R25.1, U6.92 (PA22); also elsewhere on the board
TWI2_SDA: R38.1, U6.91 (PA21); also elsewhere on the board
USART0_CLK: U6.90 (PB13); also elsewhere on the board
USART0_CTS: U6.75 (PB11); also elsewhere on the board
USART0_RTS: U6.89 (PB12); also elsewhere on the board
USART0_RX: U6.93 (PB14); also elsewhere on the board
USART0_TX: U6.94 (PB15); also elsewhere on the board
USART2_CLK: U6.76 (PA18); also elsewhere on the board
USART2_CTS: U6.37 (PC08); also elsewhere on the board
USART2_RTS: U6.36 (PC07); also elsewhere on the board
USART2_RX: U6.40 (PC11); also elsewhere on the board
USART2_TX: U6.41 (PC12); also elsewhere on the board
USART3_RTS: U6.45 (PB06); also elsewhere on the board
USART3_RX: U6.73 (PB09); also elsewhere on the board
USART3_TX: U6.74 (PB10); also elsewhere on the board
USB_N: U6.98 (PA25); also elsewhere on the board
USB_P: U6.99 (PA26); also elsewhere on the board
USER_BTN: R3.1, U6.79 (PC24), USER.3, USER.4; also elsewhere on the board
USER_LED: R24.1, U6.39 (PC10); also elsewhere on the board
VCC_MCU_3V3: C15.2, C18.2, C19.2, C21.1, C22.2, C50.2, L1.2, R1.2, R2.2, R3.2, R26.2, R33.2, TC2.1, U6.8 (VDDIO), U6.17 (VDDIN), U6.57 (VLCDIN), U6.87 (VDDIO), U6.88 (VDDIO), U6.97 (VDDIO); also elsewhere on the board
VCC_SENSE_3V3: R25.2, R38.2; also elsewhere on the board


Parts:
F1, F2, F3, F4, F5, F6, F7, F8, F9, F10: FIDUCIAL
J1: M10X2ROUND_NOSILK; 2X10_ROUND_NOSILK
J2: M10NO_SILK_PTH_FEMALE; 1X10_NO_SILK
J2_3_5_AND_6: ARDUINO_R3NO_HOLES; ARDUINO_R3_NO_HOLES
J3, J5: M08NO_SILK_FEMALE_PTH; 1X08_NO_SILK
J6: M06NO_SILK_FEMALE_PTH; 1X06_NO_SILK

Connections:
!NRF_PWR_EN: J3.7; also elsewhere on the board
!RESET: J1.15, J2_3_5_AND_6.RESET@1 (!RESET!), J2_3_5_AND_6.RESET@2 (!RESET!); also elsewhere on the board
!RF233_PWR_EN: J3.6; also elsewhere on the board
!SENSE_PWR_EN: J3.8; also elsewhere on the board
ACC_INT1: J5.1; also elsewhere on the board
ACC_INT2: J6.6; also elsewhere on the board
ADCIFE1: J2_3_5_AND_6.A0; also elsewhere on the board
ADCIFE2: J2_3_5_AND_6.A1; also elsewhere on the board
ADCIFE3: J2_3_5_AND_6.A2; also elsewhere on the board
ADCIFE4: J2_3_5_AND_6.A3; also elsewhere on the board
ADCIFE5: J2_3_5_AND_6.A4; also elsewhere on the board
ADCIFE6: J2_3_5_AND_6.A5; also elsewhere on the board
AREF: J2.3, J2_3_5_AND_6.AREF; also elsewhere on the board
EXTINT1: J1.6; also elsewhere on the board
FTDI0: J1.17; also elsewhere on the board
FTDI1: J1.18; also elsewhere on the board
FTDI2: J1.19; also elsewhere on the board
FTDI3: J1.20; also elsewhere on the board
GND: J1.14, J1.16, J2.4, J2_3_5_AND_6.GND@1 (GND), J2_3_5_AND_6.GND@2 (GND), J2_3_5_AND_6.GND@3 (GND), J2_3_5_AND_6.GND@4 (GND), J3.2, J5.7, J5.8; also elsewhere on the board
GPIO2: J2_3_5_AND_6.D2; also elsewhere on the board
GPIO3: J2_3_5_AND_6.D3 (*D3); also elsewhere on the board
GPIO4: J2_3_5_AND_6.D4; also elsewhere on the board
GPIO5: J2_3_5_AND_6.D5 (*D5); also elsewhere on the board
GPIO6: J2_3_5_AND_6.D6 (*D6); also elsewhere on the board
GPIO7: J2_3_5_AND_6.D7; also elsewhere on the board
GPIO8: J2_3_5_AND_6.D8; also elsewhere on the board
LIGHT_!INT: J5.6; also elsewhere on the board
MISO: J1.9; also elsewhere on the board
MOSI: J1.11; also elsewhere on the board
NRF_GPIO: J1.12; also elsewhere on the board
NRF_INT: J3.3; also elsewhere on the board
NRF_SWDIO: J6.3; also elsewhere on the board
RF233_!RST: J6.2; also elsewhere on the board
RF233_IRQ: J6.5; also elsewhere on the board
RF233_SLP: J6.1; also elsewhere on the board
SCK: J1.13; also elsewhere on the board
SPI_NCS0: J1.7; also elsewhere on the board
SPI_NCS1: J1.5; also elsewhere on the board
SPI_NCS2: J1.1; also elsewhere on the board
SPI_NCS3: J1.3; also elsewhere on the board
TRNG_EN: J3.5; also elsewhere on the board
TRNG_OUT: J3.4; also elsewhere on the board
TWI1_SCL: J1.4, J2.1, J2_3_5_AND_6.SCL; also elsewhere on the board
TWI1_SDA: J1.2, J2.2, J2_3_5_AND_6.SDA; also elsewhere on the board
TWI2_SCL: J2.7; also elsewhere on the board
TWI2_SDA: J2.8; also elsewhere on the board
USART0_CLK: J2_3_5_AND_6.D13, J2_3_5_AND_6.SCK; also elsewhere on the board
USART0_CTS: J2_3_5_AND_6.D9 (*D9); also elsewhere on the board
USART0_RTS: J2_3_5_AND_6.D10 (*D10); also elsewhere on the board
USART0_RX: J2.5, J2_3_5_AND_6.D12, J2_3_5_AND_6.MISO; also elsewhere on the board
USART0_TX: J2.6, J2_3_5_AND_6.D11 (*D11), J2_3_5_AND_6.MOSI; also elsewhere on the board
USART2_CLK: J2.9; also elsewhere on the board
USART2_CTS: J5.4; also elsewhere on the board
USART2_RTS: J5.5; also elsewhere on the board
USART2_RX: J5.3; also elsewhere on the board
USART2_TX: J5.2; also elsewhere on the board
USART3_RTS: J6.4; also elsewhere on the board
USART3_RX: J2_3_5_AND_6.D0, J3.1; also elsewhere on the board
USART3_TX: J2.10, J2_3_5_AND_6.D1; also elsewhere on the board
USER_BTN: J1.10; also elsewhere on the board
USER_LED: J1.8; also elsewhere on the board
VCC_3V3: J2_3_5_AND_6.3.3V, J2_3_5_AND_6.IOREF; also elsewhere on the board
VCC_EXT_5V: J2_3_5_AND_6.5V, J2_3_5_AND_6.VCC, J2_3_5_AND_6.VIN; also elsewhere on the board


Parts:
B1: 2450BM15A0015; BALUN0805
C1, C4: 100nF; C0603
C2, C3: 22pF; C0603
C5, C13: 1uF; C0603
C6, C12: 13pF; C0603
U2: AT86RF233; 32QN2
U$1: INVERTED_F_ANTENNA-2; DN007-2
X1: 16MHz; CTS_405_SERIES

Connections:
GND: B1.2 (GND), B1.5 (GND), B1.6 (GND), C1.2, C4.2, C5.2, C6.1, C12.1, C13.2, U2.1 (DIG3), U2.2 (DIG4), U2.3 (AVSS), U2.6 (AVSS), U2.7 (DVSS), U2.9 (DIG1), U2.10 (DIG2), U2.12 (DVSS), U2.16 (DVSS), U2.18 (DVSS), U2.21 (DVSS), U2.27 (AVSS), U2.30 (AVSS), U2.31 (AVSS), U2.32 (AVSS), U2.PADDLE, U$1.GND, U$1.GND@1 (GND), X1.CASE@2 (CASE), X1.CASE@4 (CASE); also elsewhere on the board
MISO: U2.20 (MISO); also elsewhere on the board
MOSI: U2.22 (MOSI); also elsewhere on the board
unnamed: C2.2, U2.5 (RFN)
unnamed: C1.1, C4.1, U2.13 (DVDD), U2.14 (DVDD), U2.29 (AVDD)
unnamed: C6.2, U2.26 (XTAL1), X1.1
unnamed: C3.2, U2.4 (RFP)
unnamed: B1.3 (BAL), C2.1
unnamed: C12.2, U2.25 (XTAL2), X1.3 (2)
unnamed: B1.4 (BAL), C3.1
unnamed: B1.1 (UNBAL), U$1.FEED
RF233_!RST: U2.8 (NRST); also elsewhere on the board
RF233_IRQ: U2.24 (IRQ); also elsewhere on the board
RF233_SLP: U2.11 (SLP_TR); also elsewhere on the board
SCK: U2.19 (SCLK); also elsewhere on the board
SPI_NCS3: U2.23 (NSEL); also elsewhere on the board
VCC_RF233_3V3: C5.1, C13.1, U2.15 (DEVDD), U2.28 (EVDD); also elsewhere on the board


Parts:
B2: BAL_NRF01D3
C31, C32: 100 nF; C0603
C33: 100nF; C0603
C34, C39: 13pF; C0603
C35, C38: 1 nF; C0603
C36: 47 nF; C0603
C37: 2.2 nF; C0603
LED4: NRF; LED-0603
R34: 1K; 0603-RES
R35, R36: 10K; 0603-RES
TC1: TC2030-IDC
U9: NRF51422; QFN48_6X6
U$4: INVERTED_F_ANTENNA-2; DN007-2
X3: 16MHz; CTS_405_SERIES

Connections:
GND: B2.GND, C31.2, C32.2, C33.2, C34.1, C35.1, C36.2, C37.2, C38.2, C39.1, LED4.C, TC1.5, U9.13 (VSS), U9.33 (VSS), U9.34 (VSS), U9.PADDLE, U$4.GND, U$4.GND@1 (GND), X3.CASE@2 (CASE), X3.CASE@4 (CASE); also elsewhere on the board
unnamed: B2.SE, U$4.FEED
unnamed: B2.VCC (VDD_PA), C37.1, U9.30 (VDD_PA)
unnamed: C34.2, U9.38 (XC2), X3.3 (2)
unnamed: C39.2, U9.37 (XC1), X3.1
unnamed: C35.2, U9.39 (DEC1)
unnamed: C36.1, U9.29 (DEC2)
unnamed: B2.DIFF@1 (ANT1), U9.31 (ANT1)
unnamed: B2.DIFF@2 (ANT2), U9.32 (ANT2)
unnamed: LED4.A, R34.2
NRF_GPIO: U9.9 (P05); also elsewhere on the board
NRF_INT: U9.6 (P02); also elsewhere on the board
NRF_LED: R34.1, U9.19 (P13)
NRF_SWDCLK: R36.1, TC1.4, U9.24 (SWDCLK)
NRF_SWDIO: R35.1, TC1.2, U9.23 (SWDIO/!RST); also elsewhere on the board
TWI2_SCL: U9.4 (P00); also elsewhere on the board
TWI2_SDA: U9.3 (P30); also elsewhere on the board
USART2_CLK: U9.5 (P01); also elsewhere on the board
USART2_CTS: U9.10 (P06); also elsewhere on the board
USART2_RTS: U9.11 (P07); also elsewhere on the board
USART2_RX: U9.8 (P04); also elsewhere on the board
USART2_TX: U9.7 (P03); also elsewhere on the board
VCC_NRF_3V3: C31.1, C32.1, C33.1, C38.1, R35.2, R36.2, TC1.1, U9.1 (VDD), U9.12 (VDD), U9.35 (AVDD), U9.36 (AVDD); also elsewhere on the board


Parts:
C17: 100nF; C0603
R22, R23, R28, R29: 27; 0603-RES
U7: FT231X; QFN20
USB1, USB2: USB-AB; USB-AB-MICRO-SMD

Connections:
!RESET: U7.18 (!DTR); also elsewhere on the board
FTDI0: U7.15 (CBUS0); also elsewhere on the board
FTDI1: U7.14 (CBUS1); also elsewhere on the board
FTDI2: U7.7 (CBUS2); also elsewhere on the board
FTDI3: U7.16 (CBUS3); also elsewhere on the board
GND: C17.2, U7.3 (GND), U7.13 (GND), U7.PADDLE (GND), USB1.GND, USB1.SHIELD1 (SHIELD), USB1.SHIELD2 (SHIELD), USB1.SHIELD3 (SHIELD), USB1.SHIELD4 (SHIELD), USB1.SHIELD5 (SHIELD), USB1.SHIELD6 (SHIELD), USB2.GND, USB2.SHIELD1 (SHIELD), USB2.SHIELD2 (SHIELD), USB2.SHIELD3 (SHIELD), USB2.SHIELD4 (SHIELD), USB2.SHIELD5 (SHIELD), USB2.SHIELD6 (SHIELD); also elsewhere on the board
unnamed: R28.1, USB1.D-
unnamed: R22.2, USB2.D-
unnamed: R22.1, U7.9 (USBDM)
unnamed: R23.2, USB2.D+
unnamed: R23.1, U7.8 (USBDP)
unnamed: R29.1, USB1.D+
USART3_RTS: U7.19 (!RTS); also elsewhere on the board
USART3_RX: U7.17 (TXD); also elsewhere on the board
USART3_TX: U7.1 (RXD); also elsewhere on the board
USB_N: R28.2; also elsewhere on the board
USB_P: R29.2; also elsewhere on the board
VCC_3V3: C17.1, U7.11 (!RESET), U7.12 (VCC), U7.20 (VCCIO); also elsewhere on the board
VCC_DBG_USB_5V: USB2.VBUS; also elsewhere on the board
VCC_TARGET_USB_5V: USB1.VBUS; also elsewhere on the board


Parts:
BAT1: BATTERY18650; BATTERY_18650-HOLDER
C8: 4.7uF; C0603
C14, C16: 1uF; C0603
D2, D3, D9: NSR1020MW2T3G; SOD-323
J4.1, J4.2, J4.3, J4.4, J4.5: M02PTH; 1X02
LED2: 5V; LED-0603
LED3: 3.3V; LED-0603
Q2, Q3, Q4, Q5: AO3415; SOT23-3
R4, R5, R6, R7, R16, R17: 10K; 0603-RES
R18: DNP; 0603-RES
R20, R21: 1K; 0603-RES
SJ1, SJ2, SJ3, SJ4, SJ7: JUMPER-PAD-2-NC_BY_TRACE; PAD-JUMPER-2-NC_BY_TRACE_YES_SILK
U1: BQ2423X; QFP16_3X3
U5: LDO-TPS78233; SOT23-5

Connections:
!NRF_PWR_EN: Q5.1 (G), R5.2; also elsewhere on the board
!RF233_PWR_EN: Q2.1 (G), R6.2; also elsewhere on the board
!SENSE_PWR_EN: Q4.1 (G), R4.2; also elsewhere on the board
!TRNG_PWR_EN: Q3.1 (G), R7.2; also elsewhere on the board
GND: BAT1.GND@1 (-), C8.2, C14.2, C16.2, LED3.C, R6.1, R16.2, R17.2, R18.2, U1.4 (!CE), U1.5 (EN2), U1.6 (EN1), U1.8 (VSS), U1.14 (TMR), U1.15 (TD), U1.PAD (VSS), U5.2 (GND), U5.4 (GND); also elsewhere on the board
unnamed: J4.2.1, Q3.2 (S), SJ7.2
unnamed: J4.4.1, Q4.2 (S), SJ1.2
unnamed: J4.5.1, Q5.2 (S), SJ2.2
unnamed: J4.1.1, Q2.2 (S), SJ3.2
unnamed: LED3.A, R21.2
unnamed: LED2.C, U1.7 (!PGOOD)
unnamed: LED2.A, R20.2
unnamed: R17.1, U1.1 (TS)
unnamed: R18.1, U1.12 (ILIM)
unnamed: R16.1, U1.16 (ISET)
VCC_3V3: C16.1, J4.1.2, J4.2.2, J4.3.1, J4.4.2, J4.5.2, R4.1, R5.1, R7.1, R21.1, SJ1.1, SJ2.1, SJ3.1, SJ4.1, SJ7.1, U5.5 (VCC); also elsewhere on the board
VCC_BAT: BAT1.PWR@1 (+), U1.2 (BAT), U1.3 (BAT)
VCC_DBG_USB_5V: D2.A; also elsewhere on the board
VCC_EXT_5V: D9.A; also elsewhere on the board
VCC_IN: C14.1, D2.C, D3.C, D9.C, U1.13 (IN)
VCC_LDO: C8.1, R20.1, U1.10 (OUT), U1.11 (OUT), U5.1 (IN), U5.3 (EN)
VCC_MCU_3V3: J4.3.2, SJ4.2; also elsewhere on the board
VCC_NRF_3V3: Q5.3 (D); also elsewhere on the board
VCC_RF233_3V3: Q2.3 (D); also elsewhere on the board
VCC_SENSE_3V3: Q4.3 (D); also elsewhere on the board
VCC_TARGET_USB_5V: D3.A; also elsewhere on the board
VCC_TRNG_3V3: Q3.3 (D); also elsewhere on the board


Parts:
C29, C40, C41, C42, C43: 100nF; C0603
R37: 4.7K; 0603-RES
U8: SI7021
U10: ISL29035
U11: FX0S8700CQ; QFN16_3,5

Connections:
ACC_INT1: U11.11 (INT1); also elsewhere on the board
ACC_INT2: U11.9 (INT2); also elsewhere on the board
GND: C29.2, C40.2, C41.2, C42.2, C43.2, U8.2 (GND), U10.2 (GND), U11.3 (GND), U11.5 (GND), U11.7 (SA0/MISO), U11.10 (SA1/!CS), U11.12 (GND), U11.13 (GND), U11.16 (RST); also elsewhere on the board
LIGHT_!INT: R37.1, U10.4 (!INT); also elsewhere on the board
unnamed: C41.1, U11.8 (CRST)
unnamed: C42.1, U11.2 (BYP)
TWI2_SCL: U8.6 (SCL), U10.5 (SCL), U11.4 (SCL/SCK); also elsewhere on the board
TWI2_SDA: U8.1 (SDA), U10.6 (SDA), U11.6 (SDA/MOSI); also elsewhere on the board
VCC_SENSE_3V3: C29.1, C40.1, C43.1, R37.2, U8.3 (VDD), U8.4 (VDD), U8.5 (VDD), U10.1 (VDD), U11.1 (VDDIO), U11.14 (VDD); also elsewhere on the board


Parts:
C7, C44, C46, C47: 0.47uF; C0603
C11: 22pF; C0603
C45: DNP; C0603
C48: 4.7uF; C0603
C49: 10uF; PANASONIC_C
D1, D4: DIODE-ZENERPTH; DIODE-ZENER; MPN 610-1N759A
D5, D6: MBR0530; SOD-123
L3: 10uH; 0805
R9, R10, R13, R30: 10K; 0603-RES
R11, R12: DNP; 0603-RES
R14: 2.2M; 0603-RES
R15: 160K; 0603-RES
SJ6: SOLDERJUMPERNO; SJ_2S-NO
U3: TLV3202; SO8
U4: LM358; SO8
U12: 296-12686-1-ND; SOT23-5

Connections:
GND: C7.2, C44.2, C45.2, C46.2, C47.2, C48.2, C49.-, D5.C, R9.1, R12.1, R13.1, R15.1, R30.1, U3.4 (V-), U4.4 (V-), U12.2 (GND); also elsewhere on the board
unnamed: D6.A, L3.1, U12.1 (SW)
unnamed: C11.2, R14.1, R15.2, U12.3 (FB)
unnamed: D1.P$1 (C), U4.1 (OUT)
unnamed: D4.P$1 (C), U4.7 (OUT)
unnamed: C45.1, C46.1, D5.A, R10.1, U4.3 (IN+), U4.5 (IN+)
NOISE1: D1.P$2 (A), R9.2, U3.3 (IN+), U4.2 (IN-)
NOISE2: D4.P$2 (A), R13.2, U3.2 (IN-), U4.6 (IN-)
TRNG_EN: R30.2, SJ6.1, U12.4 (EN); also elsewhere on the board
TRNG_OUT: U3.1 (OUT); also elsewhere on the board
VCC_TRNG_3V3: C44.1, C48.1, L3.2, SJ6.2, U3.8 (V+), U12.5 (VIN); also elsewhere on the board
VHIGH: C7.1, C11.1, C47.1, C49.+, D6.C, R10.2, R11.2, R14.2, U4.8 (V+)
VHIGHSAMPLE: R11.1, R12.2



Board: 4 copper layers, 87.0 x 102.5 mm, 151 parts (20 on the bottom side), 131 nets.

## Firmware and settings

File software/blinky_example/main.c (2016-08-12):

#include "sys.h"
#include "gpio.h"

void main(void);

typedef void(* const isr_vector)(void);

isr_vector __attribute((section(".vectors"))) vector_table[] = 
{
    (isr_vector)&__stack_end, // Initial SP
    (isr_vector)&main,        // Initial PC
    &general_purpose_handler, // NMI
    &general_purpose_handler, // Hard fault
    &general_purpose_handler, // Mem manage
    &general_purpose_handler, // Bus fault
    &general_purpose_handler, // Usage fault
    0, 0, 0, 0,
    &general_purpose_handler, // SVC handler
    &general_purpose_handler, // Debug monitor
    0,
    &general_purpose_handler, // Pend SVC 
    &sys_tick_handler,        // SysTick
};

void main(void)
{
    init_sys();

    gpio_enable(PC10);

    while (1)
    {
        putstr("Toggling");
        gpio_toggle(PC10);
        wait(500); // ms
    }
}

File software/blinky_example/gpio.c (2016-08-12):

#include "gpio.h"
#include "bits.h"

#define GPIO_BASE 0x400E1000
#define GPIO_PORTSZ    0x200
#define GPIO_GPER_OFFS 0x000
#define GPIO_GPCR_OFFS 0x008
#define GPIO_ODER_OFFS 0x040
#define GPIO_OVR_OFFS  0x050
#define GPIO_PMR0_OFFS 0x010
#define GPIO_PMR1_OFFS 0x020
#define GPIO_PMR2_OFFS 0x030

void gpio_enable(int gpio)
{
    int port = gpio / 32;
    int pin = gpio % 32;

    int port_base = GPIO_BASE + port * GPIO_PORTSZ;
    int gper = port_base + GPIO_GPER_OFFS;
    int oder = port_base + GPIO_ODER_OFFS;

    volatile int *gper_reg = (volatile int *)gper;
    volatile int *oder_reg = (volatile int *)oder;

    *gper_reg = setb(*gper_reg, pin);
    *oder_reg = setb(*oder_reg, pin);
}

void gpio_set_value(int gpio, char value)
{
    int port = gpio / 32;
    int pin = gpio % 32;

    int port_base = GPIO_BASE + port * GPIO_PORTSZ;
    int ovr = port_base + GPIO_OVR_OFFS;

    volatile int *ovr_reg = (volatile int *)ovr;

    if (value)
    {
        *ovr_reg = setb(*ovr_reg, pin);
    }
    else
    {
        *ovr_reg = clrb(*ovr_reg, pin);
    }
}

void gpio_toggle(int gpio)
{
    int port = gpio / 32;
    int pin = gpio % 32;

    int port_base = GPIO_BASE + port * GPIO_PORTSZ;
    int ovr = port_base + GPIO_OVR_OFFS;

    volatile int *ovr_reg = (volatile int *)ovr;

    *ovr_reg = flpb(*ovr_reg, pin);
}

void gpio_set_peripheral_function(int gpio, int fn)
{
    int port = gpio / 32;
    int pin = gpio % 32;

    int port_base = GPIO_BASE + port * GPIO_PORTSZ;
    int gpcr = port_base + GPIO_GPCR_OFFS;

    volatile int *gpcr_reg = (volatile int *)gpcr;

    *gpcr_reg = setb(*gpcr_reg, pin);

    int pmr0 = port_base + GPIO_PMR0_OFFS;
    int pmr1 = port_base + GPIO_PMR1_OFFS;
    int pmr2 = port_base + GPIO_PMR2_OFFS;

    volatile int *pmr0_reg = (volatile int *)pmr0;
    volatile int *pmr1_reg = (volatile int *)pmr1;
    volatile int *pmr2_reg = (volatile int *)pmr2;

    if (is_set(*pmr0_reg, pin))
    {
        *pmr0_reg = setb(*pmr0_reg, pin);
    }
    else
    {
        *pmr0_reg = clrb(*pmr0_reg, pin);
    }

    if (is_set(*pmr1_reg, pin))
    {
        *pmr1_reg = setb(*pmr1_reg, pin);
    }
    else
    {
        *pmr1_reg = clrb(*pmr1_reg, pin);
    }

    if (is_set(*pmr2_reg, pin))
    {
        *pmr2_reg = setb(*pmr2_reg, pin);
    }
    else
    {
        *pmr2_reg = clrb(*pmr2_reg, pin);
    }
}

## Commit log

2016-05-18 Add initial imix schematic
    [imix.sch]
2016-05-18 Add PDF of initial schematic
2016-06-20 Model-T imix, midway complete
    [imix.brd, imix.sch]
2016-06-20 More routing in lower right quadrant
    [imix.brd]
2016-06-29 Progress on routing
    [imix.brd, imix.sch]
2016-06-30 Fully routed and some silkscreen finished
    [imix.brd, imix.sch]
2016-07-03 Top silkscreen nearly complete
    [imix.brd, imix.sch]
2016-07-03 Fix most assembly issues
    [imix.brd, imix.sch]
2016-07-05 Fix reset connection to FTDI
    [imix.brd, imix.sch]
2016-07-05 Update component naming for consistency
    [imix.brd, imix.sch]
2016-07-12 Prototype ready for final review and manufacture
    [imix.brd, imix.sch]
2016-07-13 Update docs
    [imix.sch]
2016-07-13 Move MCU SWD to be accessible when a shield is present
    [imix.brd, imix.sch]
2016-07-13 Update assembly drawings to match repositioned MCU SWD
2016-07-13 Correct USB mislabelling in assembly drawing
2016-07-23 Refactor RNG
    [imix.brd, imix.sch]
2016-07-25 Updated version incorporating several suggestions, still rerouting RNG
    [imix.brd, imix.sch]
2016-07-25 Rearranged RNG
    [imix.brd]
2016-07-26 DFM is almost passing
    [imix.brd, imix.sch]
2016-07-27 Prototype design for v1.0 submitted to fab
    [imix.brd, imix.sch, imix_pick_and_place.xlsx]
2016-08-24 Upload BOM
    [imix_v1_june_2016_bom.xls]
2016-08-24 Move bom into v1 folder
    [bom.xls]
2016-10-30 Update repo with revision 1.1 and 1.2
    [bom_v1_1.xls, bom_v1_2.xls, imix.brd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]
2016-10-31 Change to NRF51422
    [bom_v1_2.xls]
2016-10-31 All files for assembly/fab
2016-11-14 Updated imix.brd--current with v1.2 Oct 2016
    [imix.brd]
2016-11-14 Updated BOM to include NRF51422 replacement
    [bom_v1_2.xls]
2016-11-17 Imix lbr includes devices, packages, and symbols now (earlier version only had packages)
2016-11-18 Improve schematic readability and update PDF docs: Fixes #10
    [imix.brd, imix.sch]
2016-11-18 Update misc manufacturing files
    [imix_cpl.xlsx]
2016-11-18 Connect SAM4L pin 8 and 97 to VDDIO and reduce RNG ground plane: addresses #7 and #9
    [imix.brd]
2017-02-06 Directory restructure
    [bom.xls, bom_v1_1.xls, bom_v1_2.xls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]
2017-02-06 Include CAM files from first revisions
    [bom.xls, bom_v1_1.xls]
2017-02-06 Update to most recent changeset for 1.3
    [imix.brd]
2017-02-06 Add 1K resistor b/n FTDI DTR and RESET. Closes #15
    [bom_v1_3.xls]
2017-02-20 Fix power bugs and other issues in schematic
    * Set EN1 on the battery charger to VCC
    * Replaced the PMOS load switches with SIP32041As
    * Added isolation for the I2C and the RF233 SPI busses
    * Connected the I2C pullups to VCC_MCU, not VCC_SENSE
    * Added resistor between FTDI DTR and RESET (previous commit)
    * Moved power sense headers logically inward towards their power domains
    [bom_v1_3.xls, imix.brd, imix.sch]
2017-02-20 Create PDF
    [imix.brd, imix.sch]
2017-02-20 Correct 1K resistor quantity in BOM
    [bom_v1_3.xls]
2017-03-06 Eliminated FabDoc layers and migrated all components to imix library
    [imix.brd, imix.sch]
2017-03-10 Only 19 airwires to go
    [imix.brd]
2017-03-10 Down to 6 airwires
    [imix.brd]
2017-03-10 Down to 3 airwires
    [imix.brd]
2017-03-10 No airwires. Need to run DRC and generate documentation
    [imix.brd]
2017-03-11 Passes DRC
    [imix.brd, imix.sch]
2017-03-11 Rearranged analog pins according to #16
    [imix.brd, imix.sch]
2017-03-12 Correct ADC numbering in doc. Closes #16
    [imix.brd, imix.sch]
2017-03-12 Fab/assembly documentation for v1.3
    [bom_v1_3.xls, imix.brd, imix.sch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]
2017-04-28 Attempts to fix mirrored footprints
    [breakout.brd, breakout.sch, imix.brd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]
2017-05-10 One analog switch and all power switches routed
    [imix.brd]
2017-05-10 All elements routed, DRC passes
    [imix.brd]
2017-05-10 Update imix v2.0 schematic pdf
2017-05-10 Update imix v2.0 schematic
    [imix.sch]
2017-07-05 v2.0 quick batch
    [bom_v2_0.xls, imix.brd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]
2017-09-05 imix v2.1 design and documentation
    v2.1 changes:
    * Form factor: now a 2.5"X4" rectangle
    * Removed battery circuit
    * FTDI chip powered correctly for low power
    * Removed unnecessary resistors
    * Renumbered some resistors and capacitors
    * Changed pull-ups to 10K from 4.7K
    * Removed unnecessary battery charger IC
    * Removed all power gates except TRNG
    * Removed header 1 and reassigned pins to the other headers
    * Shunts instead of cutting traces
    * Rearranged pinout on headers to simplify layout
    * JST battery connector instead of battery clips
    * Minor pinout changes on the MCU
    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
    [bom.xls, bom_v2_1.xls, imix.brd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]
2017-09-06 Update documentation and fix silkscreen error v2.1
    [imix.brd, imix.sch]
2017-09-06 Add OSHW logo to silkscreen
    [imix.brd]
2023-03-02 update submodule to fix svc error on new arm compilers

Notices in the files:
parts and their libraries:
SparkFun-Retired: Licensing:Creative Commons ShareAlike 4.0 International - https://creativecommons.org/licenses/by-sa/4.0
